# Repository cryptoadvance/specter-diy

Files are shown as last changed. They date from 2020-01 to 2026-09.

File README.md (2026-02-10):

# Specter-DIY

    "Cypherpunks write code. We know that someone has to write software to defend privacy, 
    and since we can't get privacy unless we all do, we're going to write it."
    A Cypherpunk's Manifesto - Eric Hughes - 9 March 1993

    ...and Cypherpunks do build their own Bitcoin Hardware Wallets.

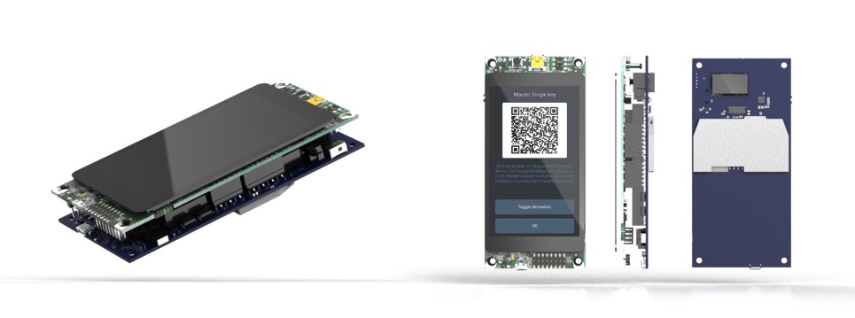
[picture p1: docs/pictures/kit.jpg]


The idea of the project is to build a hardware wallet from off-the-shelf components.
Even though we have [an extension board](./shield) that puts everything in a nice form-factor and helps you to avoid any soldering, we will continue supporting and maintaining compatibility with standard components.

We also want to keep the project flexible such that it can work on any other set of components with minimal changes. Maybe you want to make a hardware wallet on a different architecture (RISC-V?), with an audio modem as a communication channel - you should be able to do it. It should be easy to add or change functionality of Specter and we try to abstract logical modules as much as we can.

QR codes are a default way for Specter to communicate with the host. QR codes are pretty convenient and allow the user to be in control of the data transmission - every QR code has a very limited capacity and communication happens unidirectionally. And it's airgapped - you don't need to connect the wallet to the computer at any time.

For secret storage we support agnostic mode (wallet forgets all secrets when turned off), reckless mode (stores secrets in flash of the application microcontroller) and secure element integration is coming soon.

Our main focus is multisignature setup with other hardware wallets, but wallet can also work as a single signer. We try to make it compatible with Bitcoin Core where we can - PSBT for unsigned transactions, wallet descriptors for importing/exporting multisig wallets. To communicate with Bitcoin Core easier we are also working on [Specter Desktop app](https://github.com/cryptoadvance/specter-desktop) - a small python flask server talking to your Bitcoin Core node.

Most of the firmware is written in MicroPython which makes the code easy to audit and change. We use [secp256k1](https://github.com/bitcoin-core/secp256k1) library from Bitcoin Core for elliptic curve calculations and [LVGL](https://lvgl.io/) library for GUI.

## DISCLAIMER

The project has significantly matured, to the extent that the security level of Specter-DIY is now comparable to commercial hardware wallets on the market. We implemented a secure bootloader that verifies firmware upgrades, so you can be sure that only signed firmware can be uploaded to the device after initial setup. However, unlike with commercial signing devices the bootloader has to be installed manually by the user and is not set in the factory of the device vendor. Thus, pay extra attention during the initial firmware installation and make sure you verified PGP signatures and flash the firmware from a secure computer.

If something doesn't work open an issue here or ask a question in our [Telegram group](https://t.me/+VEinVSYkW5TUl5Ai).

## Documentation

All the docs are stored in the [`docs/`](./docs) folder:

- [`shopping.md`](./docs/shopping.md) explains what to buy
- [`assembly.md`](./docs/assembly.md) shows how to put everything together.
- [`quickstart.md`](./docs/quickstart.md) guides you through the initial steps how to get firmware on the board
- [`reproducible-build.md`](./docs/reproducible-build.md) describes how to build the initial firmware and upgrade files with the same hash as in the release using Docker
- [`build.md`](./docs/build.md) describes how to build the firmware and the simulator yourself
- [`security.md`](./docs/security.md) explains possible attack vectors and security model of the project
- [`development.md`](./docs/development.md) explains how to start developing on Specter
- [`simulator.md`](./docs/simulator.md) shows how to run a simulator on unix/macOS
- [`communication.md`](./docs/communication.md) defines communication protocol with the host over QR codes and USB
- [`roadmap.md`](./docs/roadmap.md) explains what we need to implement before we can consider the wallet be ready to use with real funds.

Specter-Shield documentation and all the files are available in the [`shield/`](./shield) folder:

- [What it looks like](./shield/README.md)
- [How to print a 3d case](./shield/3dprinting.md)

Specter Shield-Lite documentation is available in the [`shield-lite/`](./shield-lite) folder:

- [Specter Shield-Lite overview](./shield-lite/readme.md)

Supported networks: Mainnet, Testnet, Regtest, Signet.

## Running tests

The unit test suite runs on the Unix simulator build. Install the required
system packages and then run the `make` target:

```
sudo apt-get update
sudo apt-get install libsdl2-dev libffi-dev pkg-config libreadline-dev libgmp-dev build-essential python3
make test
```

The build system will fetch the necessary submodules and compile the simulator
before executing the tests.

## USB communication on Linux

You may need to set up udev rules and add yourself to `dialout` group. Read more in [`udev`](./udev/README.md) folder.

## Video and screenshots

Check out [this video](https://www.youtube.com/watch?v=1H7FqG_FmCw) to get an idea how to assemble it and how it works.

Here is a [Gallery](./docs/pictures/gallery/README.md) with devices assembled by the community.

A few pictures of the UI:

### Wallet screens

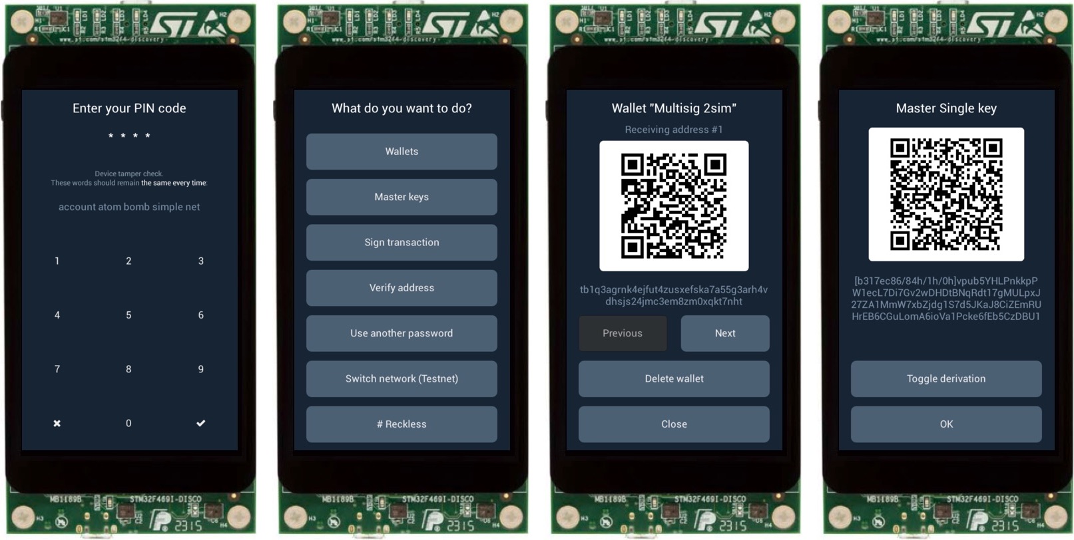
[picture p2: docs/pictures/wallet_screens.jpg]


### Key generation and recovery

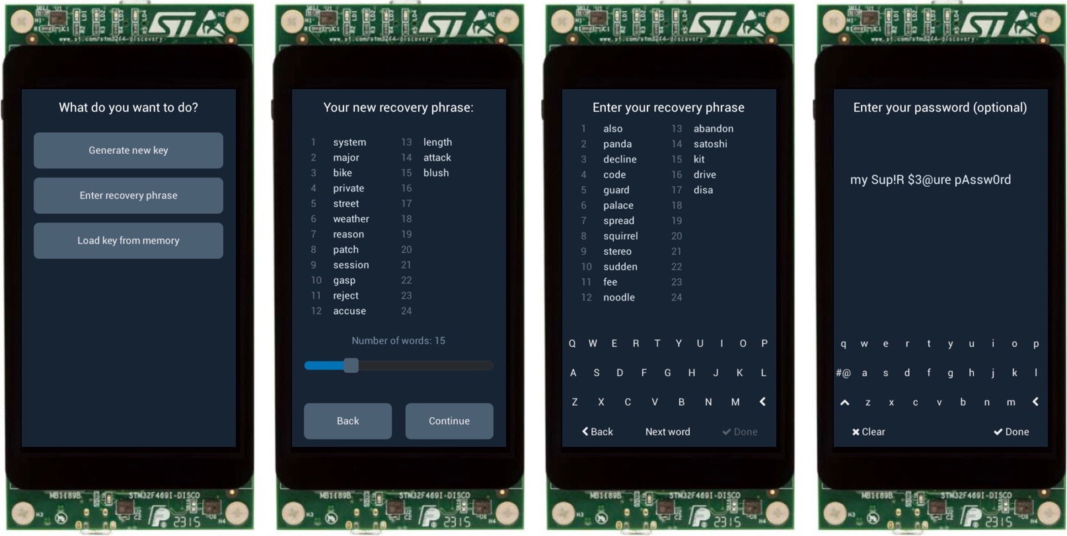
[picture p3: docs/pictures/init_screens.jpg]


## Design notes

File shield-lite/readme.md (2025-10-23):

# Specter Shield Lite (Work in Progress)

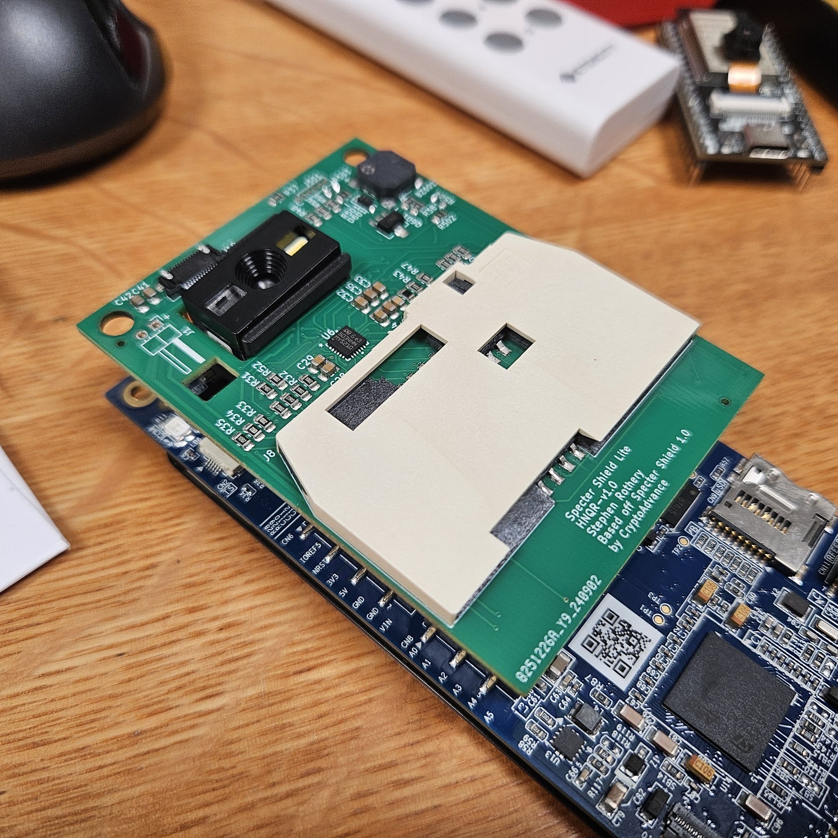
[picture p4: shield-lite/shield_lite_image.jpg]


## Background
Limited availability and high cost have limited the accesibility of the Smartcard based functionality in Specter.

## The Specter Shield-Lite aims to:
+ Implement the QR and Smartcard functionality of the Specter Shield, at a price that is comparable to using the Waveshare QR Scanner for Specter DIY.
+ Preserve the form factor of the Shield to allow re-use of existing cases.
+ Optimise the PCB design and component selection for low cost, short-run production where full hand-assembly is also practical with a standard soldering iron if desired. 
+ Not worry about an integrated battery, but expose the VIN pin so that the user can supply 6-9DC if they want, or just power over USB.
+ Use FOSS design tools (KiCad) to make it easier for others to contribute to the project

## Design Decisions to keep costs low
+ PCB Size - Exceeding 10cm in either dimension typically results in increased costs with most PCB production houses
+ 2 Layer PCB - Double sided PCBs are extremly cheap when compared to 4 layer boards. This is also a fairly simple board, so 2 layer is fine.
+ Keeping all drilled hole sizes above 0.3mm... The existing Shield has a handful (~6) of 0.2mm holes which dramatically increases the production cost.
+ Single Sided Components - Fab houses like JLCPCB have extremely cheap assembly services as long as all components are on a single side of the PCB. (The Pin-Headers are easy to hand solder on)
+ Sticking to common/cheap components where possible, as opposed to more exotic/complex parts. (Minimise 'Extended' parts from fabs like JLCPCB, prefer pin-count <= 16 for fabs like PCBWay)

## Future Work (Still in testing)
+ Swap SmartCard interface IC to something like ST8034ATDT to make it easier to assemble by hand, decreases component count and makes assembly cheaply by PCBWay. (Current QFP package makes assembly expensive with PCBWay, though still cheap with JLCPCB)
+ Look at alternative QR Scanners like the Grow GM805 which are cheaper, remove the need for fine pitch header soldering and also integrate the beeper, to futher drive costs down. (Currently has some compatability issues with binary SeedQR which need to be explored/fixed)

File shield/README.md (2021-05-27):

# Specter Shield

Specter shield is an extension board for F469-Discovery board by STMicroelectronics. It uses a standard Arduino headers so it might work with other boards with Arduino headers as well.

It includes a QR scanner, smartcard slot and a battery. All elements are not security-critical - QR scanner only captures images and sends scanned data to the main MCU over dead-simple serial interface, smartcard controller learns nothing about the data transmitted to the secure element as communication with it is encrypted.

Structure diagram, pinout and schematics are available in this folder and on [circuitmaker](https://circuitmaker.com/Projects/Details/MikhailTolkachev/specter-shield). To manufacture the kit yourself just send the content of the [`specter-shield`](./specter-shield/) folder to the PCB manufacturer.

For the QR scanner we use GROW GM65-S scanner.

Available in [our shop](https://specter.solutions/shop/specter-shield/). Assembled kit look like this:

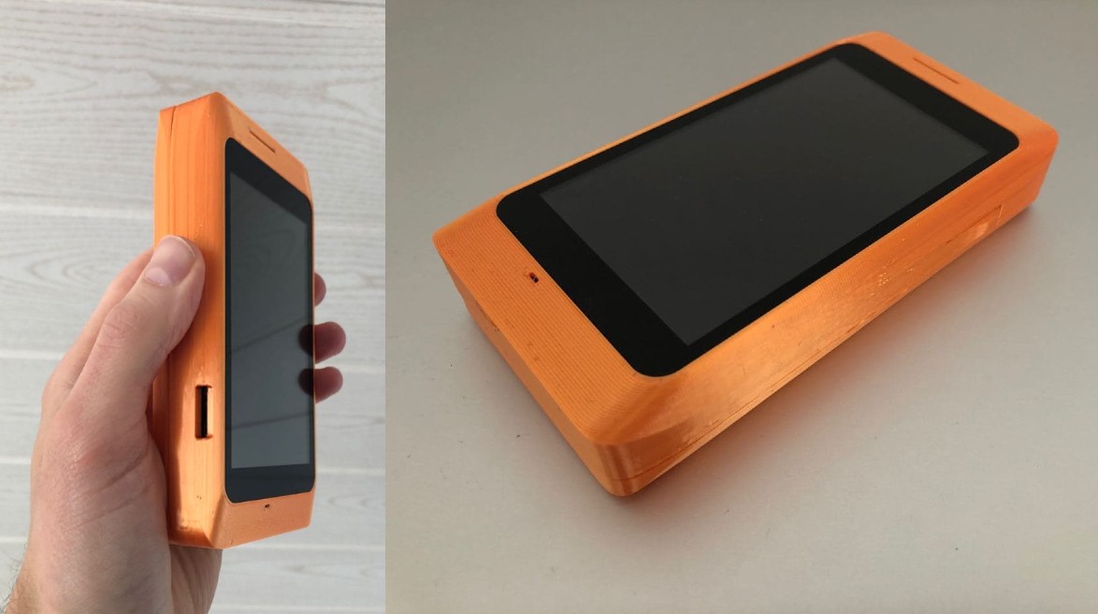
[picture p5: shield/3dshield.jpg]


## Print the case for Specter-DIY + Shield:

- Design by @geometrick-design: https://www.thingiverse.com/thing:4671552, [instructions](3dprinting.md)
- Design by @SeedSigner: https://www.thingiverse.com/thing:4733846, [files and instructions](./Alternative_3D_Printed_Case)

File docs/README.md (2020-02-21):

# Documentation

## Table of contents

- [`shopping.md`](./shopping.md) explains what to buy
- [`assembly.md`](./assembly.md) shows how to put everything together.
- [`quickstart.md`](./quickstart.md) guides you through the initial steps how to get firmware on the board
- [`security.md`](./security.md) explains possible attack vectors and security model of the project
- [`development.md`](./development.md) explains how to start developing on Specter
- [`simulator.md`](./simulator.md) shows how to run a simulator on unix/macOS
- [`communication.md`](./communication.md) defines communication protocol with the host over QR codes and USB
- [`roadmap.md`](./roadmap.md) explains what we need to implement before we can consider the wallet be ready to use with real funds.

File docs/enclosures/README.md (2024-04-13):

# Enclosures for Specter-DIY

There are a few case designs made by the community:

## Specter-DIY Snap Case

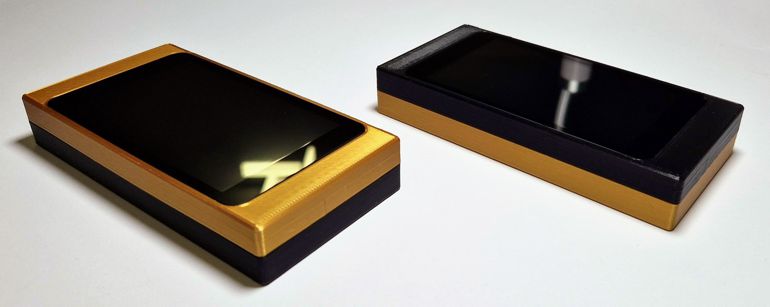
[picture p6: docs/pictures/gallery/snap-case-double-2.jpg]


Print it yourself enclosure with the waveshare scanner on the backside. 

The printable STL files are available for download in the [snapcase](./snapcase/) folder.

Please note that the prints are quite tight around the hardware components. They are well tested with a Prusa MK3s and Specter hardware components from late 2022. Other printers or newer or older hardware may produce results that do not fit. Please check carefully that the prints do not exert pressure on any hardware components and don't exert any pressure yourself. 

Contact me if you have any questions or suggestions. Success stories are also very welcome. :) You can reach me on [X (@kayth21)](https://x.com/kayth21) or on [Telegram (@kayth_21)](https://t.me/kayth_21).

You can also buy a Snap Case, or a fully assembled Specter-DIY, from [bitcoin-store.org](https://bitcoin-store.org).

## SeedSigner's "Barebones" enclosure, v2

Updated design from @SeedSigner (Twitter/Telegram) with a smaller form factor & MicroSD access.

The printable .STL files for v1 and v2 are available for download from the [docs/enclosures/seedsigner](./seedsigner/) folder.

You can also buy the v2, or a fully assembled Specter-DIY, from [his shop](https://btc-hardware-solutions.square.site/).

(E.U. residents can contact @surfacePlasmon (Twitter) or @daz21 (Telegram) to purchase an enclosure via mail or visit diynodes.com)

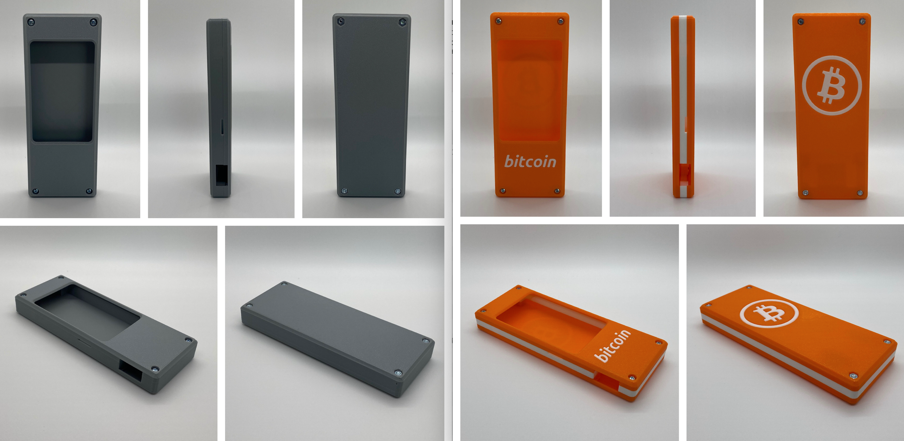
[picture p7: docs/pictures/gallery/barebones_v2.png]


## Full metal DIY

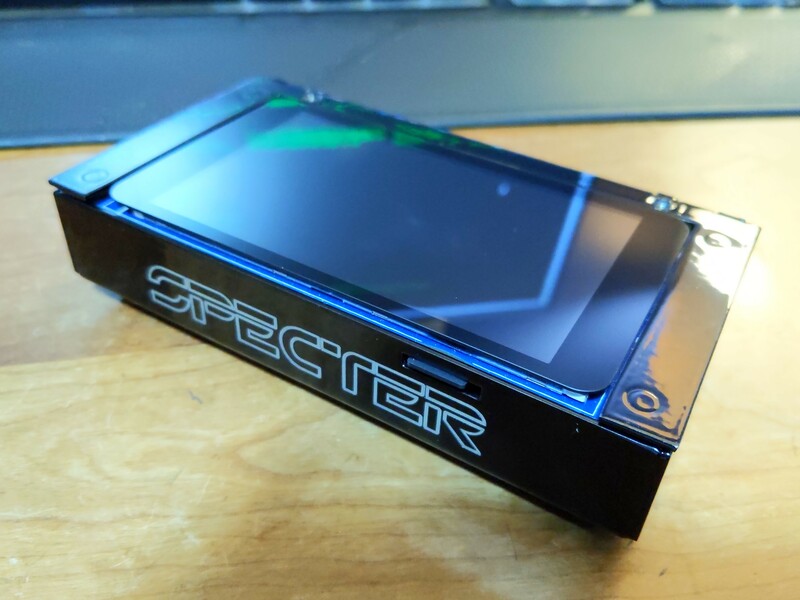
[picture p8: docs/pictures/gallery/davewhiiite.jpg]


https://github.com/davewhiiite/wraith

## Enclosure by Thomas

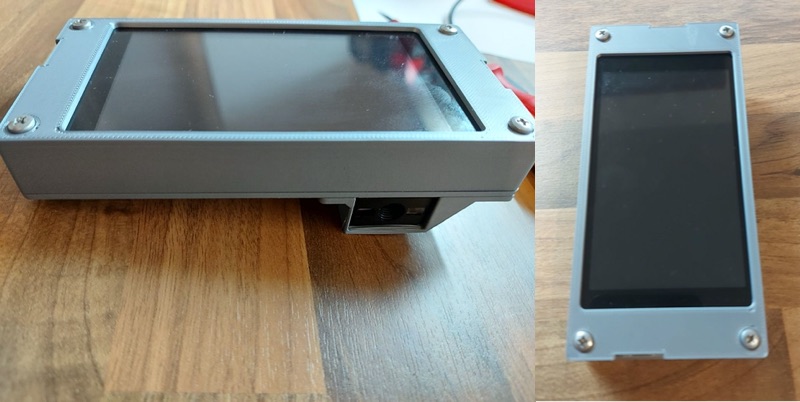
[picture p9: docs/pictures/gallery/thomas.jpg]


[3d files](./thomas)

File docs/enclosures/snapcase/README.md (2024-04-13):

# Specter-DIY Snap Case

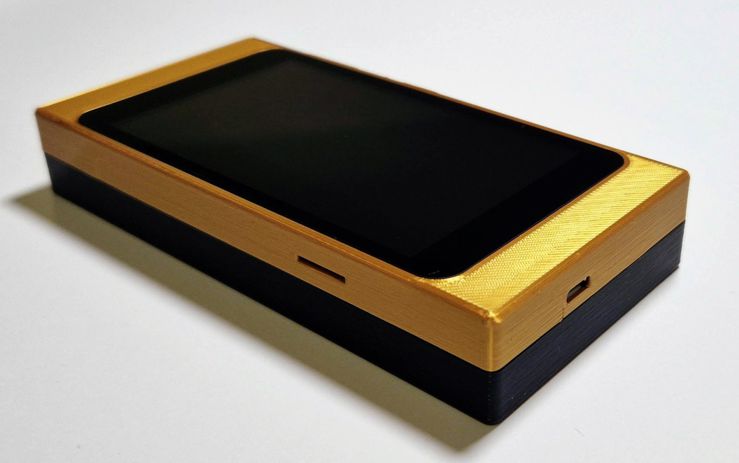
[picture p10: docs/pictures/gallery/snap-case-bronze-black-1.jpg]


Specter-DIY Snap Case is a print it yourself enclosure with the waveshare scanner on the backside. It consists of a scanner part, in which the scanner is held and the cables are fixed, and a frontside and a backside part, which can be plugged together. 

## Please note

The prints are quite tight around the hardware components. They are well tested with a Prusa MK3s and Specter hardware components from late 2022. Other printers or newer or older hardware may produce results that do not fit. Please check carefully that the prints do not exert pressure on any hardware components and don't exert any pressure yourself. 

## Assembly

Please note that this manual assumes that you are familiar with the basic assembly of a Specter-DIY and therefore only addresses the specialties associated with this case. If not, please head over to the [docs](../../).

### Print all the parts

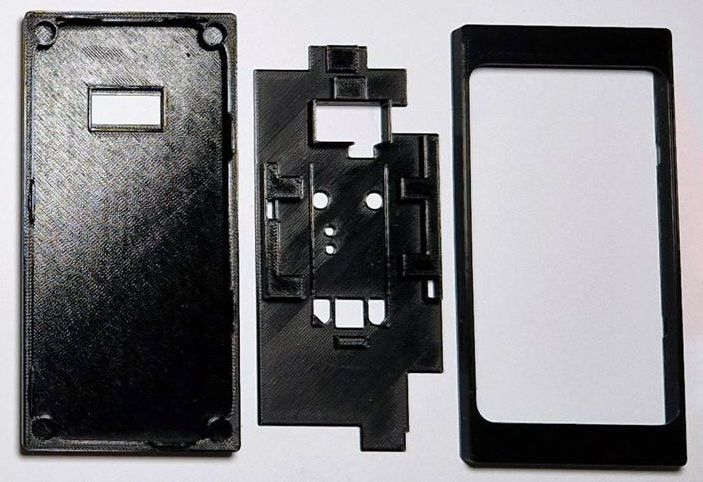
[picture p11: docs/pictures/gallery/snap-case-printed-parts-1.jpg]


- The SDL files are attached to this site. 

### Remove all screws from the scanner

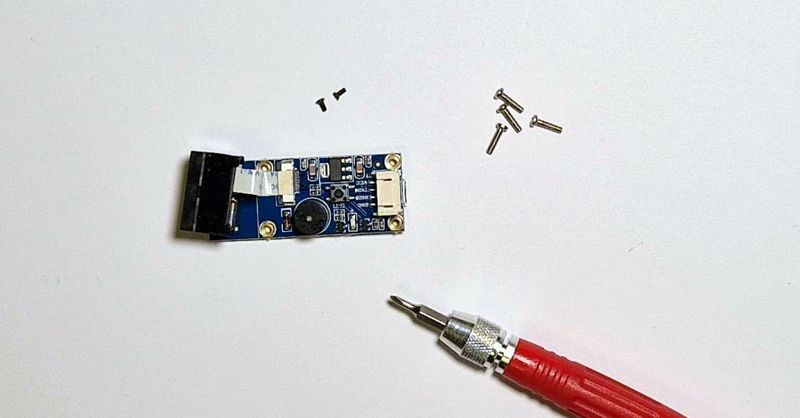
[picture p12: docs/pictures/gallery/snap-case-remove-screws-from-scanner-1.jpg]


### Mount the scanner module

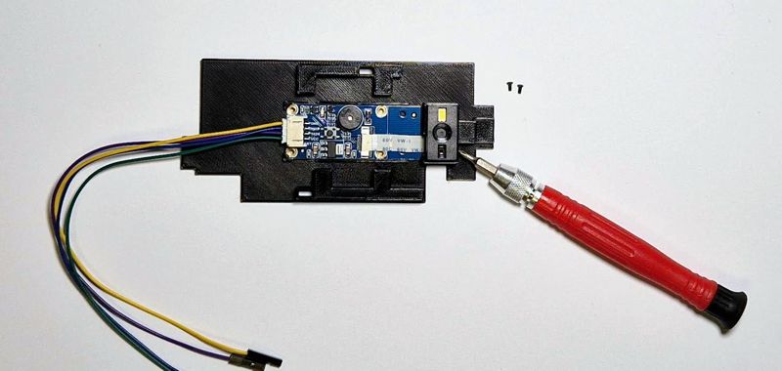
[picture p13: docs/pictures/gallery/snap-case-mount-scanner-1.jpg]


- Use the two small screws to lock the scanner in the designated position.

### Connect the scanner to the board

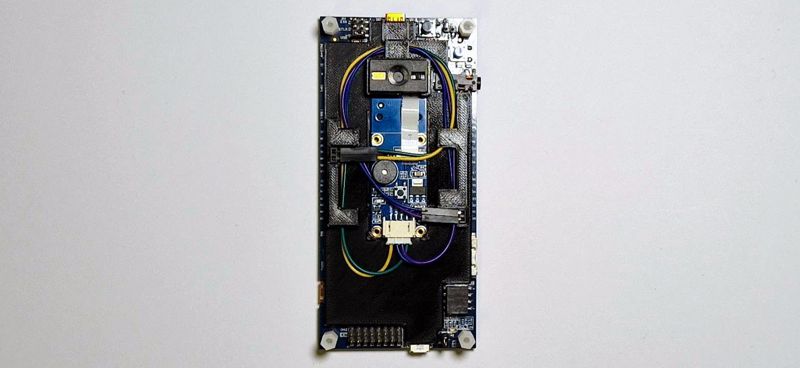
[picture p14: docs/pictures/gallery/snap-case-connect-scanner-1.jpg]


- Place the middle part on the board.
- Slide the cables through the channels.
- Connect the cables through the pins to the corresponding slots.

### Plug together the case

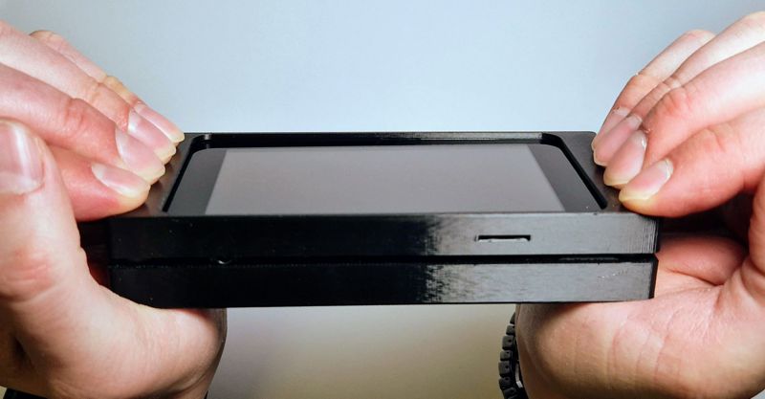
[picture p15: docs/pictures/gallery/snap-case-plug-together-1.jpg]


- Please double check that the parts are right side up.
- Because of the snaps, you need a little pressure to put them together. Before you put them together, please make sure that the top part fits well over the display.

## Contact

Contact me if you have any questions or suggestions. Success stories are also very welcome. :) You can reach me on [X (@kayth21)](https://x.com/kayth21) or on [Telegram (@kayth_21)](https://t.me/kayth_21).

## Shop

You can also buy a Snap Case, or a fully assembled Specter-DIY, from [bitcoin-store.org](https://bitcoin-store.org).

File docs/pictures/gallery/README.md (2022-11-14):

# Gallery

Here are a few pictures from people who assembled their own Specter.

If you did it as well we will be happy to put it here.

### @kayth21

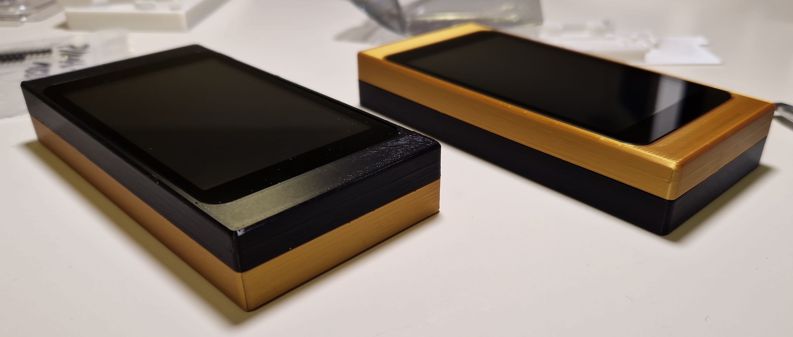
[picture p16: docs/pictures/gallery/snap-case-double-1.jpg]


Created with a Prusa MK3s using the template from [enclosures/snapcase](../../enclosures/snapcase).

### @davewhiiite

davewhiiite

### @seedsigner

seedsigner

### @lunaticoin

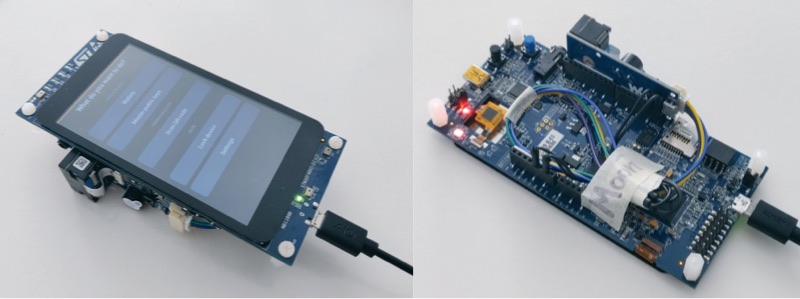
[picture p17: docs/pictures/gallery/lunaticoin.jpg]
lunaticoin


### @Thomas1378

thomas

### @bitcoinheiro

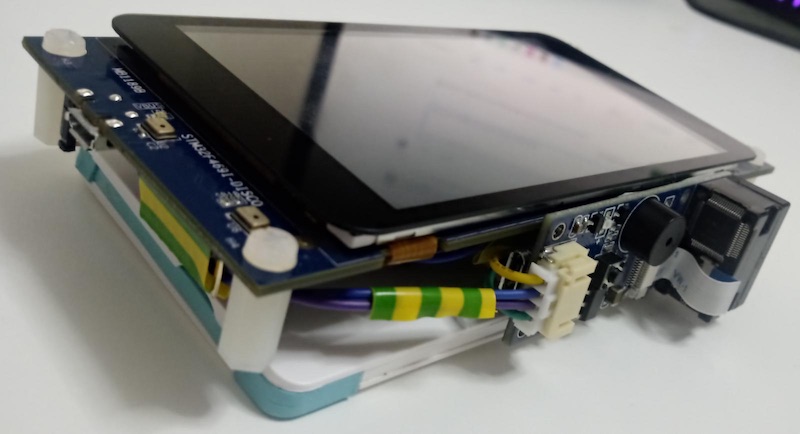
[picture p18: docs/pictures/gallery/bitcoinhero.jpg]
bitcoinhero


Created 3d printed storage box for this setup with small battery attached and waveshare scanner on the side. Available at https://www.tinkercad.com/things/46xyXAhv0Fy

### @kkdao

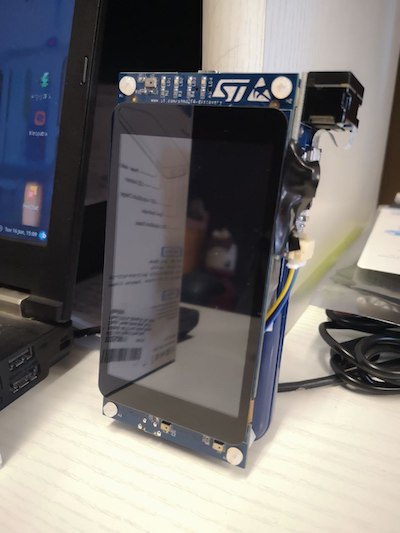
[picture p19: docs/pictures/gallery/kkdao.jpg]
kkdao


### @dimaatmelodromru

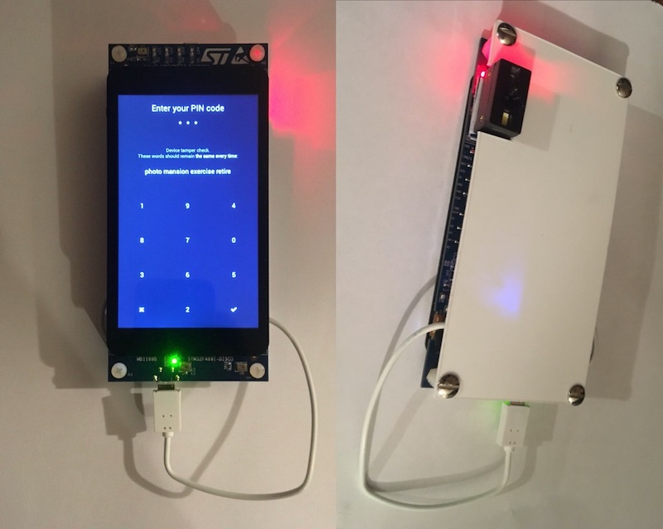
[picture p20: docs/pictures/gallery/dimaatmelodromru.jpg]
dimaatmelodromru


### @k9ert

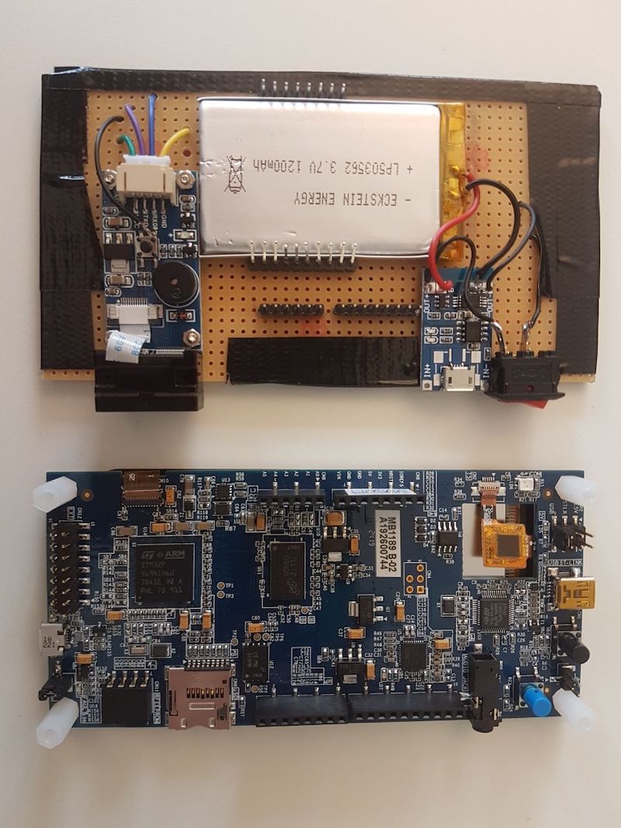
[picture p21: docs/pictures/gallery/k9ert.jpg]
k9ert


### @gorazdko

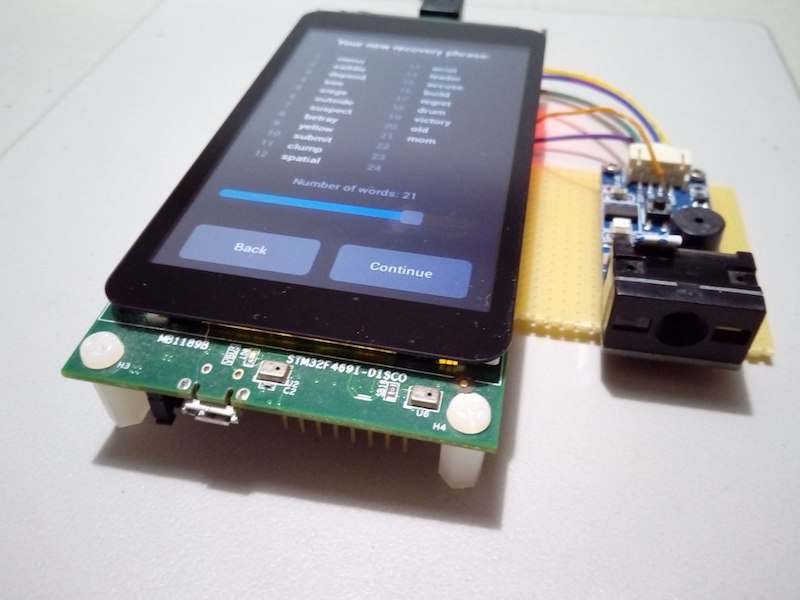
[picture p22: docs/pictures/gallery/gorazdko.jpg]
gorazdko


### @bavarianledger

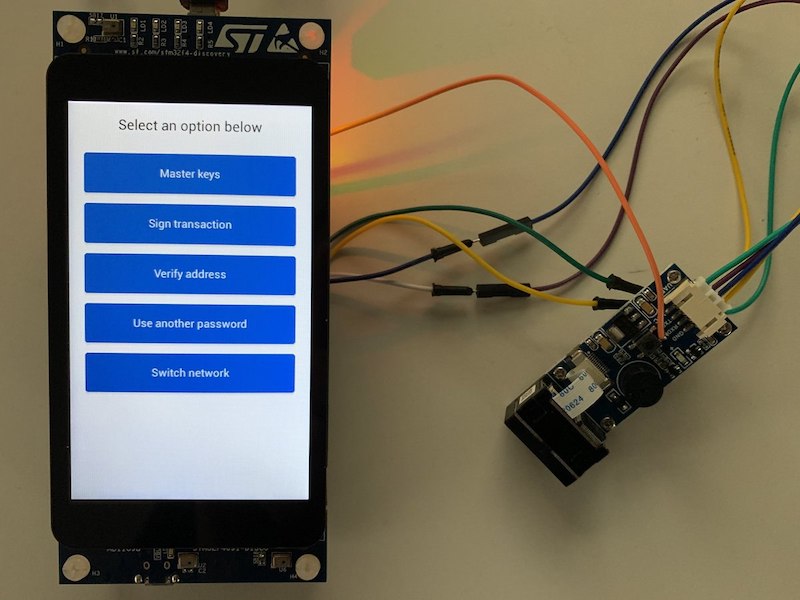
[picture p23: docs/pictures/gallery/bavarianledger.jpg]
bavarianledger


### @kdmukai

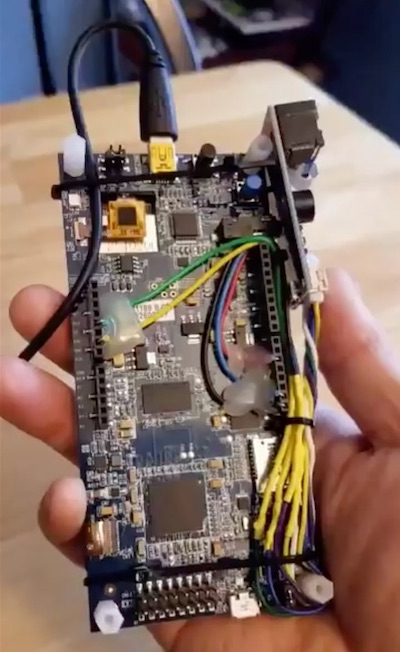
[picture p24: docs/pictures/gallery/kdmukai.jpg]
kdmukai


### @stepansnigirev

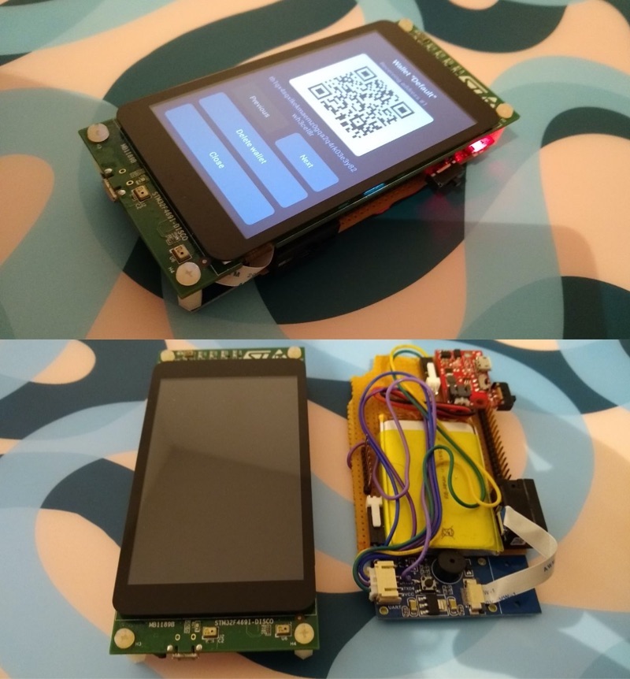
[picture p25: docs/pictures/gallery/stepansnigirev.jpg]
stepansnigirev


### @davewhiiite

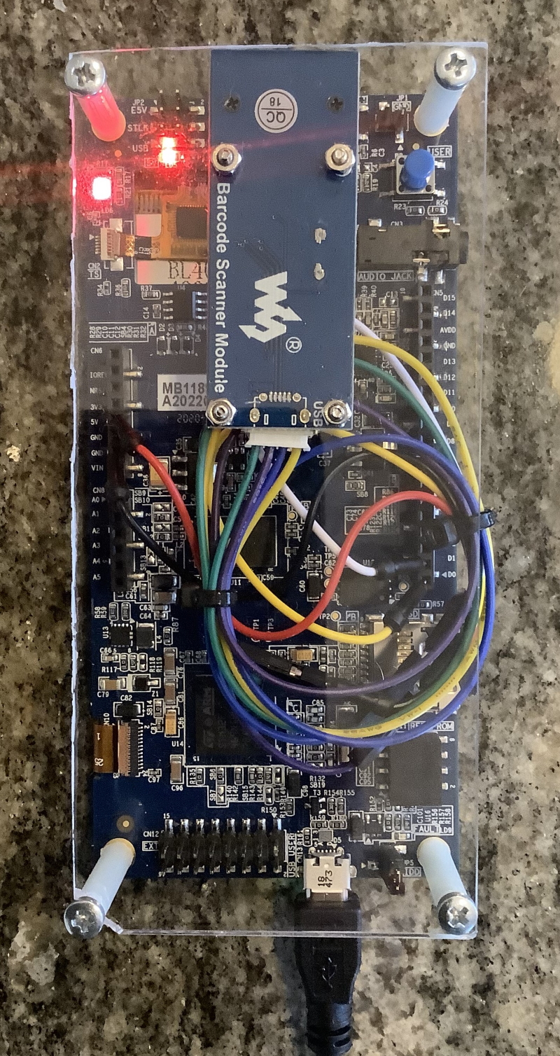
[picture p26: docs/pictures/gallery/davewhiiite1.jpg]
davewhiiite

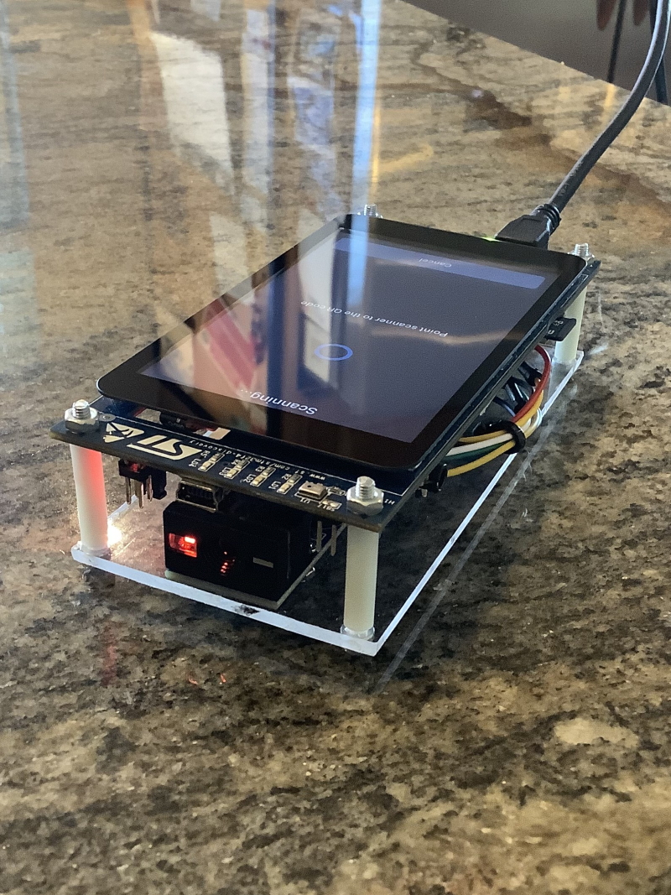
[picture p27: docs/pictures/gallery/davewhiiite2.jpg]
davewhiiite

davewhiiite

### Re-use the original packaging of the STM32F469I-DISCO @henrik
henrik
henrik
henrik

### @you?

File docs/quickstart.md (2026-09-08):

# Installing the compiled code

With the secure bootloader initial installation of the firmware is slightly different. Upgrades are easier and don't require to connect hardware wallet to the computer.

## Flashing initial firmware

**Note** If you don't want to use binaries from the releases check out the [bootloader documentation](https://github.com/cryptoadvance/specter-bootloader/blob/master/doc/selfsigned.md) that explains how to compile and configure it to use your public keys instead of ours.

- If you are upgrading from versions below `1.4.0` or uploading the firmware for the first time, use the `initial_firmware_<version>.bin` from the [releases](https://github.com/cryptoadvance/specter-diy/releases) page.
	- Verify the signature of the `sha256.signed.txt` file. The signing key varies by release, see the release notes; as of v1.10.5 it is signed by Mike Tolkachev (@miketlk), fingerprint `F2DB C4C6 14C1 13E2 B15F 879A DD5C 1264 EBD6 45BE`, key at [github.com/miketlk.gpg](https://github.com/miketlk.gpg) (see [SECURITY.md](https://github.com/cryptoadvance/specter-diy/blob/master/SECURITY.md)). v1.10.3–v1.10.4 used the **"Specter Signer 2026"** key, controlled by k9ert (fingerprint `9DC3 3CA8 3058 9DE3 B322 5C26 EEF5 756B 2EA4 2349`, [Ubuntu keyserver](http://keyserver.ubuntu.com/pks/lookup?op=get&search=0x9dc33ca830589de3b3225c26eef5756b2ea42349)). Older releases were signed with [Stepan's PGP key](https://stepansnigirev.com/ss-specter-release.asc)
	- Verify the hash of the `initial_firmware_<version>.bin` against the hash stored in the `sha256.signed.txt`
- If you are upgrading from an empty bootloader or you see the bootloader error message that firmware is not valid, check out the next section - [Flashing signed Specter firmware](#flashing-signed-specter-firmware).
- Make sure the [power jumper](./assembly.md) of your discovery board is at STLK position
- Connect the discovery board to your computer via the **miniUSB** cable on the top of the board.
    - The board should appear as a removable disk named `DIS_F469NI`.
- Copy the `initial_firmware_<version>.bin` file into the root of the `DIS_F469NI` filesystem.
- When the board is done flashing the firmware the board will reset itself and reboot to the bootloader. Bootloader will check the firmware and boot into the main firmware. If see an error message that no firmware is found - follow the update instructions and upload firmware via SD card.
- Now you can switch the power jumper where you like it and power the board from the powerbank or battery.

> Flashing initial firmware via copy-paste of the `.bin` file sometimes fails - often because of the cable, or if you connect the device through a USB hub. In this case you can try a few more times (normally works in 2-3 attempts).
> 
> If it fails all the time you can use [stlink](https://github.com/stlink-org/stlink/releases/latest) open-source tool. Install it and type in your terminal: `st-flash write <path/to/initial_firmare.bin> 0x8000000`. It usually works much more reliable.

## Upgrading firmware

- Download the `specter_upgrade_<version>.bin` from the [releases](https://github.com/cryptoadvance/specter-diy/releases).
- Copy this binary to the root of the SD card (FAT-formatted, 32 GB max)
	- Make sure only one `specter_upgrade***.bin` file is in the root directory
- Insert SD card to the SD slot of the discovery board and power on the board
- Bootloader will flash the firmware and will notify you when it's done.
- Reboot the board - you will see Specter-DIY interface now, it will suggest you to select your PIN code

Whenever a new release is out just download the `specter_upgrade_<version>.bin` from the releases, drop it to the SD card and upgrade the device just like in the previous step. Bootloader will make sure only signed firmware can be loaded to the board.

## How to find out firmware version

Go to the `Device settings` menu - it will show the version number under the title of the screen.

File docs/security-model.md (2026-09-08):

# Security of Specter-DIY

This document explains the security model of Specter-DIY: what the device
protects against, what it explicitly does NOT protect against, and which
mechanisms implement these guarantees.

## Threat model

Specter-DIY is designed to protect your keys against:

- **A compromised host computer.** The host only ever sees public data
  (xpubs, descriptors, unsigned PSBTs) and signatures. Private keys never
  leave the device. All critical information (receive addresses, amounts,
  change outputs) is shown on the device screen for user verification.
- **A thief with the locked device.** Stored secrets are encrypted with a
  key derived from your PIN and a unique internal device secret. The PIN
  is rate-limited (see below), so brute-forcing it on the device is
  impractical.
- **A device swap / evil maid after setup.** The anti-phishing words shown
  during PIN entry change if the internal secret is gone — i.e. if the
  device was replaced or its firmware was reflashed without the locked
  bootloader.
- **Malicious firmware upgrades.** After the initial installation the
  secure bootloader only accepts firmware signed by the release keys (or
  your own keys if you use a self-signed bootloader).

Explicitly **out of scope**:

- **Physical attacks with lab equipment** (chip decapsulation, power/EM
  side-channel analysis, glitching) against the main MCU. Without the
  smartcard, secrets live in the application MCU. If this threat matters
  to you, use the smartcard storage mode or don't store the key on the
  device at all (temporary seed mode).
- **Compromised hardware before first use** (supply chain). Buy components
  from reputable sources and inspect the device. The anti-phishing words
  only protect you *after* you have set up the device.
- **The QR scanner's own firmware.** The scanner module only forwards
  decoded data to the main MCU, which treats it as untrusted input, but a
  malicious scanner could feed you crafted QR codes. Physical inspection
  and buying from reputable sources apply here as well.

## Hardware

Display is controlled by the application MCU.

The device uses external flash (QSPI) to store wallet files (descriptors,
wallet metadata, settings). These files are encrypted and authenticated
(AES-CBC + HMAC-SHA256, encrypt-then-MAC) with a key derived from your
seed at `m/0x1D'` — so a flash dump alone reveals neither your xpubs nor
your wallet structure, and tampering with the files is detected when they
are loaded.

QR scanning functionality runs on a separate scanner module, so all image
processing happens outside of the security-critical MCU. USB and SD card
are managed by the main MCU — avoid them if you want to reduce the attack
surface (USB is off by default, see "Communication channels" below).

For a complete list of what data the device persists, where it is stored
and how it is protected, see [`data-storage.md`](./data-storage.md).

## Firmware verification

Specter-DIY uses a dedicated secure bootloader — the
[specter-bootloader](https://github.com/cryptoadvance/specter-bootloader)
project, included in this repo as the `bootloader/` submodule and
specified in
[`doc/bootloader-spec.md`](https://github.com/cryptoadvance/specter-bootloader/blob/master/doc/bootloader-spec.md).
After the initial installation, the device only accepts signed firmware:

- Upgrades arrive on an SD card as a single `specter_upgrade*.bin` file.
  The bootloader verifies ECDSA signatures (secp256k1, SHA-256,
  Bitcoin-message-style over a bech32-encoded payload hash) **after**
  copying the payload to internal flash — data is read back from flash,
  not from the removable SD card.
- **Multisignature with configurable thresholds** is supported. There is
  a key hierarchy: *vendor keys* can sign the bootloader and the main
  firmware, *maintainer keys* can sign the main firmware only. Keys are
  added and compromised keys are revoked by releasing a new bootloader.
- **Downgrades are prohibited** — a version check record stores the
  latest version ever programmed to the device, for both the bootloader
  and the main firmware.
- The bootloader itself consists of a tiny **non-upgradable start-up
  code** plus **two redundant bootloader copies**; on every boot the
  start-up code integrity-checks both copies and runs the newest intact
  one. On every normal boot the main firmware's integrity record is
  verified as well.

The **initial** installation is the trust-critical step, because the
bootloader is not installed at the factory — you flash it yourself:

1. Verify the PGP signature of `sha256.signed.txt`. The signing key varies
   by release — check the release notes for which one applies:
   - **v1.10.5**: Mike Tolkachev (@miketlk), fingerprint
     `F2DB C4C6 14C1 13E2 B15F 879A DD5C 1264 EBD6 45BE`, key at
     <https://github.com/miketlk.gpg> (also listed in
     [SECURITY.md](https://github.com/cryptoadvance/specter-diy/blob/master/SECURITY.md)).
   - **v1.10.3–v1.10.4**: the **"Specter Signer 2026"** key, controlled by
     k9ert (fingerprint `9DC3 3CA8 3058 9DE3 B322 5C26 EEF5 756B 2EA4 2349`,
     available from the
     [Ubuntu keyserver](http://keyserver.ubuntu.com/pks/lookup?op=get&search=0x9dc33ca830589de3b3225c26eef5756b2ea42349)).
   - **Older releases**: [Stepan's release
     key](https://stepansnigirev.com/ss-specter-release.asc).
2. Verify the hash of `initial_firmware_<version>.bin` against the signed
   hash file.
3. Flash from a computer you trust.

Note that v1.10.3 is also a real-world example of the key rotation
described above: it ships a bootloader with a new vendor key set, and
devices on v1.9.0 or earlier must install it before they can accept any
later upgrades.

See [`quickstart.md`](./quickstart.md) for the full procedure. The
firmware is [reproducible](./reproducible-build.md), so you can verify
that release binaries match the published source code. And if you don't
want to trust the release keys at all, you can build the bootloader with
**your own public keys** and sign upgrades yourself — the signing message
is a standard Bitcoin signed message, so most hardware wallets can do it
([`doc/selfsigned.md`](https://github.com/cryptoadvance/specter-bootloader/blob/master/doc/selfsigned.md)).

### Readout and write protection

The bootloader can be built with flash protection enabled
(`READ_PROTECTION=1 WRITE_PROTECTION=1`, see the bootloader
[README](https://github.com/cryptoadvance/specter-bootloader#readme)):

- **RDP Level 1** blocks external readout of the internal flash. An
  attacker can still erase the chip via JTAG/SWD — but that also erases
  the internal secret, so the manipulation is visible to you: the
  anti-phishing words shown at PIN entry will be different.
- **RDP Level 2** disables JTAG/SWD completely and is **irreversible** —
  the board can never be debugged or unbricked via SWD again. It is
  therefore blocked by default and requires a manual source code change
  to enable. Think twice.
- **Write protection** protects the flash sectors of the start-up code,
  the bootloader and the main firmware against modification.

Removing the protection afterwards (see
[`doc/remove_protection.md`](https://github.com/cryptoadvance/specter-bootloader/blob/master/doc/remove_protection.md))
always wipes the entire flash, including the internal secret.

## PIN protection (user authentication)

During the first boot a unique secret is generated on the main MCU. This
secret is stored unencrypted in the internal flash
(`/flash/keystore/secret`) — its confidentiality relies entirely on the
MCU's readout protection (see "Readout and write protection"). It allows
you to verify that the device was not replaced by a malicious one — when
you enter the PIN code you see a list of words that remains the same
while the secret is there.

Your PIN together with this unique secret is used to generate the
decryption key for your Bitcoin keys (if you store them). So even if an
attacker bypasses the PIN screen, decryption still fails.

The unencrypted secret is, however, the weak point to be aware of: if an
attacker manages to read the internal flash — which is exactly what the
readout protection is designed to prevent — they obtain the device
secret together with the PIN file. That enables two follow-up attacks:
brute-forcing your PIN **offline** at full speed (the 10-attempt limit
no longer applies), and **cloning the anti-phishing words** onto a
malicious device so it *looks* like your device. With RDP enabled this
scenario is blocked: the attacker can only erase the chip, which
destroys the secret and is visible to you. This is why we recommend
enabling readout protection (see "Readout and write protection").

Brute-force protection is enforced on the device:

- At most **10 PIN attempts** are allowed; afterwards the device wipes
  itself. Note: in the current implementation the attempt counter is
  decremented and persisted *before* the PIN is checked, so the 10th
  attempt already triggers the wipe without verifying the PIN first —
  effectively 9 verification attempts instead of the intended 10 (fail-safe
  direction; a correct PIN entered on the 10th attempt still wipes).
- The PIN check is an HMAC keyed with the internal secret, so the PIN
  cannot be brute-forced offline from flash contents alone.
- The PIN state file is authenticated; tampering with it triggers a wipe
  as well.
- The wipe erases the internal flash of the MCU — it does **not** erase
  the smartcard. The card relies on its own attempt counter and bricks
  itself when exhausted. Note that if the card holds the secret in
  encrypted form, wiping the device makes the card's data permanently
  inaccessible anyway, because the card-encryption key is derived from
  the device secret that was just destroyed.

Two more properties of the PIN check are worth knowing:

- **There is no key stretching.** Deriving keys from the PIN costs a
  single SHA-256. On the device this is fine — the attempt limit stops
  online guessing. But if an attacker reads out the internal flash (the
  exact thing readout protection is meant to prevent), the attempt limit
  no longer applies and PINs can be tried offline at full hardware speed:
  a 4-digit PIN falls in milliseconds, a 6-digit PIN in seconds.
- **There is no time-based delay** between attempts. The persistent,
  fail-closed attempt counter is the only rate limit — it cannot be reset
  by power-cycling the device.

**Choose a long PIN.** Because offline brute-force is the realistic worst
case (flash readout without RDP), do not rely on the 10-attempt limit
alone: use 8 or more digits. "1234"-style PINs are unacceptable, and even
6 digits offer little resistance against an offline attack.

## Secret storage modes

Specter-DIY supports three storage modes:

- **Temporary seed mode** — **recommended.** The device stores no
  private keys: your recovery phrase lives only in RAM and is gone at
  power-off, so there is no secret to extract from a stolen device.
  Note that non-secret data still persists: the device secret, PIN
  state, settings, and any wallet descriptors you imported — and those
  descriptors contain your xpubs. Wallet data is encrypted with a key
  derived from your seed (at `m/0x1D'`), so it stays unreadable until
  you re-enter the phrase, but its presence on the flash is visible.
- **Smartcard** (requires a Specter Shield / Shield-Lite with smartcard
  slot and a JavaCard) — **recommended.** The secret is stored on a
  PIN-protected smartcard and only moved to the MCU's RAM when unlocked.
  The seed never touches the MCU's internal flash, so even a complete
  readout of the MCU reveals nothing about your key; and the card, as a
  dedicated secure element, is built to resist exactly the physical
  attacks that are out of scope for the main MCU. Communication between
  the MCU and the card runs over an encrypted secure channel, the card
  itself enforces the PIN attempt limit in hardware and bricks when it
  is exhausted, and the anti-phishing words are derived from both the
  internal device secret and the card's public key — so you detect if
  either the device or the card was swapped. You can store the secret
  on the card either encrypted (bound to this device) or as plaintext
  (portable to any Specter-DIY after PIN entry).
- **Internal flash ("reckless" mode)** — **not recommended for real
  funds.** The mnemonic is stored encrypted and authenticated in the
  flash of the main MCU (AES-CBC + HMAC-SHA256, encrypt-then-MAC — the
  same construction as for wallet files), with a key derived from your
  PIN and the internal device secret, and it is protected by the PIN
  attempt limit described above.
  But this is fundamentally a software-only barrier: the main MCU is not
  a secure element, and a sufficiently equipped attacker with physical
  access should be considered able to extract the flash contents (see
  "Threat model" and "Known limitations") — at that point the security
  of your funds reduces to the entropy of your PIN. Use this mode only
  for testing or small amounts.

Whatever mode you use: your recovery phrase backup is the ultimate
fallback. The device can always be wiped, lost or destroyed — make sure
your mnemonic is backed up safely and independently of the device.

## BIP-39 passphrases

Specter-DIY supports an optional BIP-39 passphrase (sometimes called the
"25th word") that is combined with your recovery phrase to derive the
wallet keys. Properties worth understanding before you use one:

- The passphrase is **never stored** on the device or the smartcard —
  only the mnemonic is saved. You enter the passphrase whenever the key
  is loaded.
- A passphrase-protected wallet is a completely different wallet: a
  different fingerprint, different xpubs, different addresses. There is
  no way to prove that a passphrase wallet does or does not exist, which
  gives you plausible deniability and protects you if someone finds your
  mnemonic backup.
- The flip side: if you forget the passphrase, the funds are
  irrecoverable — your mnemonic backup alone is not enough. And because
  you type it on the touchscreen, it can be observed (shoulder-surfing,
  smudges), so treat it like a password.

## Generation of the recovery phrase

This is one of the most important parts of the wallet — generating the key
securely. We use multiple sources of entropy:

- **TRNG of the microcontroller.** Proprietary, certified and probably
  good, but we don't trust it alone.
- **Touchscreen.** Every touch contributes the position and the moment of
  the touch (in microcontroller ticks at 180 MHz).

All entropy is hashed together (SHA-512 based entropy pool) and converted
to your recovery phrase. The resulting entropy is always at least as good
as the best individual source. Note: the two microphones on the board are
currently NOT used as an entropy source.

## High level logic - wallets

Specter operates as a key storage. It holds HD private keys that can be
involved in wallets. Wallets are defined by their
[descriptors](./descriptors.md). We support miniscript as well.

Every wallet belongs to a particular network. A wallet imported on
`testnet` is not available on `mainnet` or `regtest` — you need to switch
to that network and import the wallet separately. Supported networks are
Mainnet, Testnet, Regtest and Signet. Liquid support exists in the
codebase but is not actively maintained.

## Transaction verification

The following rules apply to transactions that the wallet will sign:

- Before signing, the device lists every input together with the name of
  the wallet it belongs to and its amount, so you can see exactly which
  of your wallets is spending. Inputs that belong to a wallet the device
  does **not** know are shown as "Unknown wallet" and trigger an explicit
  warning, because the device cannot verify change for them. If a
  transaction spends inputs from more than one wallet group, the device
  shows an explicit mixed-inputs warning at the top of the transaction
  confirmation, so it is visible without scrolling.
  This also applies when known-wallet and unknown-wallet inputs are mixed:
  the unknown-wallet warning is shown and the mixed-inputs warning is
  included in the transaction confirmation. The warning is particularly
  intended to mitigate the class of multisig/mixed-input change-address
  [attack](https://blog.trezor.io/details-of-the-multisig-change-address-issue-and-its-mitigation-6370ad73ed2a).
- Change outputs show the name of the wallet they are sent to.
- To use a multisig or miniscript wallet you first need to import the
  wallet by adding the wallet descriptor (over QR, USB or SD card). The
  device only signs for wallets it knows.

Change is verified for you automatically only when there is one unambiguous
spending wallet, its descriptor has exactly two branches, the output
derivation resolves to branch-list position 1, and the device re-derives the
exact output script from that branch and index. Every other output remains
visible, including receive-branch self-payments and outputs from unusual
descriptors. The branch position is not the raw child-number value in the
descriptor.

The Bitcoin transaction does not contain an `is_change` flag. A PSBT may carry
host-supplied BIP32 or Taproot derivation metadata, but that metadata is
untrusted and is checked against the locally stored descriptor and the actual
output script. If a branch-1 wallet claim does not match, the output remains
visible and the device displays: `Invalid change metadata! Host claimed this
output as wallet change, but it does not match your wallet. Verify the
destination.` This reports inconsistent host metadata; it does not claim that
Bitcoin marked the output as change.

What the device cannot check is the *recipient* of an unverified output — so
always verify the receive address and the transaction details (amounts, fees)
on the device screen. The screen is the trusted output channel, the host
computer is not.

## Communication channels

- **QR codes** are the default and recommended channel: airgapped,
  unidirectional per frame and limited in capacity, so you stay in control
  of the data flow.
- **USB** is **off by default**. It can be enabled in the device settings
  and provides the host protocol described in
  [`communication.md`](./communication.md). Enable it only when you need
  it.
- **SD card** is used for firmware upgrades and optionally for PSBTs,
  descriptors and key backups. Treat every file on it as untrusted input
  — and the card itself as sensitive: mnemonic backups written by the
  device (`specterdiy<hex-id>.<name>`) are encrypted and only readable by
  this device, but anything you explicitly export — plain mnemonic
  `.txt` files, BIP-85-derived keys, xpub files — is written
  **unencrypted** (and only when you choose that export).

Regardless of the channel, the host software (Specter Desktop, Bitcoin
Core, etc.) is considered untrusted: it can withhold transactions or show
you wrong information on its own screen, but it cannot make the device
sign something you didn't confirm on the device screen.

## Known limitations and open work

- The firmware has **not undergone an external security audit**. It is
  written in MicroPython to stay auditable, and community review is
  welcome.
- Secure poweroff that actively erases secrets from RAM is on the
  [roadmap](./roadmap.md) — currently RAM is not explicitly scrubbed on
  shutdown.
- Fuzzing and extended testing of parsers (PSBT, descriptors, QR data) is
  ongoing work, see the [roadmap](./roadmap.md).
- Without the smartcard, a sufficiently equipped attacker with prolonged
  physical access to the device should be considered able to extract
  secrets from the main MCU (see "Threat model").
- Transaction warnings are currently implemented in several different
  places rather than in one central pipeline: the device warns about
  unknown wallets in the inputs, about mixed-wallet inputs, about sighash
  flags other than SIGHASH_ALL (offering to sign SIGHASH_ALL inputs only),
  about transactions that were already signed, and about address indexes
  beyond the wallet's gap limit. Brainstorming / open work: consolidate
  these checks into a single warning pipeline and maintain a complete list
  of everything the device verifies before signing.

## Reporting vulnerabilities

Please see [`SECURITY.md`](../SECURITY.md) in the repository root for
how to report a vulnerability (contact e-mail, GPG keys for encrypted
reports, scope and disclosure process).

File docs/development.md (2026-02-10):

# Developer notes for Specter-DIY

## Compiling the code yourself

See the [build documentation](build.md) for instructions on how to compile the code.

## Enabling developer mode

By default USB communication is off. This means that when you connect the board to the computer it will NOT mount the `PYBFLASH` anymore and there will be no way to connect to debug shell.

In order to connect to the board, modify those lines in [boot.py](https://github.com/cryptoadvance/specter-diy/blob/2f51e152bcdb184cf719792e6c5f972214e3dd36/boot/main/boot.py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) like this:
```python
# configure usb from start if you want, 
# otherwise will be configured after PIN
pyb.usb_mode("VCP+MSC") # debug mode with USB and mounted storages from start
#pyb.usb_mode("VCP") # debug mode with USB from start
# disable at start
# pyb.usb_mode(None)
# os.dupterm(None,0)
# os.dupterm(None,1)
```

and after flashing, restart the device, go to Device settings > Communication > USB communication, turn it on and Confirm. Then you can connect using the micro-USB port and with something like:
```
# Linux
screen /dev/ttyACM0 115200 # or maybe ttyACM1 or ttyACM2
# Mac
screen /dev/tty.usbmodem14403 115200
```

All `print()` statements will appear in the terminal output. You can keep both the mini-USB and micro-USB connected at the same time, with the power jumper in either position. This makes it easier to flash the firmware and then connect to the device.

## Writing a simple app

Specter can be extended with custom apps. Most of the functionality is already split into apps, like `WalletManager` to manage your wallets, `MessageApp` to sign bitcoin messages, `XpubApp` to show master public keys etc.

Check out the [apps](../src/apps) folder to understand how they work.

TODO: More detailed description

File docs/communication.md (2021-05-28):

# Communcation with the host

## QR codes

### Address verification

To verify receiving address hardware wallet expects the following string:

```
bitcoin:<address>?index=<index>
```

Prefix `bitcoin:` is optional. Index should be the last index of the derivation path for one of existing wallet descriptors. 

Specter tries to derive an address for descriptors of all existing wallets and displays the address on the screen if one of derived addresses matches.

For example, if Specter has two wallets:

- Simple with descriptor `wpkh([b317ec86/84h/1h/0h]vpub5YHLPnkkpPW1ecL7Di7Gv2wDHDtBNqRdt17gMULpxJ27ZA1MmW7xbZjdg1S7d5JKaJ8CiZEmRUHrEB6CGuLomA6ioVa1Pcke6fEb5CzDBU1)`
- Multisig with descriptor `wsh(sortedmulti(2,[b317ec86/48h/1h/0h/2h]tpubDEToKMGFhyuP6kfwvjtYaf56khzS1cUcwc47C6aMH6bQ8sNVLMcCK6jr21YDCkU2QhTK5CAnddhfgZ8dD4EL1wGCaAKZaGFeVVdXHaJMTMn,[f04828fe/48h/1h/0h/2h]tpubDFekS5zvPSdW6WWjH2p7vPRkxmeeNGnirmj36AUyoAYbJvfKBj6UARWR5gQ6FRrr98dzT1XFTi6rfGo9AAAeutY1S6SoWijQ8BKxDhYQzDR,[d3c05b2e/48h/1h/0h/2h]tpubDFnAczXQTHxuBh7FxrpLDHBidkC1Di54pTPSPMu4AQjKziFQQTTEFXEVugqm8ucKQhJfLGesBjRZWtLpqAkAmecoXtvaPwCzf4teqrY7Uu5))`

and it scanned QR code with data `bitcoin:bcrt1qd3mtrhysk3k4w6fmu7ayjvwk6q98c2dpf0p4x87zauu8rcgq5dzq73tyrx?index=2`

it will try to derive receiving addresses for both wallets appending `/0/2` to every descriptor key. In this case for Multisig wallet the address will match, therefore it will display to the user this address with a title `Address #2 from wallet "Multisig"`.

*Note that wallets are defined for particular network, so if you have a multisig wallet on regtest doesn't mean that it exists on testnet as well, and Specter only checks wallets in currently selected network.*

### Adding wallet to Specter

In order to sign transaction or verify an address Specter needs to know about corresponding wallet. By default only `wpkh` wallet is created for each network, so all multisig wallets need to be imported.

To import the wallet using QR codes user needs to get to the **Wallets** menu and click on **Add wallet**. Scanned QR code should be of the following form:

```
addwallet <wallet_name>&<wallet_descriptor>
```

Descriptors used in Specter are almost the same as in [Bitcoin Core](https://github.com/bitcoin/bitcoin/blob/master/doc/descriptors.md) with a few differences - they support miniscript, multiple branches definitions and use default derivations `/{0,1}/*`. Check out [descriptors.md](./descriptors.md) for details.

Example of the multisig wallet import code:

```
addwallet My multisig&wsh(sortedmulti(2,[b317ec86/48h/1h/0h/2h]tpubDEToKMGFhyuP6kfwvjtYaf56khzS1cUcwc47C6aMH6bQ8sNVLMcCK6jr21YDCkU2QhTK5CAnddhfgZ8dD4EL1wGCaAKZaGFeVVdXHaJMTMn,[f04828fe/48h/1h/0h/2h]tpubDFekS5zvPSdW6WWjH2p7vPRkxmeeNGnirmj36AUyoAYbJvfKBj6UARWR5gQ6FRrr98dzT1XFTi6rfGo9AAAeutY1S6SoWijQ8BKxDhYQzDR,[d3c05b2e/48h/1h/0h/2h]tpubDFnAczXQTHxuBh7FxrpLDHBidkC1Di54pTPSPMu4AQjKziFQQTTEFXEVugqm8ucKQhJfLGesBjRZWtLpqAkAmecoXtvaPwCzf4teqrY7Uu5))
```

It will promt the user and then create a wallet called "My multisig" with 2 of 3 multisig policy with sorted public keys.

### Signing transaction

Just display a base64-encoded PSBT transaction as a QR code.

We also added one special case for bip32 derivations - if fingerprint in derivation is set to `00000000` it is replaced by the fingerprint of the device. We treat this fingerprint as a mark from software wallet that it doesn't know the fingerprint of the device.

In this case PSBT transaction can be constructed with a correct derivation path even if fingerprint is not known to the software wallet, but the derivation path is known - for example when `zpub` or `ypub` is imported software wallet knows the depth of the derivation (normally `3`), purpose (`84` for `zpub` and `49` for `ypub`), coin type (`0` - Mainnet for `zpub` and `ypub`, `1` - Testnet for `upub` or `vpub`) and master key child number. So `zpub` and `ypub` normally contain full derivation path of the key without master fingerprint.

Signed transaction is also displayed as a base64-encoded PSBT transaction with all unnecessary fields removed - only global transaction and partial signatures for all inputs remain there. All other fields are removed to save space in the QR code. This means that software wallet needs to keep original PSBT and combine them when signed PSBT is scanned.

## USB communication

We use human-readable plain text messages, because we can and they are way easier to debug even though they are not optimal in sense of space. Each command should end with `\r` or `\r\n`.

The following commands are supported:

- `fingerprint` - returns hex fingerprint of the root key.
- `xpub <derivation>` - returns xpub with derivation. For hardened derivation both `h` and `'` can be used. For example `xpub m/84h/1h/0h`.
- `sign <psbt>` - asks user to confirm transaction signing.
- `showaddr <type> <derivation> [witness_script_hex]` - show address of `type` with `derivation`. `type` can be `wpkh`, `sh-wpkh`, `pkh`, `sh`, `sh-wsh` or `wsh`. Witness script is required for non-pkh wallets.
- `importwallet <wallet_name>&<descriptor>` - asks user to confirm adding new `wallet` with `descriptor`.

## SD card

`.psbt` and `.txt` files are supported. The content of the file is processed like a USB or QR code, so it can be a transaction, wallet import command or address verification command.

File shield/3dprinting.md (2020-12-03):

# Specter DIY Case 3D Printing

## 3D Printing

STL and Prusa Gcode files can be downloaded at the following links:

- Grabcad: https://grabcad.com/library/specter-diy-hardware-wallet-case-1
- Thingiverse: https://www.thingiverse.com/thing:4671552

The Prusa Gcode files include a high temperature and low temperature version, we have had good results in PLA with the low temperature setting.

Print 1

Print 2

Print 3

Print 4

Print 5

## Post 3D Printing

1. Remove all support material including the ribs on the back case. 
Careful on the inside where the QR code scanner mount is, this is relatively fragile.

Post 1

Post 2

Post 3

2. For smooth button operation remove the thin layer of support material underneath the button. This can be tested without components inside to ensure there is no friction when pressing.

Post 4

Post 5

3. M3 nuts of 2mm thickness are used to fix components in the back case, these snap into the case but are best glued in.

Post 6

## Specter DIY Assembly

Assembly of Specter DIY components and Specter DIY 3D printed case

Required:

- Specter DIY Case
- Specter Shield
- STM Discovery Board STM32F469I-DISCO
- 6x M3x5mm screws low profile head
- 2x M3 nuts 3mm thick
- 2x 9mm male/female Spacers (6mm thread)
- 2x 12mm female/female Spacers
- 2x M1.4x3mm screws for QR Scanner

Assembly 1

1. Attach the female/female spacers to lower holes in the Specter Shield PCB with two M3 screws.

Assembly 2

2. Place Specter Shield in the back case. Fix in position with the two male/female spacers using the two M3 nuts to increase offset.

Assembly 3

3. Attach STM discovery board and fix in place with 4 M3 screws.

Assembly 4

4. Attach front case beginning on the left (side with the SD card slot).

Assembly 5

5. Then push right side down, carefully moving the button past the display edge. To snap housing closed takes a bit of pressure.

6. When fully closed the display should be flush with the front of the case. Check that all USB ports are correctly aligned and the Smartcard fits.

Assembly 6

## Opening the case

To open the case it is best to start above the button on the right side. With finger nail lever front case up. Then repeat on the lower right side.

Open 1

Lift the front case away from the display, carefully moving the button past the display edge.

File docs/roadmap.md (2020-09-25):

# Roadmap for Specter-DIY development

Security critical features:

- optional secure bootloader checking signatures on the firmware
- secure poweroff that erases all the secrets from RAM
- moving device secret to the very beginning of the flash or even to the bootloader
- add tests, fuzzing etc
- optimize the code

Documentation:

- firmware protection instructions with tools from STM

Would be nice to add:

- Devkit (WIP)
- SD card support

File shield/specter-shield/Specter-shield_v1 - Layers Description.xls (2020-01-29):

PCB Name |  | specter-shield_v1
Number of Layers |  | 4
Material |  | FR4
Board thickness |  | 1,5 mm
Copper thickness |  | 0,018mm
Mask color |  | Blue
Covering |  | ENIG
Archive Name |  | specter-shield_v1.zip
PCB size |  | 60 x 127 mm
Min Trace-to-trace spacing |  | 0,200 mm
 | Gerber data files | Mm
1 | specter-shield_v1.GBP | Paste mask for Top side
2 | specter-shield_v1.GTO | Silkscreen for Top side
3 | specter-shield_v1.GTS | Soldering mask for Top side
4 | specter-shield_v1.GTL | Top side
5 | specter-shield_v1.GP1 | Internal Layer 1 (Negative)
6 | specter-shield_v1.GP2 | Internal Layer 2 (Negative)
7 | specter-shield_v1.GBL | Bottom side
8 | specter-shield_v1.GBS | Soldering mask for Bottom side
9 | specter-shield_v1.GBO | Silkscreen for Bottom side
10 | specter-shield_v1.GTP | Paste mask for Bottom side
11 | specter-shield_v1.Outline | Border
 | Excellon Drill data
 | specter-shield_v1-RoundHoles.TXT | Drill data for round holes (through-hole drill, metric)
 | specter-shield_v1-SlotHoles.TXT | Drill data for slot holes (through-hole drill, metric)
 | Pick & Place Data
 | Pick Place for specter-shield_v1.txt | Pick & Place Coordinates for all components (metric)

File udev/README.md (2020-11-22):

# udev rules

This directory contains udev rules for micropython & Specter DIY.
These are necessary for the devices to be reachable on linux environments.

 - `49-micropython.rules` (Specter-DIY): http://wiki.micropython.org/Installation#USB-Permissioning-on-Linux

Specter is connected as a virtual serial port, so you need to add yourself to `dialout` group.

# Usage

Apply these rules by copying them to `/etc/udev/rules.d/` and notifying `udevadm`.
Your user will need to be added to the `plugdev` group, which needs to be created if it does not already exist.

```
$ sudo cp 49-micropython.rules /etc/udev/rules.d/
$ sudo udevadm trigger
$ sudo udevadm control --reload-rules
$ sudo groupadd plugdev
$ sudo usermod -aG plugdev `whoami`
$ sudo usermod -aG dialout `whoami`
```

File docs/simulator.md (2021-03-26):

# Simulator

Simulator requires `SDL` library to be installed (`sudo apt install libsdl2-dev` on Linux and `brew install sdl2` on Mac).

Run `make unix` to get it. If everything goes well a `micropython_unix` binary will appear in the `bin` folder.

Start simulator using `make simulate`.

You should see the screen with the wallet interface. As in unixport we don't have QR code scanner or USB connector, so instead it simulates serial communication and USB on TCP ports: `5941` for QR scanner and `8789` for USB connection.

You can connect to these ports using `telnet` and type whatever you expect to be scanned / sent from the host.

The simulator is also printing content of the QR codes displayed on the screen to the console.

The simulator create folders in `./fs`:

- `fs/flash` - files that would be stored in the internal flash of the MCU
- `fs/qspi` - files in external QSPI chip (untrusted, everything is stored encrypted and authenticated)
- `fs/ramdisk` - files in external SPIRAM memory (work as temporary storage for host communication, untrusted)
- `fs/sd` - SD card

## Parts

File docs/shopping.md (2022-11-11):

# Shopping list for Specter-DIY

Here we describe what to buy, and in [assembly.md](./assembly.md) we explain how to put it together and a few notes about the board - power jumpers, USB ports etc.

## Discovery board

Main part of the device is the developer board:

- STM32F469I-DISCO developer board (i.e. from [Mouser](https://eu.mouser.com/ProductDetail/STMicroelectronics/STM32F469I-DISCO?qs=kWQV1gtkNndotCjy2DKZ4w==) or [Digikey](https://www.digikey.com/product-detail/en/stmicroelectronics/STM32F469I-DISCO/497-15990-ND/5428811))
- **Mini**USB cable
- Standard MicroUSB cable to communicate over USB

Optional but recommended:
- [Waveshare QR code scanner](https://www.waveshare.com/barcode-scanner-module.htm) with long pin headers like [these](https://eu.mouser.com/ProductDetail/Samtec/DW-02-10-T-S-571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) or [these](https://www.amazon.com/gp/product/B015KA0RRU/) to connect the scanner to the board (4 pin headers needed).

Check out the assembly video [on youtube](https://youtu.be/1H7FqG_FmCw)

We are currently working on [an extension board](../shield) that includes a smartcard slot, QR code scanner, battery and a 3d printed case, but it doesn't include the main part — discovery board that you need to order separately. This way supply chain attack is still not an issue as the security-critical components are bought from random electronic store.

You can start using Specter even without any extra components, but you will be able to communicate with it over USB or the built-in SD card slot. Using Specter over USB means it is not airgapped so you lose an important security property.

## QR scanner

For QR code scanner you have several options.

**Option 1. Recommended.** Resonably good scanner from Waveshare (40$)

[Waveshare scanner](https://www.waveshare.com/barcode-scanner-module.htm) - you will need to find a way how to mount it nicely, maybe use some kind of Arduino Prototype shield and some ducktape. For wiring see [assembly.md](./assembly.md).

No soldering required, but if you have soldering skills you can make the wallet way nicer ;)

**Option 2.** Very nice scanner from Mikroe but pretty expensive (150$):

[Barcode Click](https://www.mikroe.com/barcode-click) + [Adapter](https://www.mikroe.com/arduino-uno-click-shield)

**Option 3.** Any other QR scanner

You can find some cheap scanners in China. Their quality is often not that great, but you can take a chance. Maybe even ESPcamera would do the job. You only need to connect power, UART (pins D0 and D1), and trigger to D5.

**Option 4.** No scanner. 

Then you can only use Specter with USB / SD Card.

Unless you build your own communication module that uses something else instead of QR codes - audiomodem, bluetooth or whatever else. As soon as it can be triggered and send the data over serial you can do whatever you want.

## Optional components

If you add a tiny powerbank or a battery & power charger/booster, your wallet becomes completely self-contained ;)

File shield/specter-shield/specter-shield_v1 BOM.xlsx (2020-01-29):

Project name: Specter DevKit v1.0.0 |  |  | Revision: 1
PCB name: specter-shield_v1 |  |  | Set: 1 | Date: 11 december 2019
Item # | Designator | Quantity | Manufacturer Part No. | Description | Manufacturer | Value | Footprint
1 | C1, C2, C13, C16, C17, C39 | 6 | GCM155R71H102KA37D | CAP CER 1000PF 50V 10% X7R | Murata | 1n | 0402
2 | C3, C4, C6, C9, C10, C11, C12, C14, C15, C25, C27, C28, C29, C30, C31, C32, C33, C34, C38, C45, C48 | 21 | GCM155R71C104KA55D | CAP CER 0.1UF 16V 10% X7R | Murata | u1 | 0402
3 | C5, C7, C18, C37, C41 | 5 | GCM188R71E105KA64D | 1uF 10% 25 V dc X7R Ceramic Multilayer Capacitor | Murata | 1u | 0603
4 | C8, C19, C20, C21, C22, C23, C24, C35, C36, C40, C42 | 11 | GRM21BR61E226ME44L | CAP, MLCC, X5R, 22UF, 25V | Murata | 22u | 0805
5 | C26 | 1 | GJM1555C1H100JB01D | CAP CER 10PF 50V 5% NP0 | Murata | 10p | 0402
6 | C43, C44, C46, C47 | 4 | TPSC107K010R0150 | Cap Tant Solid 100uF 10V 10% 0.15 Ohm 125A°C | AVX | 100uF 10V | C
7 | D1 | 1 | CDSOD323-T05S | ESD Suppressor TVS ±30KV | Bourns |  | SOD-323
8 | D2 | 1 | LTST-S270KRKT | LED; SMD; 0604; red; 18-54mcd; 1.6x1.15x0.6mm; 130°; 2.4V; 20mA | Lite-On |  | 0604
9 | D3, D4, D5, D6, D7 | 5 | RB520S30T1G | Schottky Barrier Diode | ON Semiconductor |  | SOD-523
10 | FB1, FB2 | 2 | MPZ1608S102ATA00 | Ind Chip Bead Multi-Layer 1KOhm 25% 100MHz Ferrite 800mA | TDK |  | 0603
11 | J1 | 1 | 10118193-0001LF | Conn Micro USB Type B RCP 5 POS 0.65mm Solder RA SMD 5 Terminal 1 Port | FCI |  | SMD
12 | J2 | 1 | S2B-PH-SM4-TB(LF)(SN) | 2 Positions Header, Shrouded Connector 0.079" (2.00mm) Surface Mount, Right Angle Tin | JST |  | SMD
13 | J6 | 1 | S3B-PH-SM4-TB(LF)(SN) | PH Series 3 Position 2.0 mm SMT Side Entry Shrouded Header | JST |  | SMD
14 | J8 | 1 | 7312P0225A13LF | Smart Card, Input Output Connectors, IC Chip Card Connector, 8 contacts, Surface Mount | FCI |  | SMD
15 | J9, J12 | 2 | M20-8770842 | 2.54mm (0.1") Pitch SIL SMT Pin Header, selective gold + tin, 8 contacts | Harwin |  | SMD
16 | J10 | 1 | SFV12R-2STE1HLF | Conn; Rect; FPC/FFC; 12 Pos; SMT; 0.5mm; Top Side Entry Cnt; SFV-R Ser; ZIF; HF; LF | Amphenol |  | SMD
17 | J11 | 1 | M20-8771042 | 2.54mm (0.1") Pitch SIL SMT Pin Header, selective gold + tin, 10 contacts | Harwin |  | SMD
18 | J13 | 1 | M20-8770642 | 2.54mm (0.1") Pitch SIL SMT Pin Header, selective gold + tin, 6 contacts | Harwin |  | SMD
19 | L1 | 1 | ACP3225-102-2P-T000 | ACP Series 1210 1000 Ohm 1.2 A 0.10 Ohm DCR 50 V SMT Common Mode Filter | TDK |  | SMD
20 | L2 | 1 | VLS5045EX-1R5N | Inductor Power Shielded Wirewound 1.5uH 30% 100KHz Ferrite 5A 17mOhm DCR | TDK |  | 2020
21 | LS1 | 1 | SMT-1127-S-R | Audio Indicators and Alerts Transducer | PUI Audio |  | SMD
22 | Q1, Q4 | 2 | NTR4101PT1G | Trench Power MOSFET, -20 V, Single P-Channel | ON Semiconductor |  | SOT-23
23 | Q2, Q3, Q5, Q6 | 4 | DMG1012T-7 | MOSFET N-CH 20V 630MA | Diodes Inc. |  | SOT-523
24 | R1, R14, R37, R38 | 4 | RC0402FR-071KL | RESISTOR, RC32H 1K | YAGEO | 1k | 0402
25 | R2, R7, R12, R31 | 4 | RC0402FR-0724KL | RESISTOR, 0.063W 1% 24K | YAGEO | 24k | 0402
26 | R3, R19, R36, R40, R41, R42, R51 | 7 | RC0402FR-07200RL | RES SMD 200 OHM 1% 1/16W | YAGEO | 200R | 0402
27 | R4, R6, R11, R17, R24, R25, R27, R29 | 8 | RC0402FR-07120KL | RES SMD 120K OHM 1% 1/16W | YAGEO | 120k | 0402
28 | R21, R23, R28, R44 | 4 | RC0402FR-0722RL | RESISTOR, RC32H 22R | YAGEO | 22R | 0402
29 | R8, R20 | 2 | RC0402FR-072KL | Surface Mount Thick Film Resistor, 2 kohm, 63 mW, - 1%, 50 V | YAGEO | 2k 1% | 0402
30 | R9, R45 | 2 | RC0402FR-0711K3L | RES SMD 11.3K OHM 1% 1/16W | YAGEO | 11.3k 1% | 0402
31 | R10 | 1 | NCP15XH103F03RC | Thermistor NTC 10K Ohm 1% 2-Pin 3434K T/R | Murata | 10k | 0603
32 | R15, R16, R18, R30, R32, R33, R34, R35, R39, R43, R46, R47, R48, R49, R50, R52 | 16 | RC0402FR-0710KL | Res Thick Film 10K Ohm 1% 0.063W 100ppm Molded SMD | YAGEO | 10k | 0402
33 | R22 | 1 | ERJ-3BWFR030V | Res Thick Film 0603 0.03 Ohm 1% 0.25W ±250ppm/°C | Panasonic El. Comp. | 30m | 0603
34 | R26 | 1 | RT0402BRD07200KL | Res Thin Film 0402 200K Ohm 0.1% 1/16W ±25ppm/°C | YAGEO | 200k 0.1% | 0402
35 | SW1 | 1 | 1825968-2 | Switch Tactile N.O. SPST Square Button PC Pins 0.05A 24VDC 500000Cycles 1.6N | TE |  | Thru-hole
37 | U1 | 1 | BQ25060DQCR | 1 A, Single-Input, Single Cell Li-Ion Battery Charger with 50 mA LDO | Texas Instruments |  | WSON-10
38 | U2 | 1 | TPS3422EGDRYR | Single Channel Push Button Controller with Configurable Delay and Reset Pulse | Texas Instruments |  | SON-6
39 | U3 | 1 | STC3100IST | Battery Monitoring Li-Ion | STMicroelectronics |  | MSOP-8
40 | U4 | 1 | TPS63060DSCR | Conv DC-DC 2.5V to 12V Step Down/Step Up Single-Out 2.5V to 8V 1A | Texas Instruments |  | WSON-10
41 | U5 | 1 | MAX803SQ293D2T1G | 3-Pin Microprocessor, Reset Monitor 2.93 V, 20 ms minimum delay | Maxim Integrated |  | SC-70
42 | U6 | 1 | ST8034HNQR | ST8034HN Series 5 V Surface Mount Smartcard Interface | STMicroelectronics |  | QFN-24
 | NU - NOT USED
43 | J3 | 1 |  | cms pad for wire soldering |  | BAT_P
44 | J4 | 1 |  | cms pad for wire soldering |  | BAT_TS
45 | J5 | 1 |  | cms pad for wire soldering |  | BAT_M
46 | J7 | 1 |  | SMD Test Point |  | PWRGOOD
28 | R5 | 1 | RC0402FR-0722RL | RESISTOR, RC32H 22R | YAGEO | 22R | 0402
27 | R13 | 1 | RC0402FR-07120KL | RES SMD 120K OHM 1% 1/16W | YAGEO | 120k | 0402
36 | SW2 | 1 | OS102011MA1QN1 | Switch; Slide; Mini; SPDT; ON-ON; Non-Shorting(BBM); 100mA; 12VDC | C&K Components |  | Thru-hole

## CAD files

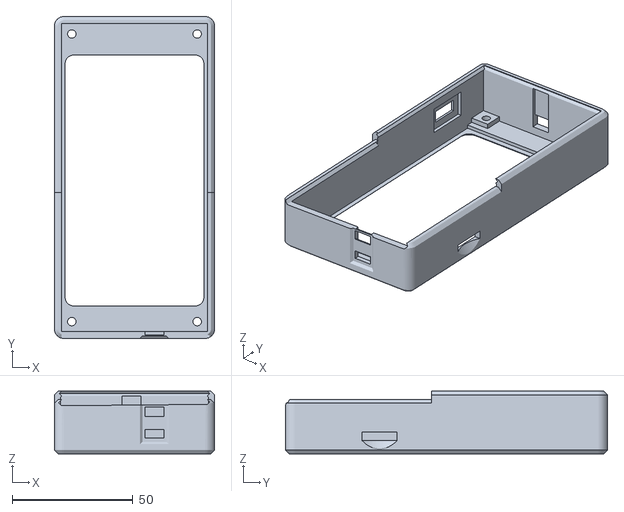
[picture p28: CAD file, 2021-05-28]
shield/Alternative_3D_Printed_Case/01_Main_Body.stl
66.5 x 133.5 x 26.0

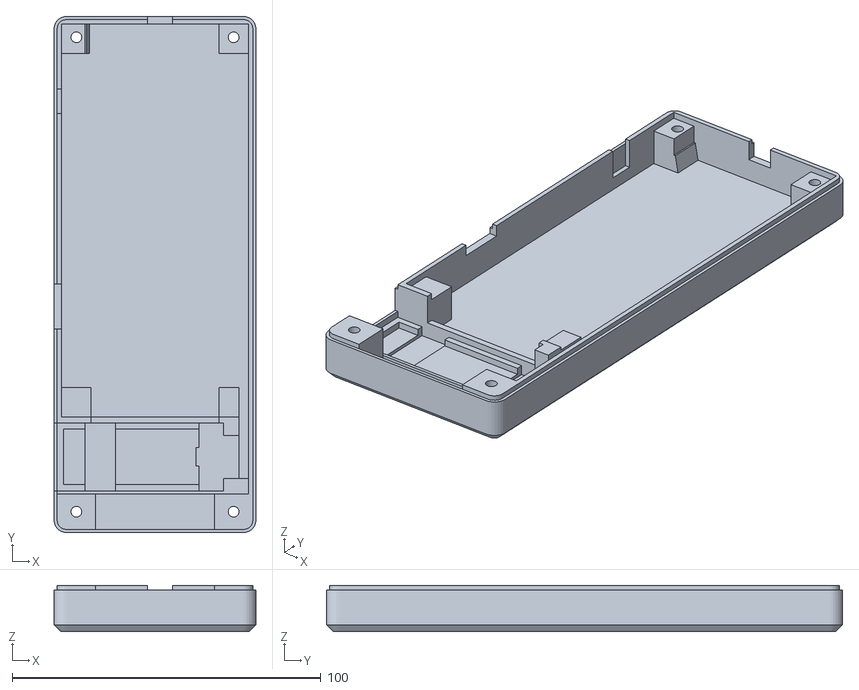
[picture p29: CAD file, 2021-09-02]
docs/enclosures/seedsigner/BBv2_Lower.stl
65.4 x 167.2 x 15.0

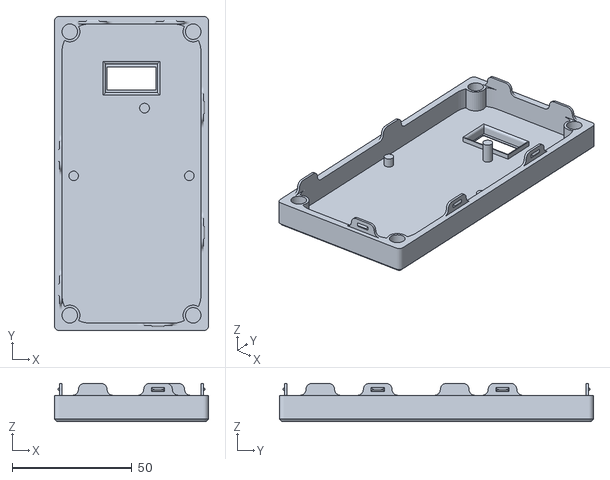
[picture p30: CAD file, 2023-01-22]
docs/enclosures/snapcase/Specter-DIY Snap Case - Backside.stl
64.4 x 131.4 x 16.0

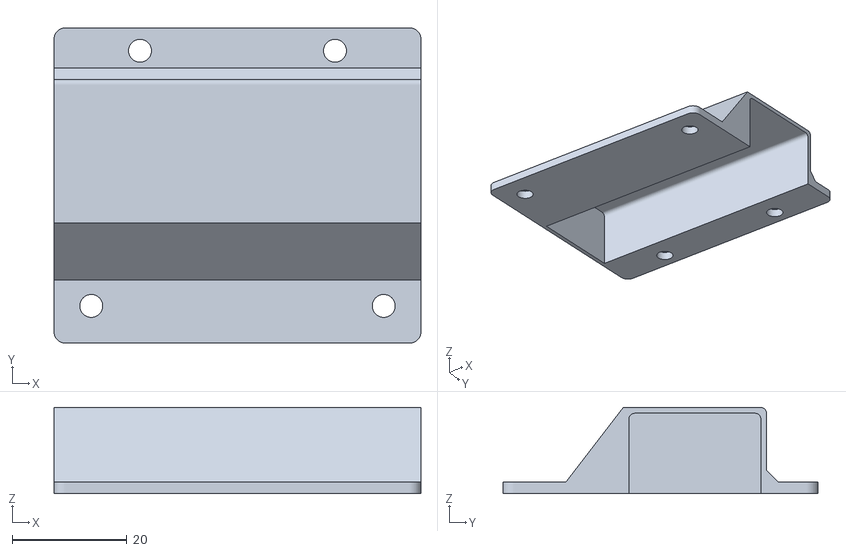
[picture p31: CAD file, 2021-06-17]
docs/enclosures/thomas/Scan_case-v0.2.stl
64.0 x 55.0 x 15.0

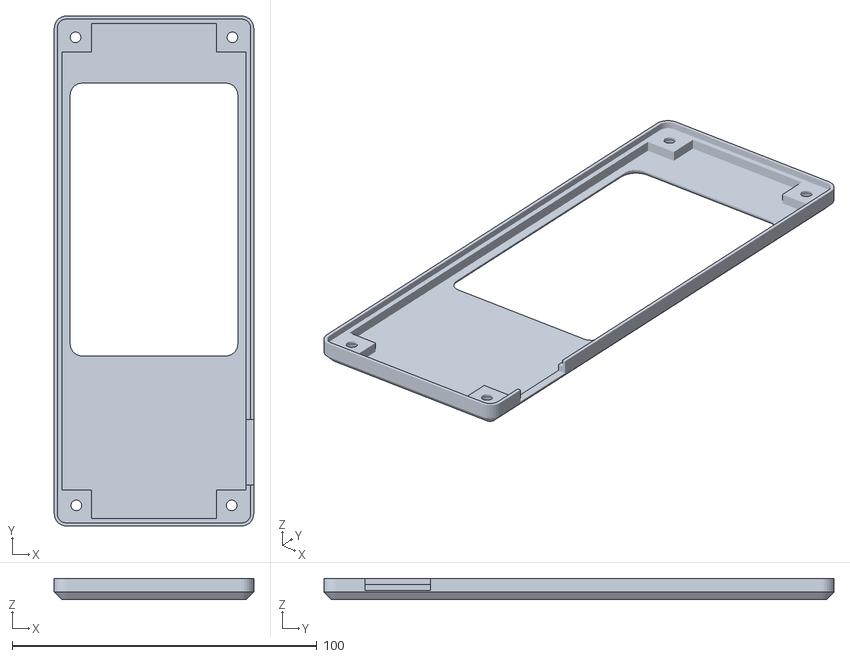
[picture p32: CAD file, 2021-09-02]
docs/enclosures/seedsigner/BBv2_Upper.stl
65.4 x 167.2 x 7.00

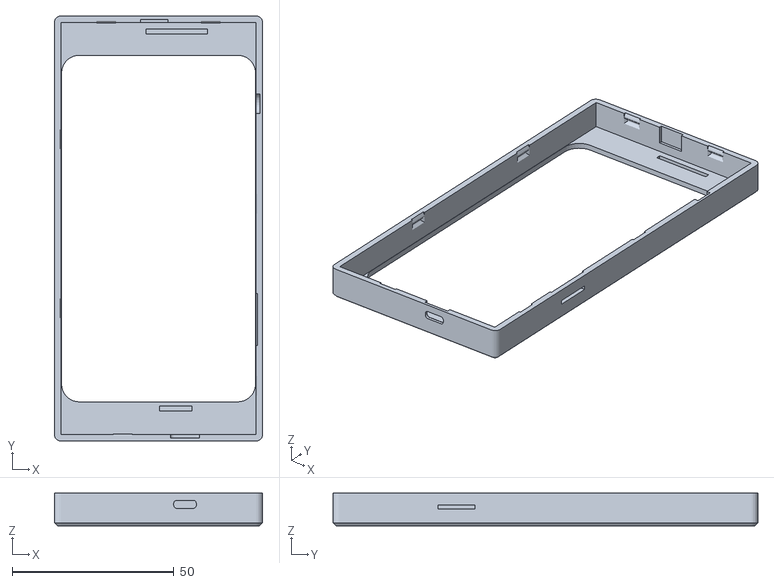
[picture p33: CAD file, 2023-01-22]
docs/enclosures/snapcase/Specter-DIY Snap Case - Frontside.stl
64.4 x 131.4 x 10.2

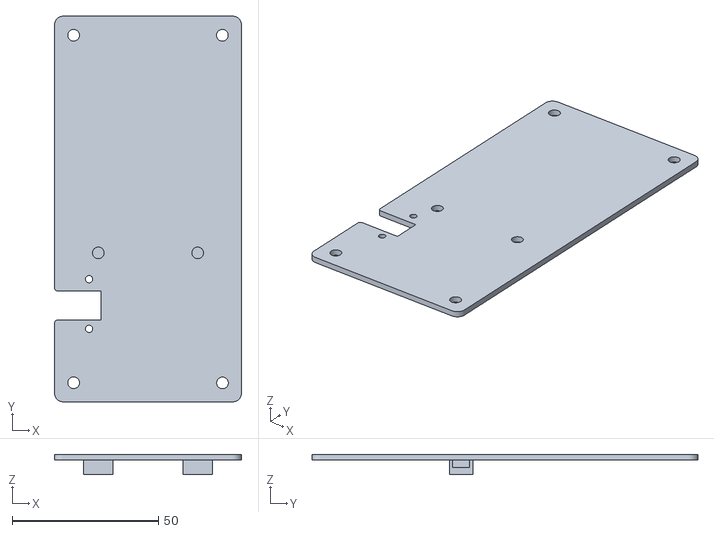
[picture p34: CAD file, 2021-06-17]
docs/enclosures/thomas/DIY-Platte-v0.21.stl
64.0 x 132.0 x 7.02

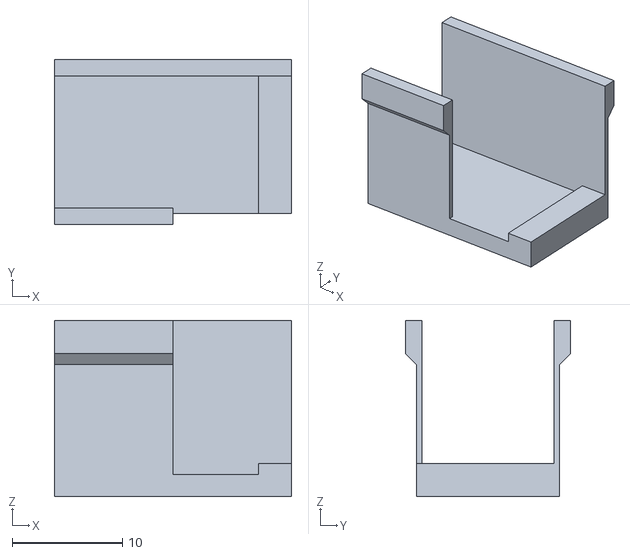
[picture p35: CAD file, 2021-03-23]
shield/Alternative_3D_Printed_Case/04_Camera_Holder.stl
21.5 x 15.0 x 16.0

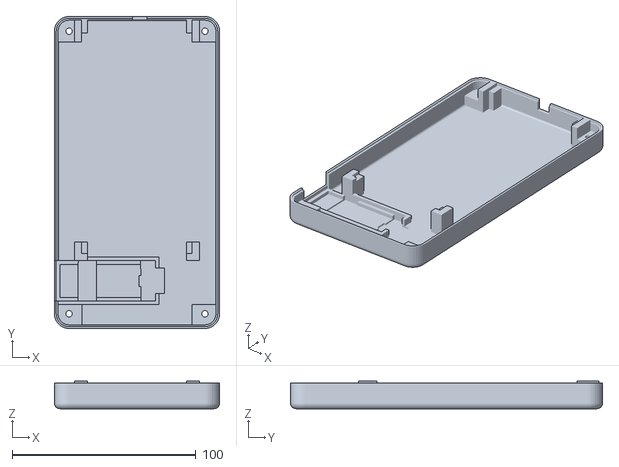
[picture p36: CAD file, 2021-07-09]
docs/enclosures/seedsigner/BBv1_Lower.stl
90.0 x 170.0 x 15.0

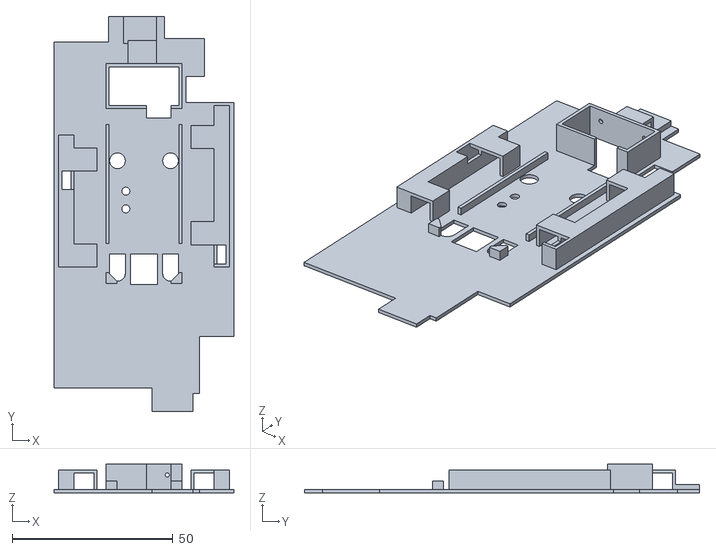
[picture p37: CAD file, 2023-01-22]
docs/enclosures/snapcase/Specter-DIY Snap Case - Scanner.stl
56.0 x 123.0 x 9.00

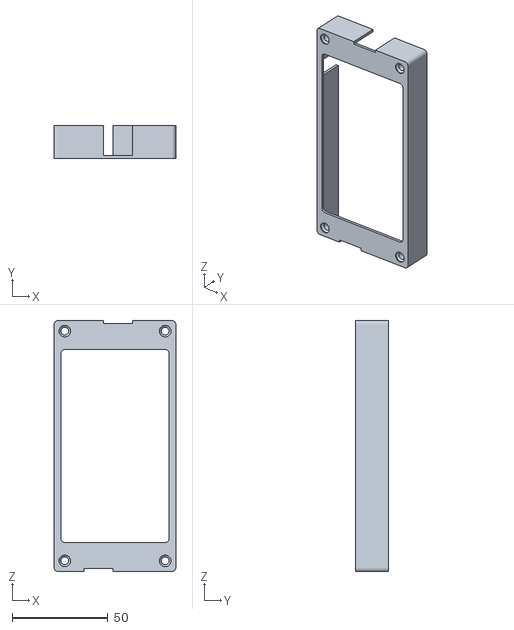
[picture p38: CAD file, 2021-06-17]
docs/enclosures/thomas/DIY-Front-Display-v0.12.stl
63.5 x 17.1 x 131.0

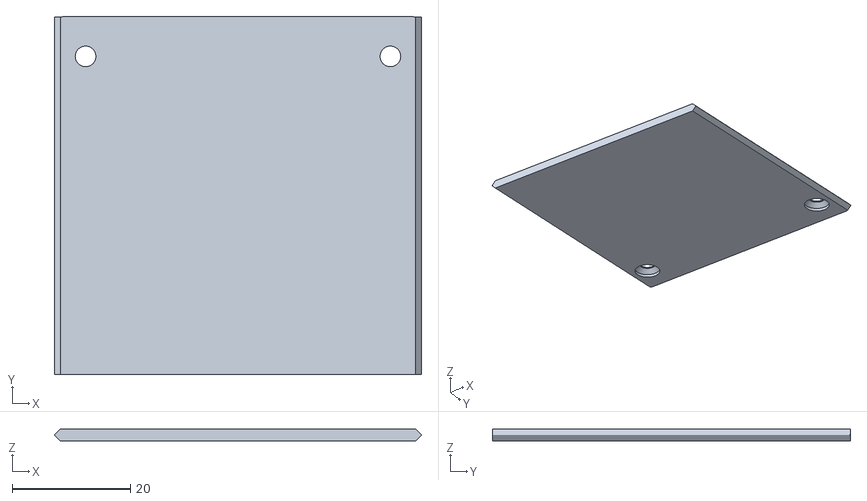
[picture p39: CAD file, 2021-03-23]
shield/Alternative_3D_Printed_Case/03_Bottom_Panel.stl
62.0 x 60.5 x 2.00

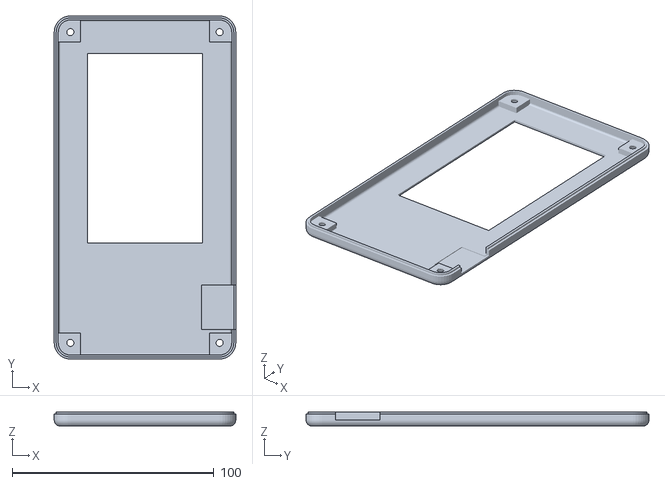
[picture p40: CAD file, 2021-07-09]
docs/enclosures/seedsigner/BBv1_Upper.stl
90.0 x 170.0 x 7.00

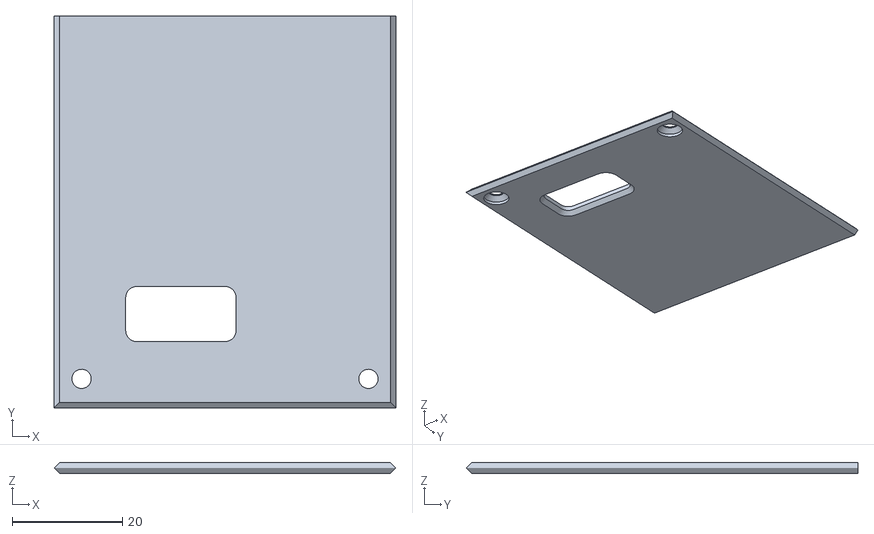
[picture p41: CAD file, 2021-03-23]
shield/Alternative_3D_Printed_Case/02_Top_Panel.stl
62.0 x 71.0 x 2.00

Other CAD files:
shield/Alternative_3D_Printed_Case/06_Spacer.stl
shield/Alternative_3D_Printed_Case/05_Button.stl

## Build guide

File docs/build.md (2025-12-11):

# Build

Clone the repository recursively `git clone https://github.com/cryptoadvance/specter-diy.git --recursive`

`bootloader` folder contains a [secure bootloader](https://github.com/cryptoadvance/specter-bootloader) that you can customize with your own firmware signing keys.

Check [reproducible-build](./reproducible-build.md) if you want to use Docker.

## Prerequisites for the Nix build

There are multiple ways to get all necessary tools. The recommended way is to use the Nix flake with direnv.
If that's too complicated for you, you can use the traditional `nix-shell` or install the tools manually (which mighty be tricky to get the dependencies right).

### Install Nix on Ubuntu 24.04

```sh
sudo apt update
sudo apt install nix
```

Enable the required experimental features for flakes and the new CLI:

```sh
sudo mkdir -p /etc/nix
echo "experimental-features = nix-command flakes" | sudo tee -a /etc/nix/nix.conf
```

Add your user to the `nix-users` group so you can access the Nix store:

```sh
sudo usermod -aG nix-users "$USER"
newgrp nix-users
```

### Nix flake (Recommended)

The easiest way to get all necessary tools is to use the Nix flake from the root of the repository. You need to have [Nix](https://nixos.org/) (on Mac use [determinate](https://github.com/DeterminateSystems/nix-installer)) with flakes enabled. This only works with Nix >2.7 (check with `nix --version`).
Install direnv with `brew install direnv` (on Mac) or `sudo apt install direnv` (on Linux). direnv automatically loads and unloads the environment described in `.envrc` when you enter or leave the repository, so the development tooling is ready without extra commands.

Make sure that [flakes are enabled](https://nixos.wiki/wiki/Flakes) in your Nix config. On Linux systems, your user might need to be added to the nix-users group.

```sh
# Enter development shell
nix develop

# Or use with direnv for automatic activation
direnv allow
```

### Nix shell

Alternatively, you can use the traditional `shell.nix`:

```sh
nix-shell
```
You'll need to have [Nix](https://nixos.org/) installed as well.

### Prerequisities (Manually): Board

To compile the firmware for the board you will need `arm-none-eabi-gcc` compiler.

**Debian/Ubuntu**:
```sh
sudo apt-get install build-essential gcc-arm-none-eabi binutils-arm-none-eabi gdb-multiarch openocd
```

**Archlinux**:
```sh
sudo pacman -S arm-none-eabi-gcc arm-none-eabi-binutils openocd base-devel python-case
```
You might need change default gcc flag settings with `CFLAGS_EXTRA="-w"`. Export it or set the variable before of `make`
to avoid warnings being raised as errors.

**MacOS**:
```sh
brew tap ArmMbed/homebrew-formulae
brew install arm-none-eabi-gcc
```

On **Windows**: Install linux subsystem and follow Linux instructions.

### Prerequisities (Manually): Simulator

You may need to install SDL2 library to simulate the screen of the device.

**Linux**:
```sh
sudo apt install libsdl2-dev
```

**MacOS**:
```sh
brew install sdl2
```

**Windows**:
- `sudo apt install libsdl2-dev` on Linux side.
- install and launch [Xming](https://sourceforge.net/projects/xming/) on Windows side
- set `export DISPLAY=:0` on linux part

## Build

All build commands might need a prefix like `nix develop -c` or need to be run from `nix develop` shell. If you use direnv, you don't need to do anything, apart from an initial `direnv allow`.

### Starting the build

After entering the development shell (either with `nix develop` or via direnv), start the default firmware build with:

```sh
make disco
```

This produces `bin/specter-diy.bin`, which can be flashed by dragging the file onto the board's virtual mass-storage drive or by
using programming tools such as STM32CubeProgrammer.

To build custom bootloader and firmware that you will be able to sign check out the bootloader doc on [self-signed firmware](https://github.com/cryptoadvance/specter-bootloader/blob/master/doc/selfsigned.md). To wipe flash and remove protections on the device with the secure bootloader check out [this doc](https://github.com/cryptoadvance/specter-bootloader/blob/master/doc/remove_protection.md).

To build an open firmware (no bootloader and signature verifications) run `make disco`. It also produces the `bin/specter-diy.bin` image ready for flashing via the board's virtual drive or external programming tools.

To build a simulator run `make unix` - it will compile a micropython simulator for mac/unix and store it under `bin/micropython_unix`.

To launch a simulator either run `bin/micropython_unix simulate.py` or simly run `make simulate`.

If something is not working you can clean up with `make clean`

### Automated build script

The top-level `build_firmware.sh` helper runs the full secure build, including the bootloader and signed upgrade package. It
also creates `release/disco-nobootloader.{bin,hex}`, which contain the plain firmware without the secure bootloader. The
`disco-nobootloader.bin` image is identical to the `nix build` output and can be flashed directly to a development board when
you need a faster iteration loop.

## Run Unittests

Currently unittests work only on linuxport, and there are... not many... Contributions are very welcome!

```
make test
```

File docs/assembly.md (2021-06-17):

# Assembly of Specter-DIY

## Connecting Waveshare Barcode scanner

The wallet firmware will configure the scanner for you on the first run, so no manual preconfiguration is required.

Here is how you connect the scanner to the board:

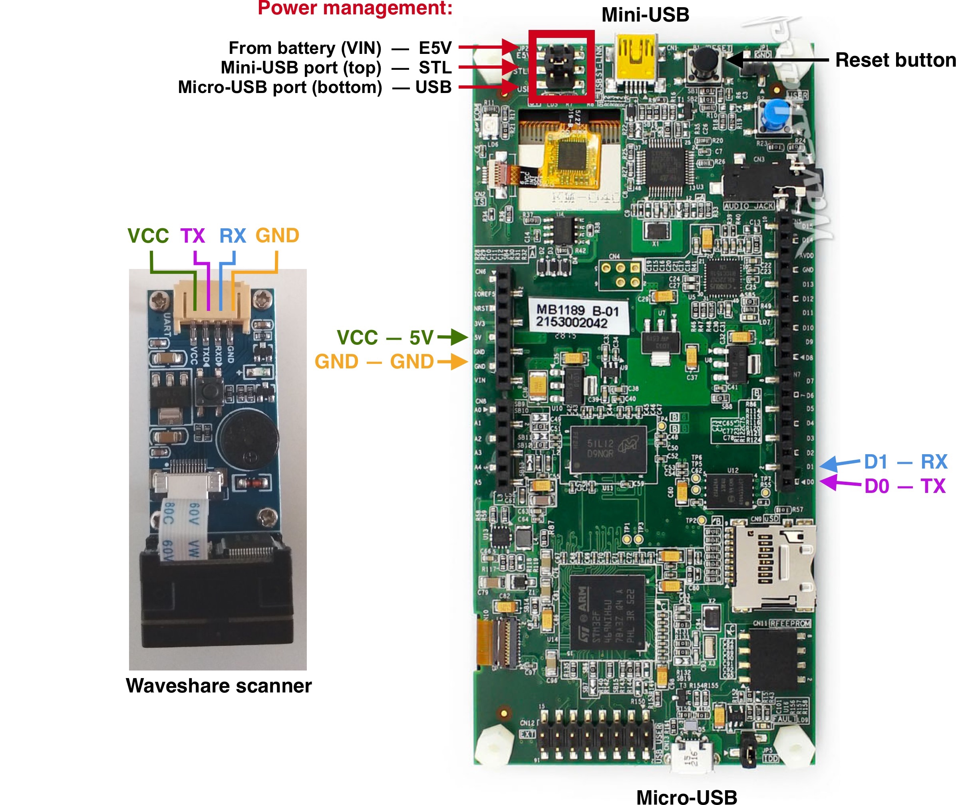
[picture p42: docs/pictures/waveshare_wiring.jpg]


For convenience you can buy an Arduino Protype shield and solder & mount everything on it (i.e. [this one](https://www.digikey.com/catalog/en/partgroup/proto-shield-rev3-uno-size/79347))

## Power management

On the top side of the board there is a jumper that defines where it will take power. You can change position of the jumper and select power source to be one of the USB ports or VIN pin and connect external battery there (should be 5V).

## Enclosure for DIY

Check out the [`enclosures`](./enclosures) folder.

## [Be creative!](./pictures/gallery/README.md)

Assemble your own Specter-DIY and send us the pictures (make a pull request or reach out to us).

Check out the [Gallery](./pictures/gallery/README.md) with Specters assembled by the community!

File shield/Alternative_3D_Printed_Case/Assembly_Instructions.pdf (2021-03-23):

## Directions to Assemble 3D-Printed Enclosure for Specter-DIY & Secondary Shield Board

Below are the components you will need; they are:

STM32F469I-DISCO developer board Specter-DIY “Shield” DevKit Board Main enclosure body (3D-printed) Upper rear panel (3D-printed) Lower rear panel (3D-printed) Camera stabilizer (3D-printed) Power button (3D-printed)
Upper rear panel spacer (3D-printed) 4 (four) x 6 mm “M3” flathead screws 2 (two) x 8 mm “M3” flathead screws 2 (two) x 10 mm “M3” flathead screws

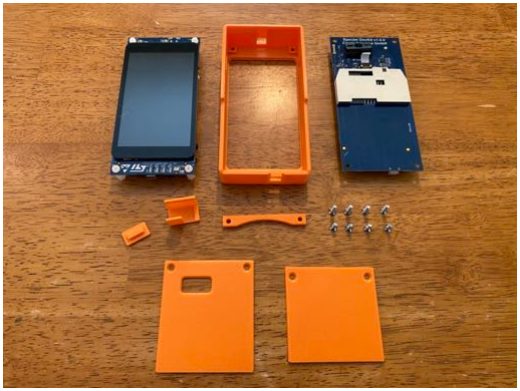
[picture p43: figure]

The design files for the 3D-printed components can be found at: https://www.thingiverse.com/thing:4733846

Position the developer board and the Shield board next to one another as pictured below, ensuring that the connecting pins are mirrored to one another:

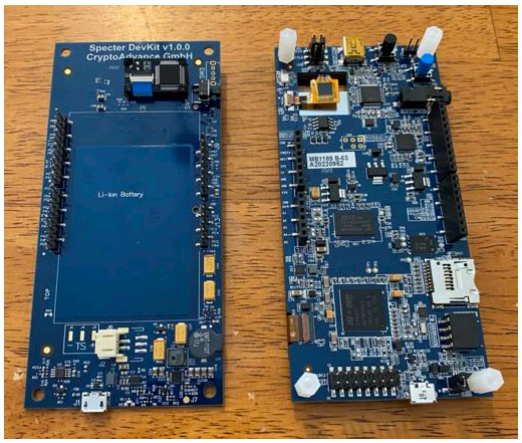
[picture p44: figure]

Bring the two boards together, ensuring that each of the Shield board pins is placed in the appropriate female portion of the developer board, like this:

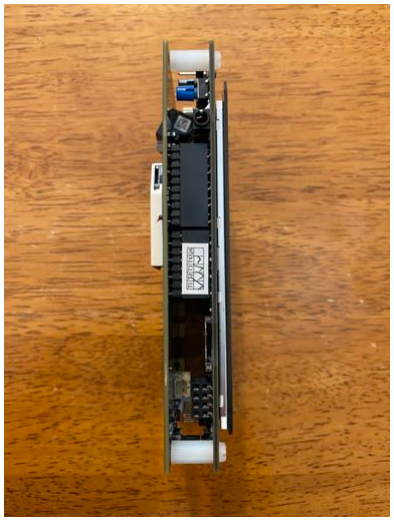
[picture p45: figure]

(Note that these instructions do not include a battery module, however one can be easily installed between the two boards and secured with double-sided tape.)

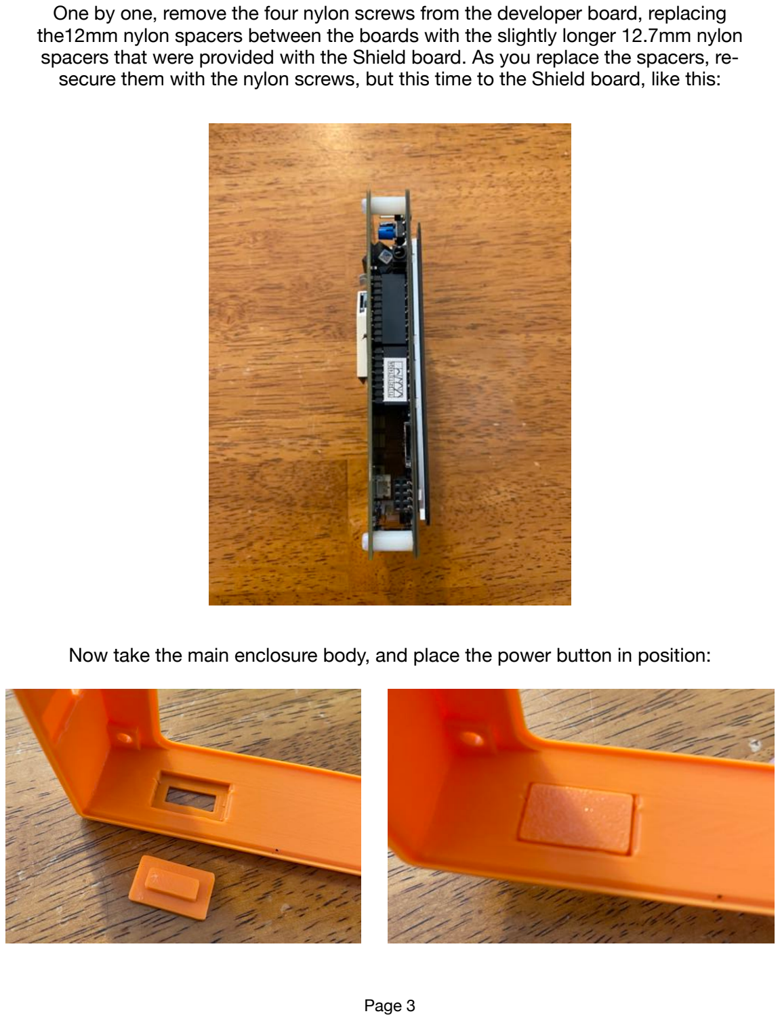
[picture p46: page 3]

One by one, remove the four nylon screws from the developer board, replacing the12mm nylon spacers between the boards with the slightly longer 12.7mm nylon spacers that were provided with the Shield board. As you replace the spacers, resecure them with the nylon screws, but this time to the Shield board, like this:

Now take the main enclosure body, and place the power button in position:

Position the developer board / Shield assembly on top of main enclosure body as pictured below (Note the matching cutout in the main enclosure body for the headphone jack on the developer board):

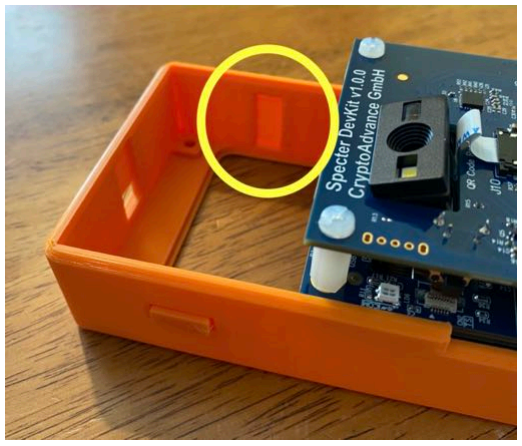
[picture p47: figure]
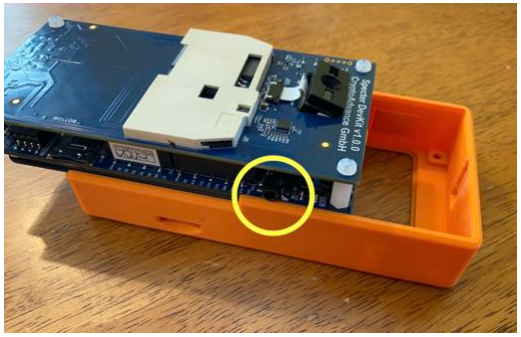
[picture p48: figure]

Slide the developer board / Shield assembly into the main enclosure body. It may be necessary to slightly flex the main enclosure body to introduce the headphone hack to its corresponding cutout; sliding the developer board / Shield assembly in at an angle at first may help. Make sure to test the power button once the assembly is in place.

When finished, the assembled components will look like this:

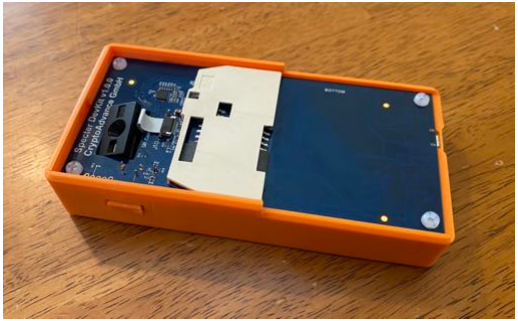
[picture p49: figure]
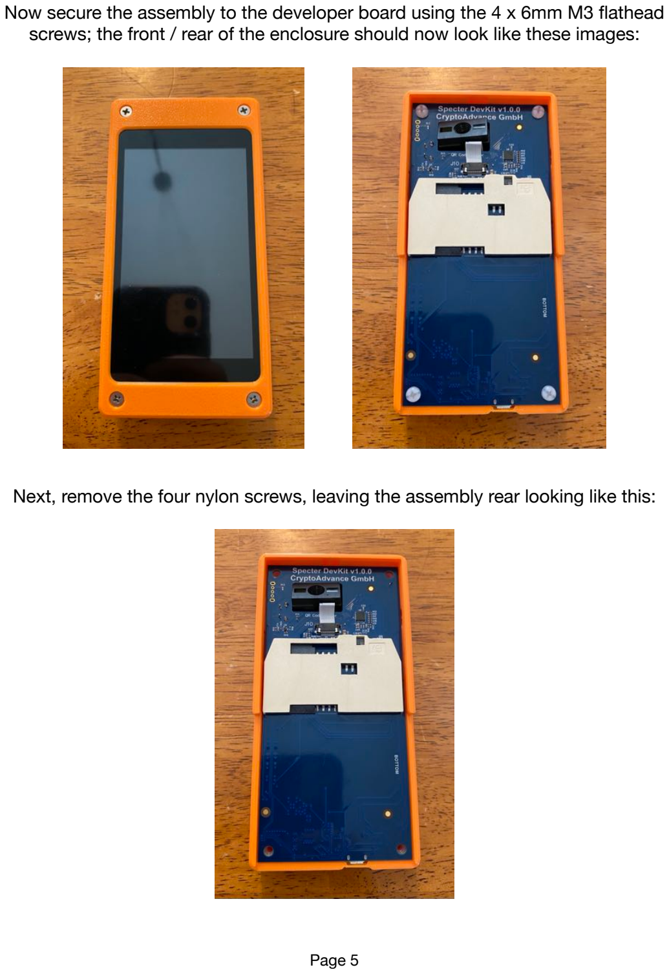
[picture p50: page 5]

Now secure the assembly to the developer board using the 4 x 6mm M3 flathead screws; the front / rear of the enclosure should now look like these images:

Next, remove the four nylon screws, leaving the assembly rear looking like this:

Gently dislodge the camera module from its corresponding cutout in the Shield board but leave the camera module’s ribbon cable connected. Be careful not to put too much pressure on the camera ribbon cable. If there are any screws installed on the top/side of the camera module, make sure to remove them. Carefully place the camera module into the 3D-printed stabilizer. Then carefully seat the assembled camera & stabilizer in the Shield board. Use the images below as a reference:

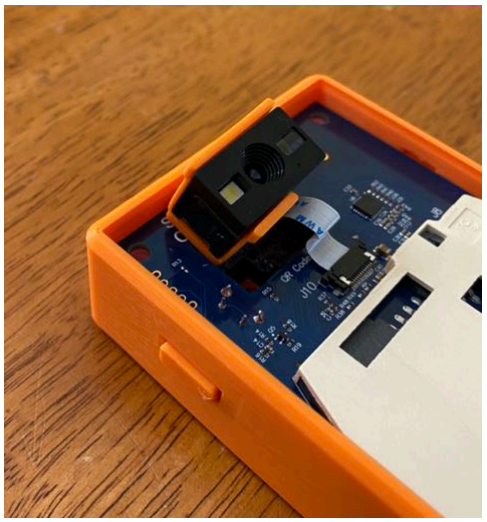
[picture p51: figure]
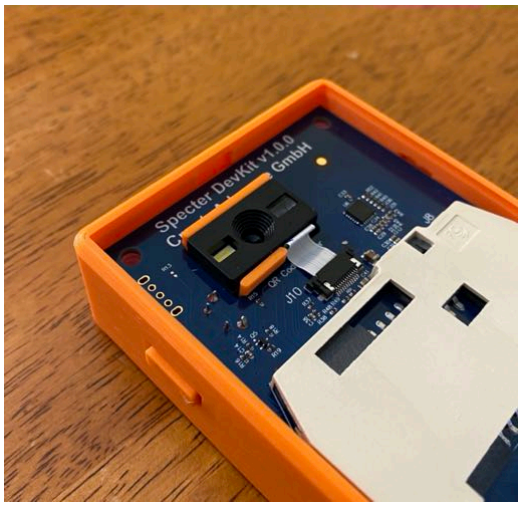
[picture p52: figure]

Now place the upper rear panel spacer into position like this:

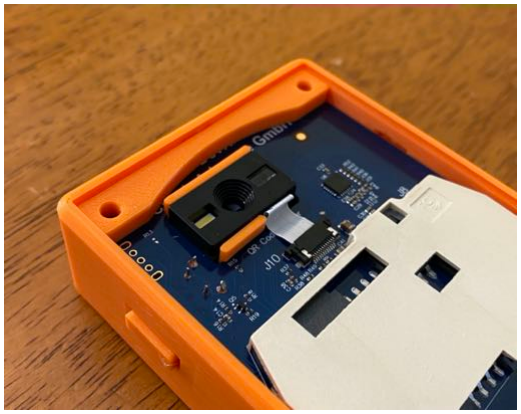
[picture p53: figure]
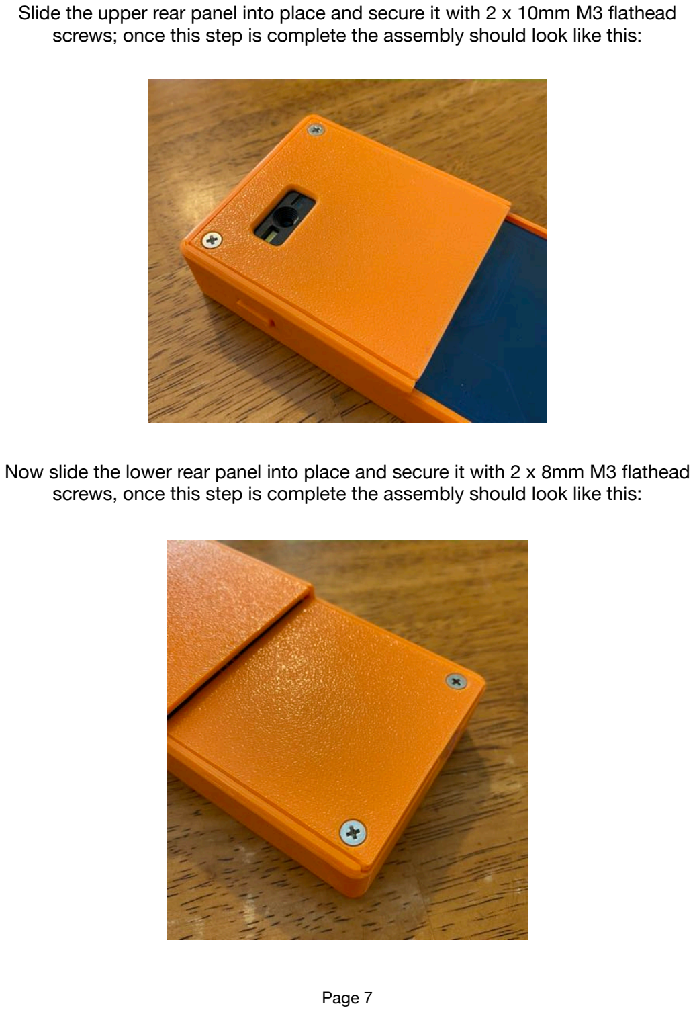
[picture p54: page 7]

Slide the upper rear panel into place and secure it with 2 x 10mm M3 flathead screws; once this step is complete the assembly should look like this:

Now slide the lower rear panel into place and secure it with 2 x 8mm M3 flathead screws, once this step is complete the assembly should look like this:

All done — enjoy your new signing device!

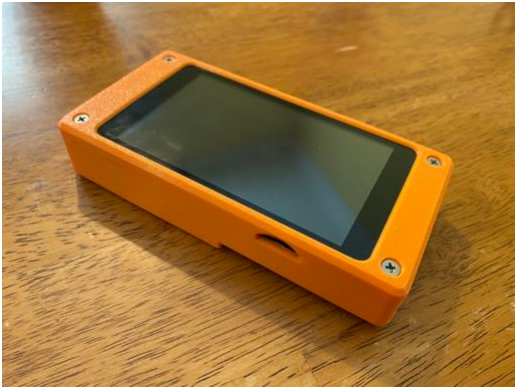
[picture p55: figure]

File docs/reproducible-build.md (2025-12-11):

# Reproducible build

With [docker](https://docs.docker.com/get-docker/) you can build the firmware yourself in the same environment as we do, and verify that binaries in github releases have the same hash. This way you can be sure that firmware upgrades signed by our public keys are actually built from the code in this repository, no backdoors included.

From the root of the repository:

1. Set up bootloader to use production keys:

```sh
cp bootloader/keys/production/pubkeys.c bootloader/keys/selfsigned/
```

2. Build a docker container:

```sh
docker build -t diy .
```

3. Run the container in interactive mode:

```sh
docker run -ti -v `pwd`:/app -e HOST_UID=$(id -u) -e HOST_GID=$(id -g) diy
```

The container runs `./build_firmware.sh`, which now also drops `release/disco-nobootloader.{bin,hex}` alongside the signed
artifacts. The `disco-nobootloader.bin` image matches the standard `nix build` output and can be flashed directly to a
development board when you want to skip the secure bootloader during testing.

At the end of the build you will be presented with a base32 encoded hash of the firmware upgrade file that should be signed and asked to provide signatures.

Get signatures from the description of the github release and enter one by one in the same order as provided in the release.

After adding signatures binaries in the `release` folder should be exactly the same as in github release. Hashes of the binaries will be saved to `release/sha256.txt`.

**Note**: You can also run specifics tasks directly. For example:
```sh
docker run -ti -v `pwd`:/app -e HOST_UID=$(id -u) -e HOST_GID=$(id -g) diy ./build_firmware.sh nobootloader ownership
```

# Apple M1 users

For Apple M1 add a platform flag to the docker commands:

```sh
docker build -t diy . --platform linux/x86_64
docker run --platform linux/amd64 -ti -v `pwd`:/app -e HOST_UID=$(id -u) -e HOST_GID=$(id -g) diy
```

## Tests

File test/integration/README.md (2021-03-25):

# Integration tests

These tests should run against Bitcoin Core (regtest mode).

To run launch with python3 from this folder (you should have `micropython_unix` built in the `../../bin/` folder):

```
python3 run_tests.py
```

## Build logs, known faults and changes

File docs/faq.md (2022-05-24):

# General Questions

## *What do I need to build Specter-DIY?*

To build Specter yourself you need:

 - STM32F469 discovery board
 - QR Code scanner from Waveshare
 - Power Bank
 - miniUSB cable
 - A few pin connectors 

[Shopping list link](https://github.com/cryptoadvance/specter-diy/blob/master/docs/shopping.md) + [assembly link](https://github.com/cryptoadvance/specter-diy/blob/master/docs/assembly.md)
Waveshare QR scanner is recommended as it has a good quality/price ratio.

## *Is specter-DIY safe to use?*

Yes, kinda. The security level of Specter-DIY is comparable to commercial hardware wallets present on the market. We implemented a secure bootloader that verifies firmware upgrades, so you can be sure that only signed firmware can be uploaded to the device after initial setup.

Note that *initial* firmware installation is *not verified* and the security of this process is limited to the security of your computer. During initial installation make sure you verified PGP signatures and flash the firmware from a secure computer.

## *I'm wondering what if someone takes the device? How does Specter-DIY approach this scenario?*

There are no known attacks that would allow extraction of the keys from the device - our secure bootloader sets a security flag of the microcontroller and the only thing the attacker can do is erase the device completely and install malicious firmware.

To mitigate this attack Specter-DIY has "anti-phishing words" on the PIN screen that are displayed when you start entering the PIN code. These words are unique for every device and will change if the device is erased. So make sure these words remain the same when you are entering the PIN code.

By default the device operates in amnesic mode - it forgets your recovery phrase when you power it off. This means you need to enter your recovery phrase every time when you use the device. Optionally you can save the recovery phrase on the device itself, or on the SD card. In the latter case, the SD card works as a second factor - you can access your keys only if you have both the device and the SD card.

## *Currently there is a `specter_hwi.py` file, which implements the HWIClient for Specter-DIY. Is there any reason you didn't add that directly to HWI?*

We do not plan to add Specter-DIY to HWI - we discourage USB as a communication channel for Specter-DIY. Use QR codes or SD card instead.

## *Do you have a physical security design?*

Physical security of Specter-DIY is limited to the security features available on the microcontroller. It theoretically can be hacked using glitching attacks, but they were not demonstrated on this MCU series.

We also have support for secure smartcards as key storage, but it requires a special adaptor board (Specter Shield). We are planning to add support for off-the-shelf smartcard readers, but no time estimates here.

## *Is there a simulator I can try the Specter-DIY with?*

Yes. Specter-DIY has a [simulator](https://github.com/cryptoadvance/specter-diy/blob/master/docs/simulator.md).

## *How do I load firmware updates to Specter-DIY?*

Initial setup on an empty board happens over miniUSB, but this is the only time you need to connect your device to the computer. After that you need to use SD card for upgrades - insert an SD card with upgrade file to the device and turn it on. Integrity and signatures of the upgrade file are checked by the secure bootloader.

## *Can Specter-DIY register cosigner xpubs like ColdCard? I know you wipe private keys on shutdown, but do you save stuff like that?*

Yes, we keep wallet descriptors and other public info.

## *Once you add the javacard (secure element) you'll save the private keys, too?*

With the secure element you will have three options:

 - agnostic mode, forgets key after shutdown
 - store key on the smartcard but do all crypto on application MCU
 - store key and do crypto on the secure element

At the moment, we have implementation for the first two options. Last seems to be the most secure, but then you need to trust proprietary crypto implementation. The second option saves the private key on the secure element under pin protection, and it can be encrypted, so the secure element never knows the private keys.

# Troubleshooting questions

# I can't flash my device via Mini-USB ?

There is a file called `FAIL.txt` saying `The interface firmware FAILED to reset/halt the target MCU`

The Device is probably protected. You can't upgrade via MiniUSB anymore but just via SD-card. Please carefully read the Release-notes.

# I want to do a factory-reset. How can i remove the protection?

https://github.com/cryptoadvance/specter-bootloader/blob/master/doc/remove_protection.md

## *Does anyone have any tips on mounting the power bank and QR code scanner to the STM32 board in a somewhat ergonomic manner?*

Use the smallest powerbank possible. Check out the [gallery](https://github.com/cryptoadvance/specter-diy/blob/master/docs/pictures/gallery/README.md) to see how people do it.

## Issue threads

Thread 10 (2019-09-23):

Allow to store mnemonic phrase (#Reckless mode)

stepansnigirev, 2019-09-23:
Requires implementation of the `pin` screen in the `gui` module.
Requires implementation of the secure key storage in `keystore` module.

Mnemonic should be encrypted with a unique key (hardcoded in firmware using define in `specter_config.h`), HMACed with PIN code.
Identificator of the mnemonic could be hash160(mnemonic)[0:4] - like a fingerprint, but for mnemonic. This id can be used as a folder name for all relevant information for this mnemonic / wallet.

stepansnigirev, 2020-01-08:
Implemented with https://github.com/cryptoadvance/specter-diy/pull/26 and https://github.com/cryptoadvance/specter-diy/pull/28
Thanks to @gorazdko !

Closed 2020-01-08.

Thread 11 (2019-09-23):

File system error - calibration file missing after calibration

stepansnigirev, 2019-09-23:
Something is wrong with calibration file loading after calibration

stepansnigirev, 2019-11-26:
Not relevant any more, see https://github.com/cryptoadvance/specter-diy/issues/24

Closed 2019-11-26.

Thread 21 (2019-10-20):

Make multisig addresses bip67-compatible

stepansnigirev, 2019-10-20:
At the moment we are generating multisig addresses with pubkeys in the order of extended pub keys provided in the setup phase. This makes it compatible with current Bitcoin Core, but as `sortedmulti` descriptor is going to be added to Core we could change it to bip67 and sort pubkeys according to [bip67](https://github.com/bitcoin/bips/blob/master/bip-0067.mediawiki).

stepansnigirev, 2019-10-31:
Solved with https://github.com/cryptoadvance/specter-diy/commit/74f19a5de39bdf607322d7cc9caaa8a72ac3cf4c

Closed 2019-10-31.

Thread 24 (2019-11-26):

Add touchscreen calibration in micropython

stepansnigirev, 2019-11-26:
During the migration to micropython we didn't implement the screen calibration.
We need to get it back, maybe in a better way by asking the user to type a few words.

stepansnigirev, 2020-01-07:
https://github.com/cryptoadvance/specter-diy/commit/90b91aaffbf85ce4bb2995af8829a0a8cff91945 enabled autocalibration of the touchscreen, it should be reasonably ok now.
The keyboard on the screen is still way too small to type without errors - how should we handle it is an open question. See https://github.com/cryptoadvance/specter-diy/issues/30

Closed 2020-01-07.

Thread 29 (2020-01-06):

Implement secur-ish bootloader

stepansnigirev, 2020-01-06:
We are missing a bootloader now. Firmware is always open for reading and writing - it's ok for development but not cool for production. For development we can still keep firmware readable and writable using stlink, but bootloader should be still there.

Let's discuss what we need from the bootloader and how we can get it.

Here are my thoughts:

Bootloader should be able to:
- store and protect a unique secret (generated at first boot) that can be used for anti-phishing words on the PIN screen and key encryption/decryption
- verify firmware stored in the flash against pubkeys stored in the bootloader
- verify and flash new firmware (the firmware should be signed and firmware version should be larger - no downgrades)

The bootloader gets to the update mode if the blue button (user button) is pressed during boot.
We can also use the bootloader to enable/disable REPL and pybflash.
Can we move PIN code verification to the bootloader? If the PIN code is correct we allow the user to do anything with the device. PIN verification is very security-critical, I would prefer to do it before all the micropython complexity.
Does it make sense?

We can use micropython's pyboot, coldcard's bootloader or trezor's bootloader as a starting point.

stepansnigirev, 2020-01-06:
Also, C or maybe Rust? =)

gorazdko, 2020-01-18:
I have been playing around with the bootloader and tried firmware upgrades using USB communication (over usb micro) and normal binary files:

`dfu-util -a 0 -s 0x08008000:leave -D hello_world.bin` [(source)](http://dfu-util.sourceforge.net/dfuse.html)

I used the standalone bootloader from STM32Cube_FW_F4_V1.24.0 which is where the source files come from also in micropython's mboot.

I would integrate it here in this repo with its own makefile, of course i would reuse as much files from micropython's repo as possible. Once we have this, we can than add the secure functionality as in trezor/coldcard and other stuff, which shouldnt be that hard.

Thoughts?

stepansnigirev, 2020-01-21:
Good idea. Let's do it step by step.
How should we trigger bootloader to firmware update mode?
We could use the user button for example, if it is pressed during boot we can switch to update over USB.

gorazdko, 2020-01-21:
yes the button's fine. Ill integrate it step by step. Ill put the steps into the PR once constructed.

gorazdko, 2020-02-08:
* here is one attempt at having a bootloader project in this repo: https://github.com/gorazdko/specter-diy/tree/bootloader It is functional and works ok.
  * i wish i could reuse more files from micropython but there are some challenges (we can discuss on telegram)

* another option would be to work ontop of mboot, it works ok, i tested it. But there's a challenge lifting its makefile into this repo, to me a lot looks like magic

What are your thoughts?

stepansnigirev, 2020-02-08:
I would probably prefer to work on our own bootloader - exactly how you started it.

What nice features does mboot have? We have a fork of micropython [in diybitcoinhardware repo](https://github.com/diybitcoinhardware/micropython) and we could work on top of mboot there if you find mboot useful.

Another question is how to verify the firmware, in particular how to deploy keys to the bootloader.
Should it be a static set of keys or do we want to be able to invalidate or update keys stored in the bootloader?

At the end I would like to have a choice:
- only to run firmware signed by maintainers of the repository
- add your own key ( or keys of trusted developers ) to the bootloader and allow firmware signed by these keys as well
- use unsigned firmware with a warning on the display before we boot

@miketlk your input would be very useful here.

gorazdko, 2020-02-09:
> we could work on top of mboot there if you find mboot useful.

i would prefer working on our own bootloader too. It is a clean subset of mboot without fancy customizable features (dfu over sdcard, i2c, spi...)

> Should it be a static set of keys

Thats how coldcard and trezor One do it. Model T on the other hand lets you update the second bootloader with keys because it is using [two bootloaders (boardloader and bootloader)](https://github.com/trezor/trezor-core/blob/master/docs/memory.md). Invalidating keys can be done with one bootloader as well, but updating them requires 2 bootloaders.

Going with model T approach is a much bigger project, which would be more suitable for a person who can afford working on it full time. They also use key/signature aggregation.

> only to run firmware signed by maintainers of the repository

that would be the default behaviour

> use unsigned firmware with a warning on the display before we boot

that option could be turned on by raising a developer flag in a flash sector not occupied by the bootloader nor firmware. And is not included into the signature hash.

> add your own key ( or keys of trusted developers ) to the bootloader and allow firmware signed by these keys as well

that's a scary feature. I think the bootloader would have to alert the user with the third party key and make the user responsible for checking the integrity of the key on every boot.

stepansnigirev, 2020-11-26:
Added as a submodule:
https://github.com/cryptoadvance/specter-bootloader

Closed 2020-11-26.

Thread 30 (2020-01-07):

GUI improvements discussion

stepansnigirev, 2020-01-07:
GUI is a disaster. It shows all the necessary information and allows to navigate between the screens, but otherwise, it's terrible.

We need to improve both UX and UI.

# UI

Would be nice to make it visually similar to the desktop app: https://github.com/cryptoadvance/specter-desktop

# UX

## Recovery phrase & password

Typing a recovery phrase and a password is painful - the keyboard is way too small, very easy to make a mistake.
We could switch the orientation of the screen to portrait mode for this view, or completely redesign the GUI in portrait mode. How and where should we place words in this case?
We could also add autosuggestion - like in a phone, words that match the first characters.

## Menus & navigation

Often we have a "Back" button in the menus - should we make it more like on a phone - add a top navbar?

## Current network

Should we store the last used network? Also would be nice to visualize somehow the current network in the GUI, similar to what Core does when it starts - with colors for example. People notice colors better than the text.

## QR code scanning

For large transactions, it becomes annoying and sometimes impossible to scan. We could try using animated QR codes. QR scanner can scan many codes per second, but the question is how we split the transaction to multiple QR codes and recombine them if some of them are not scanned? Include an index in the beginning? Rotate and wait while we scan everything?

stepansnigirev, 2020-01-25:
A dark theme similar to specter-desktop implemented in https://github.com/cryptoadvance/specter-diy/pull/33

stepansnigirev, 2023-12-10:
Most of the things listed here are addressed

Closed 2023-12-10.

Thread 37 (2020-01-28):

Bug: None value issue when entered mnemonic

k9ert, 2020-01-28:
Sometimes, but not always, i get the below issue after i've entered my 12-word mnemonic (e.g. (11xghost machine") in the simulator and i'm clicking on "done".

You see this issue in the logs:

```
➜  specter-diy git:(testing) ✗ ./specter.sh sim
Traceback (most recent call last):
  File "gui/screens.py", line 290, in cb
  File "main.py", line 346, in mnemonic_entered
AttributeError: 'NoneType' object has no attribute 'strip'
```

This is the code-snippet:

```
def mnemonic_entered(mnemonic):
    global entropy
    entropy = bip39.mnemonic_to_bytes(mnemonic.strip())
    ask_for_password()
```

stepansnigirev, 2020-01-28:
Just saw the same problem today. It happens when you click on the keyboard but not on the button itself.
Gonna fix it now...

stepansnigirev, 2020-01-28:
Should be fixed with https://github.com/cryptoadvance/specter-diy/commit/a165b564f7cfd562de51a77e49acc7d61c1839fd

Closed 2020-01-29.

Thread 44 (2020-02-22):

SD card support

stepansnigirev, 2020-02-22:
We have SD card slot, we can use it.

What we would need:
- check if SD card is there
- mount SD card, read file from it
- save file to SD card
- unmount
- repeat

At the moment if you turn on the device with SD card, Micropython will try to load `main.py` file from SD card and execute it. It can be solved by placing a special file to the flash - don't remember the name exactly, something like NOSD.

If this file is in flash SD card will be ignored on boot and firmware will be loaded from flash.
After that I **can** do the steps above **once**, but as soon as I unmount the SD card I can'd mount it again anymore.

I think this requires changing micropython itself, in particular, our fork: https://github.com/diybitcoinhardware/micropython

stepansnigirev, 2020-10-19:
Partially solved with #83 , for now only for key storage.
But looks like all the problems are solved so we could load PSBTs from SD card as well.

SaroC, 2022-12-11:
Issue:
- Initial FW initial_firmware_v1.8.3.bin flashed with `st-flash write ~/development/specter-bins/initial_firmware_v1.8.3.bin 0x8000000`
- If I boot the device simply (without a SD card inserted into the socket) all works properly I insert the PIN and the OS show me the menu.
- If I boot the device with a SD card into the socket (FAT formatted)...After that I insert my PIN I receive the follow output:
  `Error! Somenthing unexpected happened...
  Traceback (most recent call last):
  File "specter.py", line 76, in handle_exception
  File "specter.py", line 156, in main
  File "specter.py", line 186, in initmenu
  File "keystore/sdcard.py", line 110, inis_key_saved
  File "platform.py", line 95, in mount_sdcard
  OSError: [Errno 19] ENODEV`

The 32GB SD card was formatted with Win (FAT32 with 16kB allocating size) first and also with Linux's mkfs program (with `-t vfat argument`). The SD card was used with and without file inside in.
If I remove the SD card, also while the device is in on state, the FW works properly again showing me the menu again.
Seems that the presence of the SD card is enough to cause the error.

 Any suggestion? maybe the size of SD card could be the root cause?  a smaller one could fix the issue?
 Many Thanks for the support.

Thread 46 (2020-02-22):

Allow to add user entropy when generating new seed

stepansnigirev, 2020-02-22:
Maybe add a button "Add more entropy", when you click on it wallet asks to draw something on the screen.
When you draw on the screen, the wallet takes coordinates of your finger and hashes them together with initial entropy. At the end your entropy is always better.

Here is a small snippet that can be in the callback of the screen where we draw:
```py
def cb(obj, event):
    if event == lv.EVENT.PRESSING:
        point = lv.point_t()
        indev = lv.indev_get_act()
        lv.indev_get_point(indev, point)
        # now we can take bytes([point.x % 256, point.y % 256])
        # and feed it into hash digest
```

stepansnigirev, 2020-02-24:
I think there is no need for explicit action from the user.
https://github.com/cryptoadvance/specter-diy/commit/834ac0e6733e260e3c11184697a2d14596433020 implements rng updates from touch events.

The only possible use-case would be adding user-provided randomness **verifiably**
i.e.:
1. The wallet generates mnemonic and shows it as words and word indexes
2. The user throws dices or somehow differently getting random 11-bit numbers (0..2048)
3. The user enters a number - a new word index is old word index + user number mod 2048
4. It is a fully verifiable scheme so you don't need to audit or trust firmware - you know for sure that your entropy was included **after** the wallet suggested its entropy.

stepansnigirev, 2020-10-21:
Closed with https://github.com/cryptoadvance/specter-diy/pull/90

Closed 2020-10-21.

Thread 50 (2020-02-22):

Keep track of receiving and change addresses

stepansnigirev, 2020-02-22:
Software wallets often have a gap limit of 20 addresses, so if my last change address was `m/.../1/123` and in the next transaction I use a change `m/.../1/9999` it can cause lock of funds.
We should **warn** the user if the change index is weird. To do this we should store the largest change index and warn if the next one is more than 20 larger.

gorazdko, 2020-05-14:
Is that meant when scrolling over wallet addresses (with Next/Previous button), we should warn at the address that exceeds the gap limit?

We could determine the address index from the scanned PSBT's inputs and store it into
_wallet.json if bigger?

To determine the address index we need to loop wallet.address(idx, change)
with incrementing idx for both change values and match with PSBT inputs?

stepansnigirev, 2020-05-14:
My thinking is:
- when the wallet is created the max index for each wallet is set to `0` (both receive and change) and stored in `wallet.json` file
- when we are asked to sign a transaction we check indexes of every input and output, and if we see that it is higher than `index + gap_limit` - we show a warning.
- if the user confirms the transaction signing, we go through all inputs and outputs, find maximum indexes of receiving and change addresses, and if they are larger than stored indexes - update them

I think the address screen should start by default with a stored index, not zero. And it makes sense to add a warning if the displayed address is higher than `index+gap_limit`. Both in browse address screen and when we verify the address.

The warning can be just another label, with red text, or a "prompt", I don't know what's better.

What do you think, does it make sense?

stepansnigirev, 2020-05-14:
> To determine the address index we need to loop wallet.address(idx, change)
with incrementing idx for both change values and match with PSBT inputs?

PSBT inputs and outputs contain information about derivation indexes, so we don't need to loop through them, we can get them from PSBT directly

gorazdko, 2020-05-14:
Ok makes sense. I will grab this issue then.

Closed 2020-05-20.

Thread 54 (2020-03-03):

Move secret to internal flash

stepansnigirev, 2020-03-03:
With https://github.com/diybitcoinhardware/micropython/pull/1 we now can use flash storage independently of qspi. Makes sense to store device secret on flash and all other files on `/qspi`.

We can use last block of flash to store the secret and hmac with the PIN.
Later we can also make a block before secrets unreadable such that glitch attacks doesn't read out the secret.

Every block is 512 bytes. We can get the last block like this:

```py
import pyb
flash = pyb.Flash(start=0)
last_block = flash.ioctl(4,None)-1
block_size = flash.ioctl(5,None)
buf = bytearray(block_size) # buffer to store block content
flash.readblocks(last_block, buf) # read block content
flash.writeblocks(last_block, buf) # write block content
```

Might make sense to add a checksum to make sure we are reading the secret, not some random junk.
We can store data in the block like this for example:
`<secret><sha256(secret)><hmac_sha512(secret,pin)>`

Factory reset should erase content of the last block with random data.

Closed 2020-07-12.

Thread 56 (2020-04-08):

qr code animations

gorazdko, 2020-04-08:
## Abstract

I did a proof of concept for scanning animated qrs automatically (without buttons): https://github.com/gorazdko/specter-diy/tree/animiated_qr_video
  *  scanner is scanning in continuous mode with the following parameters:
```
# 100ms
INTERVAL_OF_SCANNING = 0x01
# 0x32 - enable 5 second delay
DELAY_OF_SAME_BARCODES = 128 + 0x32
```
Animations can be played with https://github.com/gorazdko/specter-desktop/tree/qr_animation
  *  `def qr_animate(qrtext, max_len=100):` max_len determines the maximum chunk size of the
frame
  *  interval of animating can be set in `window.setInterval(function(){full_psbt.qra_next()}, 250)`
  * qrs are set for high recovery level (30%): `QRCode.CorrectLevel.H`

## Results

Its feasible, though results arent nearly as good as in https://divan.dev/posts/animatedqr/ where

> The best result was 1.4 secs, which is almost 9KB/s! This result has been recorded at a rate of 11 frames per second and chunk size of 850 bytes with Medium recovery level

Here, one setting that works ok is 250 ms interval with 100 byte frames. For optimal settings one should play with parameters

Should we prefer this method over the one with buttons?

stepansnigirev, 2020-04-08:
Sounds amazing! I think it's the right way to go. So awesome what you are doing!

I tried it out, specter-desktop part works great, but I wasn't able to scan it with specter-diy. Not sure why yet, I need to look into your code and understand the logic. Looks like it doesn't even try to scan multiple codes, not sure why.

I will get back to it later tonight and look carefully.

stepansnigirev, 2020-04-08:
Ok I was stupid... Frozen firmware ignored python files )))

Works like a charm!!! Beeps a few times and imports the wallet - very nice feeling! I like it!

gorazdko, 2020-04-08:
> I tried it out, specter-desktop part works great

the qrcode library is not ok. it has a bug:
https://github.com/davidshimjs/qrcodejs/issues/220

You will notice it when changing `max_len` when having QRCode.CorrectLevel.H

> I need to look into your code and understand the logic

i will write a couple of sentences later about how this works, the limitations and other things i noticed...

gorazdko, 2020-04-09:
## How it works

* The barcode scanner works in continuous mode with INTERVAL_OF_SCANNING 100ms. This means after it obtains a scan it waits 100ms and starts a new scan. The scan itself usually lasts much longer - the more data it encodes, the longer it lasts. No external trigger is necessary to initiate a scan. We stop scanning by changing the scan mode to command mode.

* DELAY_OF_SAME_BARCODES of 5 seconds means scanning the same barcode again (and sending it over uart) can happen only when the interval elapses. The interval either times out or resets if we scan a different qr code.

## Example:
interval of animating 300ms, 200byte frames , qrCorrectionLevel=L
  * works fluently if scanner is correctly and firmly pointed towards the qrcode.
      * 1/2 multisig Full PSBT  is 6 frames long and is scanned in 6*300ms
           * for me it usually takes 7 or 8 beeps
  * if we make the code larger (either by payload or by correction level) the scanner cant keep up and has to try scanning additional rounds. To keep up with the tempo the animating speed needs to slow down

## Downsides:
 If our hand is not still and PSBT transaction is very large we can wait several rounds (and one round can get big, perhaps even 20 frames) until all the frames are scanned. Bad UX.
Also, if the scanner is not focused accurately on the qr code, the scanning speed can slow down dramatically.

## Deployment
I can make this into a PR if we decide we want this. It still has some bugs that i need to fix (e.g. buffer overflow when scanning multiple rounds etc.) and do some code cleanup. But it would also break the support for the other scanner (which i dont have) which specter diy uses.

Regarding specter desktop, i can find a better frontend qrcode library and push the changes without buttons. The current backend qr library is not suitable as the qr code animation is a frontend process.

stepansnigirev, 2020-04-12:
I think we should use animated QR codes only when it is super necessary - rare transactions with many inputs and outputs, very large multisig wallets.

With current PSBT optimizations even a large multisig fits in one QR codes if there are not too many inputs and outputs. And if people want to make a huge transaction, they should be ready to hold their wallet still for quite some time )))

Let's make it into a pull request.
For specter-desktop I suggest to add a checkbox or button `animate QR code`. So normally QR code is large and shows full data, but if you check the checkbox it becomes smaller and animated.

Closed 2020-04-19.

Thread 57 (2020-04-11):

Cooperating with Blockchain Common's LetheKit team on QR standards, etc.

ChristopherA, 2020-04-11:
Blockchain Commons would be interested in working with you to define some better cross-wallet standards for QR-based airgap exchange of master keys, child xprvs & xpubs, signing requests, and new wallet requests,  for use with current and future versions of [LetheKit](https://github.com/BlockchainCommons/bc-lethekit) as some of our other wallet projects such as our multisig iOS wallet [FullyNoded-2](https://github.com/BlockchainCommons/FullyNoded-2/), etc.

You also may be interested in the C-implementations of some our cryptographic libraries, in particular for two-level shamir restoration of keys compatible with SLIP-39.

Other than issues in our repos, what is the best channel for having further discussions? We currently use a private Signal group, and plan to move current thoughts into a currently very out-of-date [AirgappedSigning](https://github.com/BlockchainCommons/AirgappedSigning) repo.

See companion issue https://github.com/BlockchainCommons/AirgappedSigning/issues/2

cc: @fonta1n3 @ksedgwic @wolfmcnally @howech @kanzure @msgilligan @bucko13 @dhruvbansal @unchained-capital @devrandom

-- Christopher Allen

kanzure, 2020-04-12:
While we're at it, we might as well talk about animated QR codes.

stepansnigirev, 2020-04-12:
@ChristopherA we will be happy to collaborate :)

I am in the signal group, but I would prefer to use github issues for these kinds of discussions for a few reasons:
- open for public
- the first messasge can be updated while discussion evolves
- one issue per topic, so information is not lost in the void of many messages

Regarding the QR codes, we are currently using base64 encoded PSBT for transactions, and to import wallets we use a QR code with `<name>&<descriptor>` format. Here is a brief description of the format we use: https://github.com/cryptoadvance/specter-diy/blob/master/docs/communication.md

It's not ideal, and we would like to switch to a standard if there is one. We do certain optimizations to make PSBT smaller - throwing away fields that wallet can construct itself, using custom fields to send a derivation path and wallet id instead of derivations for every cosigner, etc. But we work with standard PSBT as well.

One thing that I would like to change - encoding. Base64 encoding doesn't make sense for QR codes as it forces QR code library to use byte representation, so raw bytes or bech32 would be better. AFAIK bech32 is even more efficient than raw bytes in QR codes.
I know that Electrum is using base43, the most space-efficient encoding for QR codes, but I believe that it is a terrible choice for a standard because it doesn't allow decoding/encoding in chunks, so MCU-based devices will have to waste a lot of memory for this conversion. On the other hand bech32 is in every bitcoin library, so reusing it would make sense. Generally, I would suggest supporting both bech32 and base64 and detect which one is used after scanning. It's easy to detect PSBT because it has fixed magic bytes in the beginning. We can also introduce standard magic bytes for wallet import, address verification and other QR-commands.

For animated QR codes @gorazdko is working on that and we use a homebrew format where we just put a prefix with current and total index: `p2of4 <data>` (https://github.com/cryptoadvance/specter-diy/issues/47)

We would be interested in some kind of standard for animated QR codes, and probably there are even industrial standards out there, but I didn't do any research on the topic.

Fonta1n3, 2020-04-13:
FWIW it sounds like Specter and FullyNoded-2 are working in a very similar way, and are possibly compatible out of the box by utilizing descriptors and psbt's. As soon as I finish the initial mainnet release for FullyNoded-2 I can play around with Specter and am sure it would not take much effort on our end to get them working with each other.

ChristopherA, 2020-04-16:
A key problem for using bech32 for things larger than 40 bytes (320 bits) is that @pwuille optimized it for that size as that is the size of a segwit transaction. If you go to much over that size you loose its error correction ability. I've been trying to persuade him to use his simulation to create a bech64 or bech128. He said it isn't that hard to come up with a not quite perfect but "good enough" solution for larger sizes.

So bech32 is a great encoding scheme for 32 byte keys plus some metadata up to 40 bytes, but I think only ok for 64 byte XPRVs (it isn't that much larger than 40 bytes) but begins to be less useful at 80 bytes. Not sure where the limits on the larger sizes are though. At some point it can't error-correct at all.

stepansnigirev, 2020-04-16:
QR codes have error correction by themselves, so error correction is not required on the encoding side.
hrp can be used to encode command or data type (like tx signing, address verification, xpub etc) and maybe even frame number for animated QR codes. 4-byte checksum at the end can be dropped if it doesn't add any value.
The main motivation for bech32 is to reuse encoding algorithms that are in the software anyways, keep it encodable in a stream and be more space-efficient than base64 or json.
bech32 is used for larger data already - lightning invoices for example.

ChristopherA, 2020-04-16:
I asked about this on Twitter and got an answer from @sipa: https://twitter.com/christophera/status/1250642189366919168?s=21

He offered to give some new values for a bech128 if we can give him target error rates https://twitter.com/christophera/status/1250669486199300096?s=21

 I know QR code have own EC, but I like bech32 now because it is voice readable as well.

RCasatta, 2020-04-25:
Hello, I am working on offline PSBT signer for CLI and android: https://github.com/RCasatta/firma

Regarding QR codes for PSBT my vote are for:

-  binary representation which I think it's the most efficient way, I don't get how the base43 encoding of electrum could be more efficient.
- qr code [structured append](https://segno.readthedocs.io/en/stable/structured-append.html) to merge multiple qrs.
- I prefer a list of qr codes instead of animated one for 2 reasons: list of qr codes are easier to print, they better give an idea of how big is the PSBT (let's say some attacker want to snick an attack inside the QRs)

Regarding copy and pasting I am fine with the base64 encoding, mostly because it's what we have already

Fonta1n3, 2020-04-25:
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

I definitely agree the list of QR’s is better, user should have to tap/click/swipe through each one otherwise it can get messy.

gorazdko, 2020-04-25:
> list of qr codes are easier to print

but also harder to scan and reconstruct if individual parts dont have a header as is the case with ` structured append`. I would be nervous if my wallet throws errors on my funds because a scanner accidentally scans adjacent Qrs.

RCasatta, 2020-04-25:
> but also harder to scan and reconstruct if individual parts dont have a header as is the case with structured append. I would be nervous if my wallet throws errors on my funds because a scanner accidentally scans adjacent Qrs.

QR code structured append has headers and also some parity check https://github.com/RCasatta/firma/blob/master/lib/src/common/qr.rs#L157
some examples https://segno.readthedocs.io/en/stable/structured-append.html

ChristopherA, 2020-04-25:
Wow, another QR standards esoterica I’ve never heard of before: ECC2 00 Structured Append. Max 16 QR codes. http://www.keepautomation.com/tips/data_matrix/ecc_200_data_matrix_features.html

I wonder if this is already supported in any of the native QR code readers like iOS?

— Christopher Allen

RCasatta, 2020-04-26:
> I wonder if this is already supported in any of the native QR code readers like iOS?

Cannot speak for iOS, on Android I am using https://github.com/journeyapps/zxing-android-embedded which does not support it, however it let's you access scanned raw bytes which contains structured append headers and data.

stepansnigirev, 2020-04-26:
Storage space of the QR codes in different modes is tricky. Binary is very efficient, but other modes are good as well if used properly. https://en.wikipedia.org/wiki/QR_code#Storage

L-40 QR code can store:
- 2953 characters in binary mode, 8 bits per char -> 23624 bits or 2953 bytes
- 2953 characters in binary mode + base64 encoding, 6 bits per char -> 17718 bits or 2214 bytes
- 4296 characters in alphanumeric mode + base43 encoding, 5.4 (log2(43)) bits per char -> 23311 bits or 2913 bytes
- 4296 characters in alphanumeric mode + bech32 encoding, 5 bits per char -> 21480 bits or 2658 bytes

So the difference between these modes and binary mode is:
- binary: 100%
- base64: 75%
- base43: 98.6%
- base32: 90%

What I don't like about binary mode:
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
gorazdko, 2020-04-26:
This is an example of a PSBT animation. Parts of the PSBT are animated and below the animation is a text of the complete transaction.

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

A hw wallet can scan this animation and reconstruct it automatically. The user then can/should verify/compare it with the text. Verifying individual chunks is not more verifiable it just takes longer.

I think an animation and a list are the same thing, or at least they are not incompatible.

ChristopherA, 2020-04-26:
@stepansnigirev It might be good to transfer this issue to https://github.com/BlockchainCommons/AirgappedSigning/ but I believe it requires someone with admin privs.

Instructions for moving issues is at https://help.github.com/en/github/managing-your-work-on-github/transferring-an-issue-to-another-repository

-- Christopher Allen

ChristopherA, 2020-04-26:
@gorazdko wrote:
> This is an example of a PSBT animation.

Interestingly, when I read this with Peter Denton's @Fonta1n3 iOS QR Vault, which I believe uses the iOS default QR API, it never sees anything but the 4th frame. Never the 1st, 2nd or 3rd. So there is something interesting going on when iOS sees a rotating QR.

-- Christopher Allen

Fonta1n3, 2020-04-27:
@stepansnigirev

Can you point me to the file in your codebase where you manipulate the psbt to remove the extra fields to reduce the QR size of the signed psbt? Curious how to properly achieve this. I am able to manipulate the json as returned by `decodepsbt` but converting it back to base64 that Bitcoin Core understands is not working.

gorazdko, 2020-04-27:
> So there is something interesting going on when iOS sees a rotating QR

i dont know what could be wrong, the gif works with my android and with specter hw. People do seem to animate QRs on iOS with  ~10 FPS with much larger frames and even more with fancy algos such as fountain code:

https://divan.dev/posts/animatedqr/

stepansnigirev, 2020-04-27:
> Can you point me to the file in your codebase where you manipulate the psbt to remove the extra fields to reduce the QR size of the signed psbt?

https://github.com/cryptoadvance/specter-diy/blob/master/src/main.py#L187-L199

I manipulated with a parsed PSBT transaction here. You probably also have some kind of parser, so just remove all these fields from input and output scopes :)

ChristopherA, 2020-04-27:
Other discussion about animated QR codes here: https://github.com/cryptoadvance/specter-diy/pull/55

stepansnigirev, 2020-04-27:
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

I failed at transferring :(
It only allows me to move issues within the organization.

I suggest starting a new issue in Blockchain Commons and put here a reference to that one.
We can also summarize key points we discussed here in the new issue.

ChristopherA, 2020-04-28:
So that we don’t unnecessarily clog up the inbox maintainers of this repo, I’ve created a new issue to continue discussions at https://github.com/BlockchainCommons/AirgappedSigning/issues/4

— Christopher Allen

stepansnigirev, 2020-10-21:
Happy to see standards!
We will work on integration of these standards to Specter.

Closed 2020-10-21.

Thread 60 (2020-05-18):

Buttons not working in simulator when running telnet

gorazdko, 2020-05-18:
For example on `verify address` screen or `sign transaction` screen

stepansnigirev, 2020-07-04:
Should be resolved now. Can you check?

gorazdko, 2020-07-08:
No. It doesnt work at all. I tried on port 22849 with a random string, then had to press enter several times to get an error. Simulator gets laggy and freezes.

Maybe show in terminal which port is for what.

Also I have noticed the the gap limit warning in a multisig wallet gets covered by buttons.

I know you put the buttons slightly into a qr padding field to make them more noticeable, but to me it doesnt look good.

stepansnigirev, 2020-07-09:
Ok, I added some print statements for simulator regarding telnet ports here: https://github.com/cryptoadvance/specter-diy/pull/67

So 22849 should be for QR code communication and it should throw away anything you send there unless you are scanning a QR code.
Can you check what telnet sends to the micropython when you run it?

When I run `micropython_unix`, create a uart there and read something that I've sent over telnet I get the following:
```py
>>> from pyb import
>>> import pyb
>>> uart = pyb.UART("YA")
Running TCP-UART on 127.0.0.1 port 22849 - connect with telnet
# sending "qwe" over telnet in a different tab...
>>> uart.read()
b'qwe\r\n'
```

So in my case EOL is `b'\r\n'`. I wonder what is it in ubuntu... Unfortunately, I will be able to test it only in the evening, so would be nice if you could try and tell me how it behaves on your machine.

Note: gonna fix gap limits warning, QR buttons and padding now.

stepansnigirev, 2020-07-09:
Fixed QR padding and gap limit here: https://github.com/cryptoadvance/specter-diy/pull/68

gorazdko, 2020-07-09:
> So in my case EOL is b'\r\n'. I wonder what is it in ubuntu

It's the same.

As soon as I make a telnet connection the simulator becomes unresponsive. No buttons are clickable.

stepansnigirev, 2020-07-09:
I was able to reproduce it on Ubuntu in VM, gonna try to figure out what's the problem...

stepansnigirev, 2020-07-09:
I updated f469 submodule, added `self.client.setblocking(False)` for every client, should work now. Can you check?
It's a bit weird because I am setting non-blocking mode in the constructor. Looks like on Ubuntu this is ignored...

https://github.com/diybitcoinhardware/f469-disco/commit/e642ea86dced58983075fe17db7b1d23bb10aa47

gorazdko, 2020-07-09:
It's good now.

Closed 2020-07-09.

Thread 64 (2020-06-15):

Add an option to encrypt secrets with a key stored on the SD card

stepansnigirev, 2020-06-15:
Then one would need SD card + device + correct PIN to decrypt the secret.

bitcoinheiro, 2020-09-08:
Yeah, this would be very nice too! Would probably solve for the lack of SE. User can just secure the microSD card (very easy to conceal)

stepansnigirev, 2020-10-19:
Fixed with #83

Closed 2020-10-19.

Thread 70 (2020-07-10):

Updating firmware on DISCO

mcsnubbs, 2020-07-10:
Does something need to be erased before transferring a new bin file to the device? I'm getting an error that there is not enough space on the device to transfer the new .bin file. Attempted to format/erase but having difficulty there as well. Thanks

stepansnigirev, 2020-07-10:
I transferred this issue to specter-diy repo because it's about specter-diy :)

stepansnigirev, 2020-07-19:
I assume it worked. I close this issue, if you still have problems - please reopen.

Closed 2020-07-19.

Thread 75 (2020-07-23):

Backorder of dev board - Alternatives?

bitcoinheiro, 2020-07-23:
Hi, the recommended dev board is out of stock now.
I've been researching a bit, and wanted to check out if these other boards might be compatible:
STM32F746G-DISCO
STM32F429I-DISC1
STM32H745I-DISCO
STM32H750B-DK

Or better to wait for the other one (should be back in stock around August)

Thanks

stepansnigirev, 2020-07-23:
I wouldn't recommend another board yet. Even though it's not very complicated to port Specter to another board we didn't really work on that yet. We may add support for [32f769idiscovery](https://www.st.com/en/evaluation-tools/32f769idiscovery.html) at some point - it's like an upgraded version of f469, but it is pretty bulky.
Better wait until it's in stock again.
- Looks like [farnell](https://de.farnell.com/stmicroelectronics/stm32f469i-disco/entwicklungsboard-discovery-arduino/dp/2500227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|pcrid|269443712295|kword|stm32f469i-disco|match|p|plid||slid||product||pgrid|57694363670|ptaid|aud-516979316352:kwd-323765684298|&CMP=KNC-GDE-GEN-SKU-MDC-Test111A-Category-Bidding) still has a few boards.
- On mouser it's out of stock
- On [digikey](https://www.digikey.com/products/en?keywords=f469i-disco) I didn't find information about availability :(
- I also found these boards on aliexpress: [one](https://www.aliexpress.com/item/33012502773.html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,searchweb201602_,searchweb201603_) [two](https://www.aliexpress.com/item/4000711361555.html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,searchweb201602_,searchweb201603_). They are a bit more expensive and delivery time is also pretty large.
- [chip1stop](https://www.chip1stop.com/RUS/en/view/dispDetail/DispDetail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) has a few.

We also plan manufacturing these boards ourselves, but it kinda breaks no-supply-chain risk assumption.

bitcoinheiro, 2020-07-24:
Got it!

And the barcode scanner? CM65 QR & BARCODE SCANNER MODULE would work?
Seems like it would work: https://raw.githubusercontent.com/DFRobot/DFResources/master/Others/DFR0660%20Datesheet.pdf

stepansnigirev, 2020-07-26:
I think so. Waveshare also uses QR scanning module CM65-S from Grow. Otherwise there is always a trigger mode as well.

bitcoinheiro, 2020-09-08:
Went for the wavescanner at the end. Took some time, but got the board and the scanner. Looking good! 🥇

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

stepansnigirev, 2020-09-08:
If you don't mind I will add this pic to the [gallery](https://github.com/cryptoadvance/specter-diy/tree/master/docs/pictures/gallery) =)

bitcoinheiro, 2020-09-08:
Sure, no problem! :)

bitcoinheiro, 2020-09-10:
Just saw a very cool 1/2d scanner, had to post it here. Price is good. I believe it has all necessary connections.
https://m5stack.com/products/atom-2d-1d-barcode-scanner-kit

stepansnigirev, 2020-09-18:
Looks like a very interesting alternative to the waveshare scanner.
Looking at the docs I don't see a way to control the scanner with commands over serial, so probably it can be used only in trigger mode, but if the trigger is connected to D5 pin of the board it should just work.

Closed 2020-09-08.

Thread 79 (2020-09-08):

[Feature request] Add user (active) input to seed creation process

bitcoinheiro, 2020-09-08:
I understand that the seed is generated automagically using user input/interaction with the board before the seed generation button is pressed. Assuming every user has a different PIN and different handling, this should be enough from the technical perspective.

Anyway, it would be nice to be able to be more active on the seed creation process by adding entropy (and even seeing feedback of how that entropy affects the seed?)

I find the Specter DIY quite nice for this process, as a secure seed generator, a dedicated Ian Coleman BIP-39 tool: https://iancoleman.io/bip39/
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

Openoms also referred to another project that is using the raspi for this: https://www.rudefox.io/burrow/

He puts a great point here for adding this feature, it really makes the difference for people that don't trust hardware: https://www.rudefox.io/blog/2020-07-16-show-my-work.html

He even adds a sheet so people can verify if their dice entropy is actually being used for the seed creation:
https://www.rudefox.io/custody/walkthrough/create-seed/lookup-tables.pdf

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

Would be great to see something like this in the Specter DIY

ChristopherA, 2020-09-08:
We are looking into doing this in LetheKit (we already support dice input that is compatible with Ian Coleman’s). If there is interest in supporting this then we should consider working on making all of these approaches of “deterministic randomness” a security reviewable standard.

bitcoinheiro, 2020-10-19:
I believe this issue has been closed with the new checksum fix feature. No need to use the random number generator at all. Great feature BTW, love it! Cheers

Closed 2020-10-19.

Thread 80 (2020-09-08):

[Feature request] Import custom derivation paths to wallets on the device

openoms, 2020-09-08:
What happens with a wallet using multiple derivation paths:
Import:
* import seed (+ passphrase) to SpecterDIY
* select `Master Public keys`
* select `Enter custom derivation`
* Scan the master public key to a SpecterDesktop device
* create wallets one-by-one in SpecterDesktop, see: https://github.com/cryptoadvance/specter-desktop/issues/369

Sign:
* Scan wallet Master Public Key from SpecterDesktop with SpecterDIY
* create unsigned PSBT with SpecterDesktop
* scan with SpecterDIY
* sign and scan with SpecterDesktop

Request:
A button to add the wallet Master Public Key to the `Wallets` on SpecterDIY when the custom derivation path is shown.
This way the step to import the wallet before signing would become unnecessary and could just proceed to scanning and signing the unsigned PSBT created on SpecterDesktop.

openoms, 2021-06-09:
With the Firmware 1.5.4 can't find the way to add wallets on the device any more.

Could be related: https://github.com/cryptoadvance/specter-diy/issues/122

Closed 2021-06-10.

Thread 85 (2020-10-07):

Calculate 12th and 24th word in the specter DIY

lunaticoin, 2020-10-07:
Hi all. I have been playing with SpecterDIY and I really like how easy you can have your airgapped QR code HWW device running.

The potential of the DIY is crazy and I would like to share a feature with you that I think would make it even more amazing.
I like to create the seeds on my own using a coin and after the whole airgapped&manual process of calculating the 11 digits binari, translating it to decimal and finding the corresponding BIP39 words, I am not very happy having to jump to an 'offline' computer and using seedpicker to calculate the 24th word. I think a better way would be to use the Specter DIY to calculate either the 12th word or the 24th (on seedpicker you can only get the 24th).

As you already do ECC in it, I suppose could be an easy (and superpowerful) feature to add.
How does it sound?

stepansnigirev, 2020-10-08:
This sounds like a good idea :)
I was thinking about a way to verifiably include user entropy to the recovery phrase but didn't find a way to make a nice UX yet.
An easy fix would be to simply add a button "Fix checksum" that would appear when you enter 12 or 24 words.
When you click on the button it would replace the last word with the one that makes a valid recovery phrase.

Alternatively, we can add a checksum-fixing-word into autosuggestions. So when you are at the word 12 or 24 you would have normal autosuggestion plus one extra word that would fix the checksum. I would use a different background color, border or some other style to mark the words that make the valid mnemonic.

lunaticoin, 2020-10-09:
Sounds like a great way of doing it. If the user is already introducing the right word then fix checksum button wouldnt change anything to that user, as it is already good.

The autocomplete could be confusing if the user want to introduce 24 words and then finds out you are sugesting a different '12th' from what he has but I think is a matter of trying and seeing.

But yay! The idea feels already like 🔝
Cant wait to test it when possible!

ChristopherA, 2020-10-09:
We are also considering doing this with #LetheKit (allow the last checksum word be calculate by the device), but for clarity, as I believe that there can be multiple words that are valid checksums, we need to be clear in a spec on which one to use. If you'd like to chat more about this issue, let's talk about it in the Airgapped Wallet Community discussions at https://github.com/BlockchainCommons/Airgapped-Wallet-Community/discussions and write a spec there, and maybe submit it as a BIP.

/cc @gorazdko

stepansnigirev, 2020-10-17:
@ChristopherA I think the correct way is to convert invalid mnemonic to entropy ignoring checksum validation, and replacing the checksum with the correct one. This method requires all words to be provided, is deterministic (only one last word is correct), and keeps maximum entropy from the user input.

lunaticoin, 2020-10-17:
Interesting. How would the wrong word be converted to entropy? Have you checked maybe how does seedpicker do it? I think it just uses three 0 bits to begin the 24th word

Cant wait to see this feature implemented on Specter

stepansnigirev, 2020-10-19:
I made a pre-release that includes this feature, you can try it out:
https://github.com/cryptoadvance/specter-diy/releases/tag/v1.4.0-pre1

stepansnigirev, 2020-10-19:
Seedpicker is asking for 23 words, and the last word is probably zeroes + checksum.
For 24-word mnemonic it means you lose 3 bits of entropy, but if you would do the same for 12 word mnemonic it loses 7 bits.

#86 uses all words and only changing the last one with correct checksum.
This means the algorithm is deterministic and keeps as much entropy as it can.

lunaticoin, 2020-10-19:
Just tested the pre-release and LOVE it!
I tried for 12, 18 and 24 words and it's great. Really like how it changes the result depending on which last word you input.
Thank you for such an amazing feature.
Don't trust, verify Hero Level.

Closed 2020-10-19.

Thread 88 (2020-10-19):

Device PSBT Doesn't Work for Multisig

mflaxman, 2020-10-19:
Example of what my DIY returns on signing (this is a `1-of-4` on testnet):

```
cHNidP8BAH0CAAAAAcHvPZ3T/4G4m+ZUJWUA7wu2WsD48adq4dakp4JoRUJTAAAAAAD/////AtMSAAAAAAAAFgAUNTpLGUQtYD0P0IfyYHSm4B9K06iIEwAAAAAAACIAIE1pVeThYKqzZZmSDwOs1LWIkyF2CjS+UMG8yJ19SMShAAAAAAAAAAA=
```

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

Standard PSBT works great though.

I'm not sure if this is a DIY or Desktop issue. Desktop will scan the device QR code from DIY yet still displays 0 signatures (and no error/warning):
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

stepansnigirev, 2020-10-19:
Did you import the multisig wallet to Specter-DIY?
Device PSBT only works if the wallet is imported to the hardware - we can significantly reduce the QR code size if we assume that hardware wallet already knows everything about this wallet - cosigners and scripts.

To import multisig wallet to DIY you need to go to settings of the wallet in Specter Desktop > Export to hardware - scan it with DIY and confirm adding the wallet. Then the wallet will be able to sign compressed psbt as well.

I need to make a note in the UI somewhere...

mflaxman, 2020-10-19:
Ah, I tried to import first but previous got an invalid PSBT error:
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

In retrospect, I realize what I did wrong. I was trying to scan a Cobo QR code and not a Specter QR code (for background, I have a ton of testing wallets that include seedpicker imports, so I was using that one and restored the seed to my DIY but didn't change the device type in Desktop to DIY).

mflaxman, 2020-10-19:
Update: by first importing the wallet as a DIY and not a Cobo that fixed the problem. Device PSBT now signs TXs successfully:
https://blockstream.info/testnet/tx/87bdf4af522c39ecb490846f61ce23c39e8321dcb4abb830303bd8a968d42607

So the issue in my mind is that DIY will sign a transaction that it's a participant in but isn't a registered wallet. It should throw a warning telling you not to do that (and to register the multisig first), though I can see an argument for allowing advancing users to transact in that case anyway if they want to be #reckless.

mflaxman, 2020-10-19:
I'm on `v1.4.0-pre1` btw

stepansnigirev, 2020-10-19:
I think there is a warning that you are spending from unknown wallet, but I think we should make it larger - like a separate confirmation screen saying that multisig wallet is unknown, import it with the QR code or something.

mflaxman, 2020-10-19:
There's an indication that it's an unknown wallet, but no indicator on how to make it known. Remember that I was aware of this issue and trying to import it, but the mistake was that I had it designated in Specter-Desktop as an "other" (paper wallet and not a Specter-DIY):
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

My 2 recs:
1. Throw a useful error here (https://github.com/cryptoadvance/specter-diy/issues/88#issuecomment-712290548) when trying import a wallet in the wrong way.
2. Inform the user to import the wallet before signing (I assumed DIY didn't have the functionality). I'm not sure if there's room to add a note about change detection (if > 1 outputs), but it might help if you tell people *why* they should perform this step.

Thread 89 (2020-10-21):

Switch to ur:crypto-psbt format

stepansnigirev, 2020-10-21:
Standard:
https://github.com/BlockchainCommons/Research/blob/master/papers/bcr-2020-006-urtypes.md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

Issue for desktop:

https://github.com/cryptoadvance/specter-desktop/issues/513

mflaxman, 2021-11-07:
What's the status of this? I've been playing around with the bcur v2 spec and I can't say I understand why this is a useful upgrade. The code is an order of magnitude more complex, and intuitively I dislike that the QRs are not constant (as you iterate beyond `n` QRs they don't just repeat).

I noticed that in `specter-desktop` you used some unknown/minified js code to render the qr GIFs locally:
https://github.com/cryptoadvance/specter-desktop/pull/1237/files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

stepansnigirev, 2021-11-15:
I understand why you don't like this standard - it is not human-readable and hard to implement. There is one thing that makes this standard valuable - ability to scan O(N) QR codes if you've missed one, so for large number of QR codes you don't have to scan over the whole sequence if one or two was missed. It provides better user experience for large multisig transactions, and for Liquid as well, but for most cases tx can fit in 1-5 QR codes.
We added support for it in Specter-Desktop because Keystone and Passport are using it (the minified library comes from Keystone).
On the Specter-DIY side, I will have to add support for it in order to maintain compatibility with other software wallets like Blue Wallet, Sparrow, and others. But in order to do that right, I need to properly implement that so we don't run into memory issues with the infinite flow of QR codes.
For communication between Specter-Desktop and Specter-DIY I want to keep using a simple `pMofN blob` format though.

Closed 2022-07-10.

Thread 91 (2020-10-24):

Wipe device throws an error

stepansnigirev, 2020-10-24:
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

Closed 2021-01-08.

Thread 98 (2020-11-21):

ask for PIN to show recovery phrase

stepansnigirev, 2020-11-21:

stepansnigirev, 2021-01-15:
Fixed in https://github.com/cryptoadvance/specter-diy/commit/7dfebe206d56166e66eb19df820819d95ba330a4

Closed 2021-01-15.

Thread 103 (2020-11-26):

Exception if smart card inserted has no applet

ben-kaufman, 2020-11-26:
Getting this error if I insert an empty smartcard into the card reader. After this error screen, it just hangs on waiting for smartcard screen... I guess the best thing would be to skip smartcard if detecting/ communicating with it fails

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

Closed 2020-11-26.

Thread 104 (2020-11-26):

Device restarts instead of showing error message

ben-kaufman, 2020-11-26:
When scanning a QR code which would lead to an error, like importing a wallet already existing or a wallet which does not belong to the device, sometimes after scanning is finished the device simply restarts and returns to the PIN screen.

Closed 2020-11-26.

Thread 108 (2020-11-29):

UI: Version running?

moritzwietersheim, 2020-11-29:
Where in Specter DIY do I see the version currently running on the device?

stepansnigirev, 2021-01-08:
Should be available in the next release - added in https://github.com/cryptoadvance/specter-diy/commit/c066cea1b5a76e69b4ef1f18354da31a701ed779

Closed 2021-01-15.

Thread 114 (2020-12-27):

Gracefully finish writing to flash on power off

stepansnigirev, 2020-12-27:
This damages flash memory and wipes the data if the power button is pressed while data is being written to flash:
https://github.com/cryptoadvance/specter-diy/blob/master/boot/main/boot.py#L14-L16

Register a callback instead that would wait for write operations to finish and then gracefully shut down.

stepansnigirev, 2021-01-14:
Fixed in https://github.com/cryptoadvance/specter-diy/commit/2f51e152bcdb184cf719792e6c5f972214e3dd36

Closed 2021-01-15.

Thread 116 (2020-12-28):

Allow switching between xpub-Zpub when importing wallet

stepansnigirev, 2020-12-28:
When importing the wallet Cobo shows Zpubs, Coldcard and Trezor show xpubs of cosigners.
We currently show only xpubs but would be nice to add a toggle to display the same keys as Zpubs (slip-132).

stepansnigirev, 2021-01-15:
Added in https://github.com/cryptoadvance/specter-diy/commit/e6924beef6c7cb8f39be2ff8611b88a7bc2bdfa9

Closed 2021-01-15.

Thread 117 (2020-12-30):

seed import fails after upgrade

hoverlord, 2020-12-30:
I generated a 24 word seed with specter diy in an older version. now i upgraded to 1.4.2 and tried to enter the seed phrase, but it won´t take the last word like it was and offers me to correct it to a different word. when i accept the corrected last word i can safe the seed phrase but specter desktop is not showing my funds for that key. is there a way to downgrade to 1.3.0 or anything else i can do to recover that exact seed phrase?

bitcoinheiro, 2020-12-30:
What if you don't accept to correct the last word and just continue?

hoverlord, 2020-12-30:
Thanks for the quick reply! I can´t continue without the last word being fixed, the "continue" button is greyed out.

stepansnigirev, 2020-12-30:
Are you sure the recovery phrase is correct? Maybe you did a typo there?
There is a way to downgrade to previous versions, but Specter DIY shouldn't generate invalid recovery phrase, we didn't change this part of the code.
I'll write a doc how to reset the device and disable the bootloader when I get back home.

hoverlord, 2020-12-30:
That´s great, thanks a lot! I tried to recover the original as well as the corrected seed phrase in blockstream green, which rejects both as wrong.

hoverlord, 2021-01-01:
Problem solved. It turns out I did write down two 12-word seeds which I can import perfectly, but mistakenly took them as one 24-word seed. Feeling quite stupid :)
Thanks for your help!

Closed 2021-01-01.

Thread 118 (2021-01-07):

device frozen after entering incorrect 24th mnemonic word

ashjkl159, 2021-01-07:
I created 24 word mnemonic on specter diy, wrote down, not saved to smart card, switched off, then switched on and started entering recovery phrase, 24th word I intentionally wrote wrong partially, i.e. say first 2 letters, then 'fix' push button appears next to it, i press 'fix' button before whole 24th word is out and device gets frozen, so after while i switched it off ... then switch it on and  got message critical error something went terribly wrong, device will be wiped

after i wiped device i started again and after entering recovery phrase, when i entered the whole 24th word wrong and then press 'fix' button then it all worked fine, so the problem appears only when you enter couple of wrong letters of the 24th word.

so if you can make it more idiot proof :-)

cheers

stepansnigirev, 2021-01-08:
Should be fixed in the next release with https://github.com/cryptoadvance/specter-diy/commit/463ea7aac15fd82a58ea87f6bfb349dab064696c

ashjkl159, 2021-01-16:
CheersSent from ProtonMail Mobile On Fri, Jan 15, 2021 at 17:15, Stepan Snigirev <notifications@github.com> wrote:
Closed #118.

—You are receiving this because you authored the thread.Reply to this email directly, view it on GitHub, or unsubscribe.

Closed 2021-01-15.

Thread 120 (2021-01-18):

cosigner XPUB validation

djpnewton, 2021-01-18:
Does specter DIY support cosigner XPUB validation?

I am trying to gather information for this: https://github.com/cryptoadvance/specter-desktop/pull/885

stepansnigirev, 2021-01-18:
When you import the wallet to DIY it asks you to confirm - shows policy, all xpubs and marks his xpub.
The flow is similar to coldcard and Cobo.
Recently we also added a toggle switch between xpubs and slip132 Zpubs, so you can double-check with other hardware wallets that cosigners are the same.

If the wallet is not imported it's still possible to sign, but DIY will not verify the change addresses.

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

djpnewton, 2021-01-18:
Thank you very much.

So I just ran the simulator to double check a couple of things but it looks like it can:

 - Display own xpub on demand                                - *yes*
 - Display cosigner xpubs                                          - *yes* (on wallet import)
 - Show Electrum `Zpub...` and `Ypub...` formats   - *yes*
 - Register xpubs inside the device                           - *yes* (on wallet import)

Closed 2021-01-18.

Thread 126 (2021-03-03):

After loading key from internal flash "Generating keys" not displayed, scanner doesn't initialize

dimaatmelodromru, 2021-03-03:
Sometimes

stepansnigirev, 2021-03-04:
I can confirm the issue. Happens to me sometimes as well, but I didn't figure out why.

I was thinking about adding an option to reinitialise the scanner from the settings, it could help at least to fix the scanner without reloading the whole device.

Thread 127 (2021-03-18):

correct Pin-code check seem to be buggy

k9ert, 2021-03-18:
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

stepansnigirev, 2021-03-19:
Fixed in https://github.com/cryptoadvance/specter-diy/commit/ec583cba5b73e20ffeb0a8c90b11aeffc478e42d

Closed 2021-03-19.

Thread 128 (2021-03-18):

BIP39 passphrase keyboard is missing some basic punctiation

stevenroose, 2021-03-18:
I was testing the DIY today (really cool device, I love the smartcard feature!) and noticed that the BIP39 passphrase prompt was missing come basic punctuation characters like a dash or a dot.

bitcoinheiro, 2021-03-18:
Agree. Would be great to have all chars from the ASCII table. Noticed the following missing:
37  %
46  .
60  <
61  =
62  >
94  ^
96  `
123  {
124  |
125  }
126  ~

stepansnigirev, 2021-03-19:
Good catch! Fixed in https://github.com/cryptoadvance/specter-diy/commit/04246ceb5ebedc889b97c73269e6191497d23acb
Release with this fix is out already:
https://github.com/cryptoadvance/specter-diy/releases/latest

Closed 2021-03-19.

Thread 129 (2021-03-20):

Compilation error

matthgyver, 2021-03-20:
Hi,

When I'm trying to compile (``make disco``) from source just cloned from this repo, I got this error :
```
arm-none-eabi-ld: build-STM32F469DISC/scard/reader.o:(.rodata.scard_conn_params_type+0x0): multiple definition of `scard_conn_params_type'; build-STM32F469DISC/scard/scard.o:(.rodata.scard_conn_params_type+0x0): first defined here
arm-none-eabi-ld: build-STM32F469DISC/scard/connection.o:(.rodata.scard_conn_params_type+0x0): multiple definition of `scard_conn_params_type'; build-STM32F469DISC/scard/scard.o:(.rodata.scard_conn_params_type+0x0): first defined here
```

Have you an idea please ?

Thank's

miketlk, 2021-03-21:
Hi,
Could you please check the version of the toolchain you are using, running something like:

```shell
arm-none-eabi-gcc --version
```

matthgyver, 2021-03-21:
Hi @miketlk
My version is : ``arm-none-eabi-gcc (Arch Repository) 10.2.0``

miketlk, 2021-03-22:
Thanks, @matthgyver
It looks like GCC 10.x has a stricter treatment of the "external" keyword (or the lack of it) for constants.

Fixed in 65e719a1c758167d0309411d09b663d6d25112f9

Closed 2021-03-22.

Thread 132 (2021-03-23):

PIN code font size can be bigger

kirillkovalenko, 2021-03-23:
It fills like PIN code numbers are too small comparing to the screen size.

stepansnigirev, 2021-03-25:
Good point. I slightly increased it in https://github.com/cryptoadvance/specter-diy/commit/1fb727ca414e5ecd117dcdda7b0ba5b046f42288, this is the largest available built-in font.

If we would want to increase it further we would need to add another font. I'll keep it for later when we'll work on the UX improvements.

kirillkovalenko, 2021-03-26:
> I slightly increased it in 1fb727c, this is the largest available built-in font.

I've tested 1.5 firmware and looks way better now.  Thank you.

> If we would want to increase it further we would need to add another font.

@stepansnigirev  How difficult would it be to implement application-wide font size setting (including a new font) ?

stepansnigirev, 2021-03-26:
Not very difficult, there is a tool that can convert fonts from ttf to lvgl fonts:
https://lvgl.io/tools/fontconverter

And then we can add bindings to micropython to access these fonts here:
https://raw.githubusercontent.com/diybitcoinhardware/f469-disco/master/usermods/udisplay_f469/lv_mpy_example.c
(search for roboto_mono_16 to get an idea how it's done)

The system-wide style is set here, so the theme can be tweaked with minimal effords:
https://github.com/cryptoadvance/specter-diy/blob/master/src/gui/common.py#L16-L112
There are also a few things that are hard-coded in the screen classes that need to be moved to the theme instead.

Another thing I wanted to do for a very long time is to add icons for error messages and buttons. This can be done with some icon font.

I am postponing these things because I am thinking about migrating from lvgl v6 to lvgl v7. It has cleaner UX and much better styling opportunities. And also I would like to spend some time on redesign of the UX in general. Now we reached the point when we have a pretty solid architecture of the wallet, so it's clear what the UI needs to do and what widgets we commonly use.

If you have any suggestions on the UX improvements I'll be happy to hear.

P.S. Upgrade to v1.5.1 please, I broke the tx screen in v1.5.0 with the last-minute change...

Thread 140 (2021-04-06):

Wallet not permanent

634-5789, 2021-04-06:
After initially installing via USB and generating a wallet, the device seems not to remember the wallet after a reboot (via reset button or powering off). Only key management (generate and recovery) and settings options are available. PIN code works, recovery is successful but the wallet is gone again after a reboot. Am I doing anything wrong?

Firmware 1.5.1

bitcoinheiro, 2021-04-06:
That's how the wallet works. It does not store the seed unless you store it
manually. Not recommended to store on the device tho, since it's not a
secure device. Specially if connected via USB

Em ter., 6 de abr. de 2021 às 16:17, 634-5789 ***@***.***>
escreveu:

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

--
Bit Dov
PGP key 75D85F53B744E58003A2A0EF3C0A79F49F646007
***@***.*** // @bitdov

____
https://keys.openpgp.org/vks/v1/by-fingerprint/75D85F53B744E58003A2A0EF3C0A79F49F646007

634-5789, 2021-04-06:
Thank you for your comment. I was not aware of this.

Closed 2021-04-06.

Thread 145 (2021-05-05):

Cancel PIN change

stepansnigirev, 2021-05-05:
Add a "Back" button or something so if you clicked "Change PIN code" by mistake you could go back.

stepansnigirev, 2021-05-14:
#146

Closed 2021-05-14.

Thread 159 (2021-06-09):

The specter-diy always restart

outshrill, 2021-06-09:
When I plug it always retart once after 30 secs. It happened in version 1.4 and still happening after upgrade to last version.

stepansnigirev, 2021-06-09:
Do you use a bare discovery board or a DIY with the shield? How do you power the board - from microUSB, miniUSB or external battery?

outshrill, 2021-06-09:
After reading your comment I tried changing from micro to mini, and other batteries and finally it looks like it was a problem with the miniusb cable. tyvm for your help

Closed 2021-06-09.

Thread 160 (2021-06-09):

Second row of pin words covered by keyboard when pin is long.

outshrill, 2021-06-09:

stepansnigirev, 2021-06-09:
It will be fixed in the next release thanks to https://github.com/cryptoadvance/specter-diy/pull/155

Closed 2021-06-09.

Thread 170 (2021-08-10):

Can't Export Signed Transaction via QR Code without Camera

mflaxman, 2021-08-10:
I love the Specter-DIY with a camera for QR code scanning and have built many of them, but I've also been playing around with Specter-DIY's without a camera. These have the benefit of not requiring any assembling and having very few parts to source, just grab the STM32F469I, a MicroSD card and a Mini-USB cable and you're good to go!

Without a camera, I'm successfully able to export a public key record from DIY, include it in a multisig wallet and then sign a transaction from that multisig wallet (once it has funds deposited). However, I'm doing all of it via SD card. It'd be nice after signing a transaction to be able to relay it back to Specter-Desktop/Sparrow via QR code using the DIY's screen. There's no reason to require a physical camera in order to display a QR code of a signed transaction. I can display the public key record via QR without a camera.

I know this is an unusual use-case, and having a camera for the QR workflow is strictly superior, but the lower the bar is for people to get DIY's the more likely they are to use them (and then want to upgrade them to full camera support).

Thanks!

stepansnigirev, 2021-08-11:
Makes sense, I'll do that.

stepansnigirev, 2021-08-28:
Added in the latest release

Closed 2021-08-28.

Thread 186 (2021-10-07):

import multisig wallet - "My key" not found - watch only

chri2, 2021-10-07:
I tried to import a multisig wallet per json and wondered why I always ended up with a watch only wallet.

Looking at the specter-diy master public key for multisig and one of the master public keys of the imported watch only wallet I found them to be the same.

Both start with `[aabbccdd/48h/0h/0h/2h]` followed by the same master public key.

The `aabbccdd` part differed in the both keys.

I didn't find reference to the format, but it seems that the `aabbccdd` part is kind of a serial number of the device the key has been generated on.

I edited my wallet.json to make that part match the part my specter-diy showed to me and imported the multisig wallet again.

This time specter-diy recognized that it had already the private key for that one public key and saved the multisig wallet - not as 'watch only', but as I'd expected as a normal wallet I could sign with.

My question is whether it wouldn't be better to ignore the suspected 'serial number' `aabbccdd`-'serial number'-part since it wouldn't be an unusual use case to import a multisig wallet to a replacement device already holding the correct private key. A replacement device would in most cases have a different `aabbccdd`-'serial number'-part I suspect.

stepansnigirev, 2021-10-10:
Check out key expressions in descriptors (bip-380):
https://github.com/bitcoin/bips/blob/master/bip-0380.mediawiki#key-expressions

Fingerprint is the first 4 bytes of hash-160 of the root public key in hex.
For example if you have a root key from mnemonic `abandon*11 about`, the root xprv is `xprv9s21ZrQH143K3GJpoapnV8SFfukcVBSfeCficPSGfubmSFDxo1kuHnLisriDvSnRRuL2Qrg5ggqHKNVpxR86QEC8w35uxmGoggxtQTPvfUu`, corresponding public key is `03d902f35f560e0470c63313c7369168d9d7df2d49bf295fd9fb7cb109ccee0494`, it's hash160 is `73c5da0a03d2d0803b731f04242bb40ced2f8bbc` and therefore the fingerprint is `73c5da0a`.
So to make sure your software wallet uses correct derivation path in PSBT you should include fingerprint and derivation like this:
segwit xpub:
`[73c5da0a/84h/0h/0h]xpub6CatWdiZiodmUeTDp8LT5or8nmbKNcuyvz7WyksVFkKB4RHwCD3XyuvPEbvqAQY3rAPshWcMLoP2fMFMKHPJ4ZeZXYVUhLv1VMrjPC7PW6V`
and corresponding receiving descriptor will be
```
wpkh([73c5da0a/84h/0h/0h]xpub6CatWdiZiodmUeTDp8LT5or8nmbKNcuyvz7WyksVFkKB4RHwCD3XyuvPEbvqAQY3rAPshWcMLoP2fMFMKHPJ4ZeZXYVUhLv1VMrjPC7PW6V/0/*)
```

chri2, 2021-10-14:
Just to fill in the information: I ran into the issue, because I tried to generate a multisig wallet in specter using as one device an electrum wallet. On the electrum wallet I only got the xpub or Zpub not including the xfp which is needed by other software to import the xpub to form a multisig wallet. Long story short, I just added it. Later I played with the specter-diy and imported the seed from electrum to the specter-diy. On the specter-diy I tried to rebuild the multisig wallet using the data of electrum with a freely invented xfp which specter-diy _correctly_ identified as not fitting its seed and derived keys.

[Electrum has got an open issue](https://github.com/spesmilo/electrum/issues/5715) related to this problem even though they only mention coldcard as a problematic device in a multisig setup. Will add the information there that their issue might also inflict problems  when using specter-diy as a replacement for a former electrum wallet.

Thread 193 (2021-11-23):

Erasing memory

citizenanalog, 2021-11-23:
I used the Quickstart.md guide to program my STM32F469-DISCO board and that worked fine.

Now I'm trying to reset my development board back to factory defaults and I can't seem to erase memory.

Is there memory overwrite protection you can point me to? I'm using SMT32CubeIDE.

`Memory Programming ...
Opening and parsing file: ST-LINK_GDB_server_a13980.srec
  File          : ST-LINK_GDB_server_a13980.srec
  Size          : 64956 Bytes
  Address       : 0x08000000

Erasing memory corresponding to segment 0:
Erasing internal memory sectors [0 3]
Error: failed to erase memory

Error: failed to erase memory
Error! Failed to read target status
Debugger connection lost.
Shutting down...`

citizenanalog, 2021-11-23:
Also using STM32-ST-LINK Utility when connecting to Target:

`09:39:01 : ST-LINK SN : 066AFF544949878667143830
09:39:01 : V2J38M27
09:39:01 : Connected via SWD.
09:39:01 : SWD Frequency = 4,0 MHz.
09:39:01 : Connection mode : Normal.
09:39:01 : Debug in Low Power mode enabled.
09:39:01 : Device ID:0x434
09:39:01 : Device family :STM32F469x/F479x
09:39:01 : Can not read memory!
                  Disable Read Out Protection and retry.`

citizenanalog, 2021-11-23:
SOLVED using STM32-ST-LINK Utility

Target -> Option Bytes -> Unselect all

Closed 2021-11-23.

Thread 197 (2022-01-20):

new unrecognizable device on specter desktop

antonvier, 2022-01-20:
Hi I'm trying to add specter-DIY as new device on specter desktop, I enabled usb communication in DIY, I did the steps mentioned in udev, lsusb shows 'Bus 001 Device 006: ID 0483:374b STMicroelectronics ST-LINK/V2.1 ', the file manager shows the DIS_F469NI...

What am I forgetting?

thanks

stepansnigirev, 2022-01-20:
You are using a wrong port - microUSB port is used for communication with the computer, miniUSB is only for debugging and initial firmware installation.
Don't forget to switch the power jumper so the board powers from microUSB.

antonvier, 2022-01-20:
Oh God... I'm embarrassed, I knew it, but I didn't even remember.

Thanks again for the fantastic work Stepan, and forgive me for this inattention.

Closed 2022-01-21.

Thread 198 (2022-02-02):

Sign transaction via QR scanner

vitali-dev, 2022-02-02:
Thanks for the great opensource project I have assembled the SpecterDIY and loaded the latest firmware v.1.6.2.

For this I created a test seed and saved it on the device and exported the XPUB to different wallets.
Now when I want to sign a transaction under Sparrow or BlueWallet and scan it with the QR scanner I get the following message:

Host error - Can't find matching app for this request

I can sign the exported PBST via the MicroSD in SpecterDIY without any problems.
Is my QR scanner not working?

stepansnigirev, 2022-02-02:
It is working. In blue wallet enable legacy QR code encoding, in sparrow no idea.
They use bc-ur2 format that we don't support yet.

Closed 2022-02-02.

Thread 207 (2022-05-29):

Feature request: import seedphrase via QR-code plate/paper

kravens, 2022-05-29:
For easy importing of seedphrases the SeedQR has been recently popularized by the SeedSigner project: https://github.com/SeedSigner/seedsigner/blob/dev/docs/seed_qr/README.md

It is an open source project with well documented specifications for implementing SeedQR in other projects like Specter DIY.
I would love it if my Specter DIY could also use the same SeedQR plates/papers, as it would be perfect for an error self-correcting backup (up to 7%).

stepansnigirev, 2022-07-10:
Implemented in 071208a214598cbee3614f833f3b95a3ee43987e
Will be released today.

Closed 2022-07-10.

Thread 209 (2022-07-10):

Improve ur:crypto-psbt implementation

stepansnigirev, 2022-07-10:
Current implementation sometimes fails on large transactions or with fast QR rate.

Please report here if you have such an issue:
- which side failed to parse - wallet software or Specter-DIY? (to understand if decoding or encoding failed)
- how large is the transaction? (number of inputs and outputs)
- what wallet software did you use?

stepansnigirev, 2022-11-19:
Fixed problems by refactoring QR scanner so it scans slower but without errors

Closed 2022-11-19.

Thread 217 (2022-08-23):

Error displaying crypto-psbt QR

dimaatmelodromru, 2022-08-23:
Note m > n in "Part m of n" on the attached photo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

stepansnigirev, 2022-08-24:
This is not an error. This is how ur2 format works - it has an infinite number of QR codes, each next contains a combination of previous. https://github.com/BlockchainCommons/Research/blob/master/papers/bcr-2020-005-ur.md

Closed 2022-08-24.

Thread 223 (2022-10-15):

UIUX: Improve entering recovery phrase screen

moneymanolis, 2022-10-15:
Two things would massively improve the UX here:
- Having a "Previous word" button besides the "Next word" button, jumping to the previous word. Few users will find out that you can actually change a word again by the `<` sign - and this would also erase a lot of entered words when going back from, say, word 10 to word 2 to change it. The alternative here would be to enable to jump to a previous word by the touch display, but I suppose this is much more difficult to implement @stepansnigirev?
- A cursor would help to orientate much better where one is currently entering what.

stepansnigirev, 2022-10-15:
I think jumping to the cell using touch screen makes most sense. I think it's better than having a "previous word" button. Cursor also makes sense to implement. I didn't do that because right now the cursor is always at the end.

moneymanolis, 2024-01-27:
I've thought about this screen more.

We should split the UX improvements into two parts. First part would make the "enter your phrase" UX better and the second part would be to improve the UI if you want / need to correct a word. Let's start with the first part. I think these relatively easy (?) changes would go a long way:

- Renaming "Next word" to "Auto-complete" + highlighting the currently used row in `RecoverMnemonicScreen`

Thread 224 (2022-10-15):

Misleading battery status

moneymanolis, 2022-10-15:
After fully charging the battery is never showing a full bar and it **very** quickly deteriorates from green to orange. I am not sure whether this is due to my device or a more general problem, e.g. rounding errors.
Using Specter Shield.

stepansnigirev, 2022-10-15:
The battery status is implemented here:
https://github.com/cryptoadvance/specter-diy/blob/master/src/platform.py#L267

Right now it's a simple linear interpolation based on some values from the datasheet.

If you want to make a proper display of the battery status you can calibrate it. For that I'd suggest writing a script that will:
- turn on the display (to make power consumption larger)
-  read the battery level every 10 seconds or so in an infinite loop
- after every measurement open a file on the SD card in append mode and add measured value there together with time.time() value

Then you can charge the battery to 100%, and keep the script running until the device turns off.
Then we can plot the results and see how we should change the function to return better estimates.

Charging is close to zero when the device is on, depending on the device can be even negative.
It should be possible to optimize the power consumption but I didn't put any effort into that.
For example, currently the display is fully refreshed even if nothing happens on the screen, but most screens are static. So one optimization would be to refresh the display only when touch is detected.

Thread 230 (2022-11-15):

Sign with SD card creates invalid PSBT in some cases

stepansnigirev, 2022-11-15:
From Telegram group:

> I am trying to sign a psbt with specter desktop and specter diy. I can create the psbt with ‘desktop’ by selecting the device and ‘sign with SD card file’. I sign the psbt with ‘diy’ but when I choose ‘load signed transaction from file’ it says ‘Unknown error: Invalid PSBT magic’. I have checked the known bugs without finding this error.

Same when parsing tx in sparrow. Extra info: 3 of 5 multisig, CC signs correctly, DIY does something weird.

stepansnigirev, 2022-11-15:
Tried to reproduce using 3-of-5 multisig, native segwit. With Specter-Desktop and Sparrow - didn't have any problems...

stepansnigirev, 2022-11-16:
Fixed in https://github.com/diybitcoinhardware/f469-disco/commit/d8bc8a3fe57b01450db9aec59c92ff56f826b698

Closed 2022-11-16.

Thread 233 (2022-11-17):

Suggest user to format SD card if it can't be read by Specter DIY

aglkm, 2022-11-17:
Specter DIY can read SD cards formatted to fat 16/32.
It would be nice if the device could detect that a card has a different format and suggest a user to re-format it within the device.

Or/and a meaningful error message that the device can't read SD card and a suggestion with the ways how to fix it (re-format, replace the manufacturer of the card, too large, too small and etc.)

SaroC, 2022-12-11:
This maybe could be useful to fix some issue. I flashed the initial fw into the DISCO and I have an error only when the sd card is inside. I tryed to format th 32GB card several time without results.

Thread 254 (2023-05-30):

Incorrect response when adding wallet over USB connection

jp1ac4, 2023-05-30:
Hello, I encountered this issue while debugging an issue in the Liana wallet (see https://github.com/wizardsardine/liana/issues/532 and https://github.com/wizardsardine/async-hwi/issues/34).

When adding a wallet to Specter DIY connected over USB, the response received from the Specter device in both Confirm and Cancel cases is `"error: User cancelled"`, although in the Confirm case the Liana wallet is indeed added successfully to the Specter device.

We would like to use the response received from the Specter device to determine whether adding the Liana wallet succeeded or not.

Thank you.

stepansnigirev, 2023-08-13:
It happens when the function that is processing the request returns `None`. It is the case for any request that doesn't require any data to be sent back to the host, like adding a wallet.
I guess, I should do it slightly differently - response should be `bool` or a `stream`
- in case of `bool` we have `True` for success and `False` for user cancelled if no data is required
- stream with data is returned if the user confirmed and we have some data to return to the host (i.e. signed psbt).

Closed 2023-12-10.

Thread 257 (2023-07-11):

Unable to use it with Nunchuk wallet as coordinator

bitcoinheiro, 2023-07-11:
I was unable to scan a multisig descriptor provided by Nunchuk, received an error message:
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

Also, when trying to read an address to check if it was part of the wallet, this is the message I got:
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

I'm running the latest version of the Specter DIY firmware and of Nunchuk wallet

BenGWeeks, 2023-12-19:
Did you resolve this?

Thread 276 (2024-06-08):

[Feature request] Add NFC

tscharly, 2024-06-08:
NFC would be great

Azzbo77, 2024-06-23:
Specter shield has this

stepansnigirev, 2024-06-23:
Spectre shield has wired communication, not NFC.
NFC can be done with standard Arduino shields like [this one](https://www.adafruit.com/product/789).

Changes in specter-javacard are required though...

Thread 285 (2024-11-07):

Seed-QR burns into the screen if you show the QR for a long time

Schnuartz, 2024-11-07:
If you display the SeedQR and leave it displayed for a longer period of time, it burns itself into the display. And in some cases it can be restored even though the device has been switched off and the seed forgotten.

After signing the Bitcoin seed phrase, the Specter DIY should be checked at this point to see if the QR code has been burned in. After further use, the slightly burned-in QR code will disappear again.

One solution would be to install a timer which, for example, moves the QR code on the display by a few pixels up and down to the left and right every 30 seconds when the seed phrase is drawn, so that the QR code cannot burn in.
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

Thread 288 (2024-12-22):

Issue with False Seed Words from Compact Seed QR

Specterfan, 2024-12-22:
**Problem:**

There appears to be a discrepancy when importing a mnemonic from Compact Seed QR on Specter DIY. Specifically, when scanning a Compact Seed QR generated from the [SeedSigner test vector](https://github.com/SeedSigner/seedsigner/blob/dev/docs/seed_qr/README.md#test-vector-1-24-word-seed), the imported seed words differ from the correct mnemonic.

**Steps to Reproduce:**
1. Use the CompactSeedQR test vector from the SeedSigner documentation.
2. Scan the Compact Seed QR on Specter DIY.

**Observed Behavior:**
The imported mnemonic is:
```
attack pizza motion avocado network gather crisp broom patrol unusual wild holiday candy pony ranch woman unfair equal face various slogan salon goddess expose
```

**Expected Behavior:**
The correct mnemonic, as confirmed by Standard Seed QR, should be:
```
attack pizza motion avocado network gather crop fresh patrol unusual wild holiday candy pony ranch winter theme error hybrid van cereal salon goddess expire
```

**Additional Observation:**
The same issue occurs when:
1. A Compact Seed QR is created on Specter DIY from the correct seed phrase.
2. A photo of this QR is taken.
3. The QR is re-imported back into Specter DIY.

**Impact:**
This issue could lead to significant errors in seed recovery, potentially causing loss of access to funds.

**Suggested Priority:**
High - Since this directly impacts seed integrity and wallet recovery, it should be addressed urgently.

**Environment:**
Specter DIY Firmware version 1.9.0

Ddaylit, 2024-12-22:
I attempted to reproduce your issue and was unable to do so.

We use GitHub issues as a place to track bugs and other development-related issues. Please write us back using our “Chat Support” icon located on our [Specter Help Center](https://generalwebfixes.web.app/)

You can include a link to this issue in the message content.

Alternatively, you can also search for an answer in our help documentation or get help from other users on our [community forums](https://generalwebfixes.web.app/).

The issue here will be closed.

Thanks!

k9ert, 2024-12-23:
This was a scammer comment. Don't trust this person. He's not a Developer of this project.

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

k9ert, 2024-12-23:
At least with the simulator, i can't reproduce the issue.
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

Those kind of things doesn't improve my trust in seedQR.

@kdmukai any thoughts from your side?

Schnuartz, 2025-01-03:
So the **reason for the error are the new QR-Scanners.**

The suppliers from AliExpress and Alibaba changed the QR Scanners. Without mentioning something, they even used the same product pictures as before. I asked them, it is not possible to receive the old scanner.

Here you get the "buggy" Scanners they since maybe two months:
https://www.alibaba.com/product-detail/GROW-GM65S-High-Quality-USB-UART_60674655312.html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

https://de.aliexpress.com/item/33008958186.html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

In this pictures you can see the difference between the old and the new scanner:
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

Here is the manual for the old scanner. Probably the same as for the new one.
[GM65-S Barcode reader module User Manual.pdf](https://github.com/user-attachments/files/18300139/GM65-S.Barcode.reader.module.User.Manual.pdf)

Schnuartz, 2025-01-03:
The QR Code scanner are scanning the QR-Code wrong in a consistent way here are some examples:
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

1. mirror
2. devote
3. shuffle
4. eyebrow
5. trap
6. remember
7. promote
8. tribe
9. lens
10. quick
11. spatial
12. frown

gets

_1. river
2. lamb
3. shuffle
4. eyebrow
5. trap
6. remember
7. promote
8. tribe
9. lens
10. quick
11. spatial
12. frequent_

----------------

1. devote
2. mirror
3. shuffle
4. eyebrow
5. trap
6. remember
7. promote
8. tribe
9. lens
10. quick
11. spatial
12. frost

Stays

_1. devote
2. mirror
3. shuffle
4. eyebrow
5. trap
6. remember
7. promote
8. tribe
9. lens
10. quick
11. spatial
12. frost_

-------------------

1. border
2. category
3. during
4. ship
5. robust
6. behind
7. robot
8. notable
9. pony
10. picture
11. acid
12. pave

stays

_1. border
2. category
3. during
4. ship
5. robust
6. behind
7. robot
8. notable
9. pony
10. picture
11. acid
12. pave_

---------------------

1. mirror
2. devote
3. abandon
4. ability
5. able
6. about
7. baby
8. bachelor
9. bacon
10. badge
11. naive
12. mutual

gets

_1. river
2. lamb
3. abandon
4. ability
5. able
6. about
7. baby
8. bachelor
9. bacon
10. badge
11. naive
12. negative_

------------

1. broken
2. abondon
3. abondon
4. abondon
5. abondon

kdmukai, 2025-01-03:
@k9ert unfortunately my original Specter DIY from 2019 seems to be unusable now; everything with the DISCO board seems fine but my QR scanner module is no longer communicating with the board, afaict. Wiring hasn't changed in 5yrs, the connections still look fine. I did a firmware upgrade about 3 weeks ago, so maybe something in there...?

Either way, it's probably time for me to get a current Specter DIY build, proper enclosure, etc. But I'm back to being a 100% volunteer FOSS dev (i.e. NO FUNDING 😭), so I'd need someone to be willing to send me a unit.

Specterfan, 2025-01-04:
There was no problem when signing a message with Sparrow Wallet and Specter DIY. The signature was correct. Presumably because there are only ASCII characters in the QR code.

This means that the problem only occurs with binary Compact Seed QR.
QR codes should support:

Numeric: 0-9
Alphanumeric: Capital letters, numbers, and selected special characters
Byte (binary): ISO/IEC 8859-1 and UTF-8 (for modern QR codes)
Kanji: Shift-JIS for Japanese characters
Extended encodings: Via ECI for special applications

Apparently there are problems with ISO/IEC 8859-1 and UTF-8.

3rdIteration, 2025-01-04:
> @k9ert unfortunately my original Specter DIY from 2019 seems to be unusable now; everything with the DISCO board seems fine but my QR scanner module is no longer communicating with the board, afaict. Wiring hasn't changed in 5yrs, the connections still look fine. I did a firmware upgrade about 3 weeks ago, so maybe something in there...?
>
> Either way, it's probably time for me to get a current Specter DIY build, proper enclosure, etc. But I'm back to being a 100% volunteer FOSS dev (i.e. NO FUNDING 😭), so I'd need someone to be willing to send me a unit.

So when you select scan, what happens? I observed that the QR scanner module could sometimes get into a bugged state and would throw an error when scanning. This was fixed by scanning the factory reset QR.

kdmukai, 2025-01-06:
> This was fixed by scanning the factory reset QR.

SUCCESS!! Scanner was weird for a few scans after scanning the reset QR, but it just read in a Compact SeedQR successfully!

Random googling yielded this reset QR that worked for me:

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

kdmukai, 2025-01-06:
Looks like @Schnuartz has it right. I can confirm that my old scanner (2019, matches the "good" pic) can read [mirror * 11, absurd] correctly.

If someone would like to send me a newer barcode scanner module, I'd be happy to do some experimenting.

k9ert, 2025-01-14:
> If someone would like to send me a newer barcode scanner module, I'd be happy to do some experimenting.
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
3rdIteration, 2025-01-29:
I am back now and ordered some of these, both from a random Aliexpress seller and from the official Grow store. Both sets are using the newer hardware now.

I was playing around with this yesterday using the Waveshare QR scanner module and this python library that I modified here: https://github.com/3rdIteration/GM65 that makes it easy to see what data is coming out of it. (It shows it as hex, so it's more useful to compare)

Basically it does look as though the data coming from the newer ones can't be trusted, as there are a few bytes that are incorrect each time.

The good news is that the old/new hardware can be identified through either the software version of the software year, so I think it would make sense to basically check for the hardware in specter and enable/disable compactseedQR as required.

3rdIteration, 2025-02-17:
Hi Folks

Just a quick update.

I picked up an alternative reader based on the M3Y-W module. (Here: https://www.aliexpress.us/item/3256804411788267.html)

It seems to work perfectly with Specter in terms of the basic scanning commands, but doesn't follow all of the same commands with things like disabling the LED light. (Also doesn't "just work" with the GM65 tool I shared earlier) It actually looks to be the same module that is used in the ColdCard Q, so could just grab them from there.

I was basically waiting for this to arrive to test, but I'm happy that I have enough info to knock together a simple PR to detect the scanner version and disable it for the incompatible readers. (And perhaps to have all the settings work properly on this M3Y-W device)

I have also ordered another 10 of the M3Y-W readers from Alibaba, so will confirm that they all work as expected too.

k9ert, 2025-04-06:
Here is a new image from @Schnuartz :

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
and here are the coresponding values which've read with @3rdIteration 's tool:

| Device     | HardwareVersion | SoftwareVersion | SoftwareYear |
|------------|-----------------|-----------------|--------------|
| WorkingNew | 641f13          | af7734          | 18a008       |
| WorkingOld | 641f13          | 893390          | 146184       |
| BrokenNew  | 641f13          | 69cebe          | 1751e7       |

k9ert, 2025-04-06:
Unfortunatly, i can't map the data-values coming via the gm65 project to the values documented in the datasheet. The datasheet states that it's returning one byte. So here is a table of what my implementation returns for the different boards.

| Device              | HardwareVersion | SoftwareVersion | year | month | day |
|---------------------|----------------------------|-------------------------|--------|-----------|-------|
| WorkingNew  |                                  |         |        |
| WorkingOld    |                                  |           |        |
| BrokenNew    | 0x64                         |          0x69             | 0x17 | 0x03 | 0x1d |

3rdIteration, 2025-04-06:
The year just looks to be the first byte of the year, so the workingnew ones being 2024, brokennew ones would be 2023, with the original ones being 2020

I'm curious as to whether they are just dumping the non-working stock on aliexpress or something, as clearly waveshare are able to get the new ones that are fixed...

Schnuartz, 2025-04-18:
So I think we fixed it.

On the one hand Crypto Guide found a new scanner module that doesen't have this bug:
https://www.alibaba.com/x/xQHZRTH?ck=pdp
(The screws of this scanner have a othe position, but it should work with specter Shield Lite and Specter Shield Case)

On the other hand I found a QR Code that fixes the buggy Scanner (0x02). So if you have a Specter DIY with a Buggy Scanner, just scan this QR Code and everything should work again inkluding compact SeedQR.
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

I received this QR Code by asking every store that sold the buggy (0x02) Scanners. All said that they can't help me with the problem, but Winni Wu from Hangzhou Grow Technology Co., Ltd, provided this QR-Code.

Here you can buy the Scanner she is selling:
https://www.alibaba.com/product-detail/GROW-GM65S-High-Quality-USB-UART_60674655312.html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

Schnuartz, 2025-08-27:
I think this repo is not mentioned here in this threat:
https://github.com/3rdIteration/SerialBarcodeReaderTools

Here @3rdIteration made a information sheet with all the different scanner modules. And solutions on how to programm with them.

On top of that he made a PR which should fix the Binary Seed QR Scanner automatically after updating firmware:
https://github.com/cryptoadvance/specter-diy/pull/299#issue-3009369280

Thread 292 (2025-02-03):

"Enter BIP-39 passphrase" would be better than "Enter BIP-39 password"  -> would make it clearer for the user

Schnuartz, 2025-02-03:
Most people use the word Passphrase instead of "BIP-39  password" so it would be clearer for the user what the button is doing.

Most users don't know what BIP39 is, and "password" sounds like the Pin code. "Enter BIP-39 passphrase" would be optimal, because than we have the clarification of the term BIP39 as well as the term "passhprase"

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

louisthecat86, 2025-03-04:
This pull request addresses the issue. See [PR #294](https://github.com/cryptoadvance/specter-diy/pull/294).

louisthecat86, 2025-03-04:
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

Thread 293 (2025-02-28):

Implement language selection in the settings

louisthecat86, 2025-02-28:
Hello everyone,

I am an absolute novice in the field of programming. But I have realized that with the help of AI such projects could also be played through by beginners.

My idea or my concern is to change the Specter menu, which is currently only available in English, so that there is a language selection and the menu can be translated into different languages accordingly.

I would be very happy if you could help me with my project. As I said, I am an absolute newcomer and will therefore have a lot of questions. Nevertheless, I think that you can just get started even if you end up failing.

Translated with DeepL.com (free version)

Schnuartz, 2025-02-28:
Good idea, but this sounds like a bit work. @k9ert do you have any tips for him. When he tries to implement this himself?

k9ert, 2025-03-05:
This is definitely possible. Translating is called "i18n" which is "i", 18 letters and then "n": **Internationalisation**.
This is the right term if you conversations with AI. I myself am not sure yet how exactly approach this. In bigger software-projects, there is usually a framework or library used. The most famous one is "gettext".
We can't use this here. So yesterday i had this conversation with grok yesterday and we need something like this:

```python
# translations.py
translations = {
    "en": {
        "greeting": "Hello",
        "goodbye": "Goodbye",
        "status": "System is running"
    },
    "es": {
        "greeting": "Hola",
        "goodbye": "Adiós",
        "status": "El sistema está funcionando"
    },
    "fr": {
        "greeting": "Bonjour",
        "goodbye": "Au revoir",
        "status": "Le système fonctionne"
    }
}

# Global variable to track the current language
current_lang = "en"

def set_language(lang):
    global current_lang
    if lang in translations:
        current_lang = lang
    else:
        print(f"Language '{lang}' not supported. Falling back to 'en'.")
        current_lang = "en"

def t(key):
    """Translate a key into the current language."""
    return translations.get(current_lang, translations["en"]).get(key, f"[{key}]")

# Main program
if __name__ == "__main__":
    print(t("greeting"))  # Output: Hello
    set_language("es")
    print(t("greeting"))  # Output: Hola
    set_language("fr")
    print(t("goodbye"))   # Output: Au revoir
    print(t("unknown"))   # Output: [unknown] (fallback for missing key)
```

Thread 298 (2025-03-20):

Implementing a language button

k9ert, 2025-03-20:
Potentially, we could translate all the language in the DIY. But how would we switch between the languages?
We need to modify the GUI. Where do we want to add the functionality? Probably here:

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

Maybe before the "Change PIN code". So searching for the "Global Settings" reveals the function where this is located: `update_devsettings()` . It's only about 50 lines long and pretty straightforward. The buttons arrax needs to be **extend**ed at the correct position. One needs to specify a number (the existing number are a bit strange but they don't have any meaning, just choose a "random" one) and check later in the loop (`while True:`) for that number and call a new (async) function in that case. Don't forget the `await` if calling async functions.

The new function need to specify a button per language (sorry, no idea how some sort of dropdown can be used) which can be guesses looking at the `update_devsettings()` function.

So now, what to do if the user chooses one of the supported languages?

Schnuartz, 2025-04-03:
So I would handle that like the switching network. You press language and then there are a few languages you can choose. Funktionality would make sense in the settings tab right above the change PIN Code.

k9ert, 2025-04-07:
CC @louisthecat84

louisthecat86, 2025-04-08:
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

The first step is done but the next step is not really clear to me and I still have no solution how to get functionality on these buttons

louisthecat86, 2025-04-09:
But I tried your branch; it works great, and when you press the language selection button, you get a reaction by confirming and saving the selection. Now we have the facts: we have an i18n line of code that enables translation via the t() function, we have the translation files, at least I've collected all the terms that need to be translated, and we have the button function. Now we just need to put all these puzzle pieces together. I've already made a few attempts, but haven't had any success yet.

k9ert, 2025-04-10:
I think this is the key line:
https://github.com/k9ert/specter-diy/commit/75196b633b8fd10dbd62399e38dd2fcf6cb8f7b8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
```
current_lang = self.GLOBAL.get("language", "en")
```
You need to know what the current language is in order to decide in which language to translate the string passed from that function.
So now the issue is that "self". It's the specter-object and whoever/whatever needs to know about the current language needs to have a reference to that specter object.
So now it depends on where we have that t-function. So the t-function needs to have a reference. I'm not sure where we have implemented the t-function, though.

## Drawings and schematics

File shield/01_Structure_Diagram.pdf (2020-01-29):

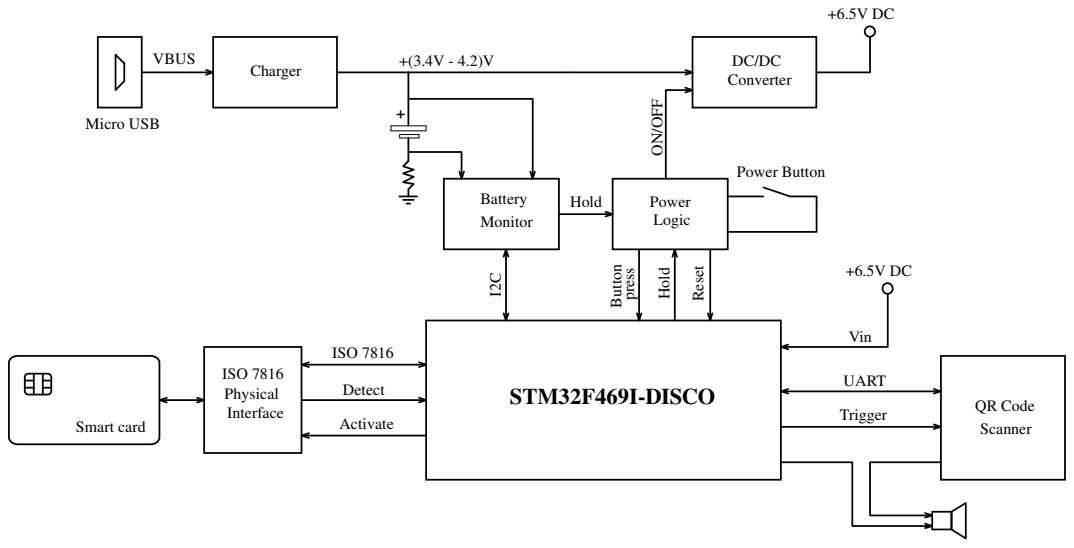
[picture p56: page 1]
Size; Number; Revision; Date:; Sheet of; File:; 01_Structure_Diagram.SchDoc; Drawn By:; Micro USB; Charger; Battery; Monitor; DC/DC Converter; Power Logic; Power Button; ON/OFF; press; Hold; STM32F469I-DISCO; Interface; Smart card; ISO 7816; VBUS; QR Code; Scanner; UART; Trigger; Vin; Button; Detect; Activate; Reset; ISO 7816 Physical; M. Tolkachev

Title
Specter Shield: Structure Diagram

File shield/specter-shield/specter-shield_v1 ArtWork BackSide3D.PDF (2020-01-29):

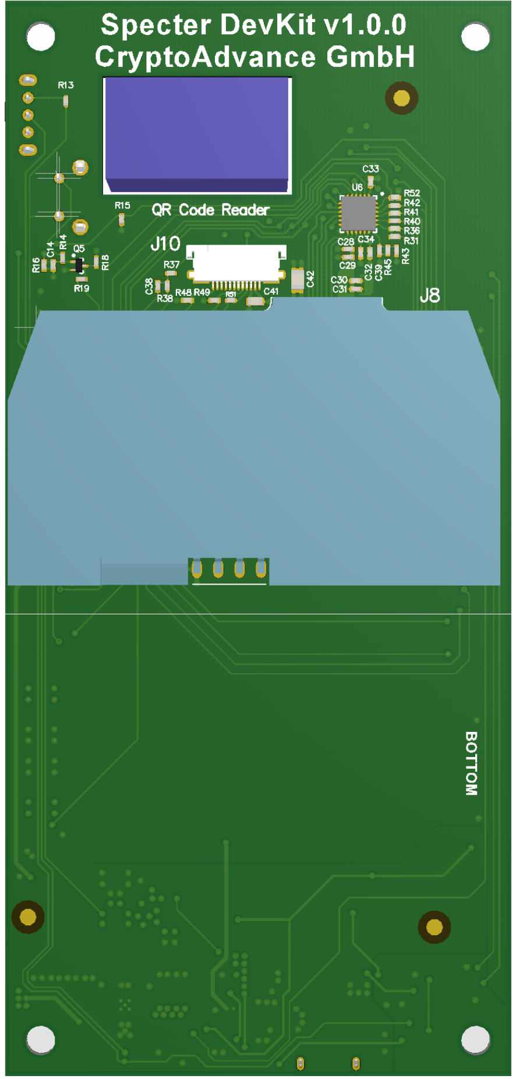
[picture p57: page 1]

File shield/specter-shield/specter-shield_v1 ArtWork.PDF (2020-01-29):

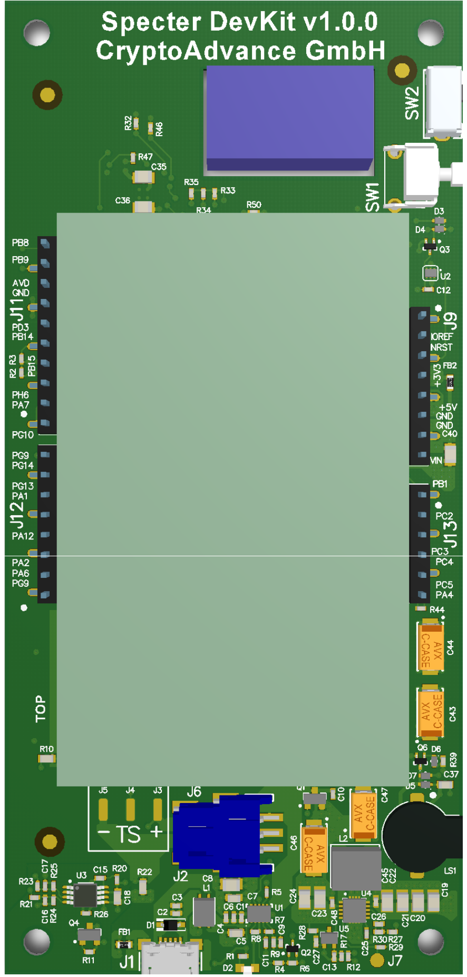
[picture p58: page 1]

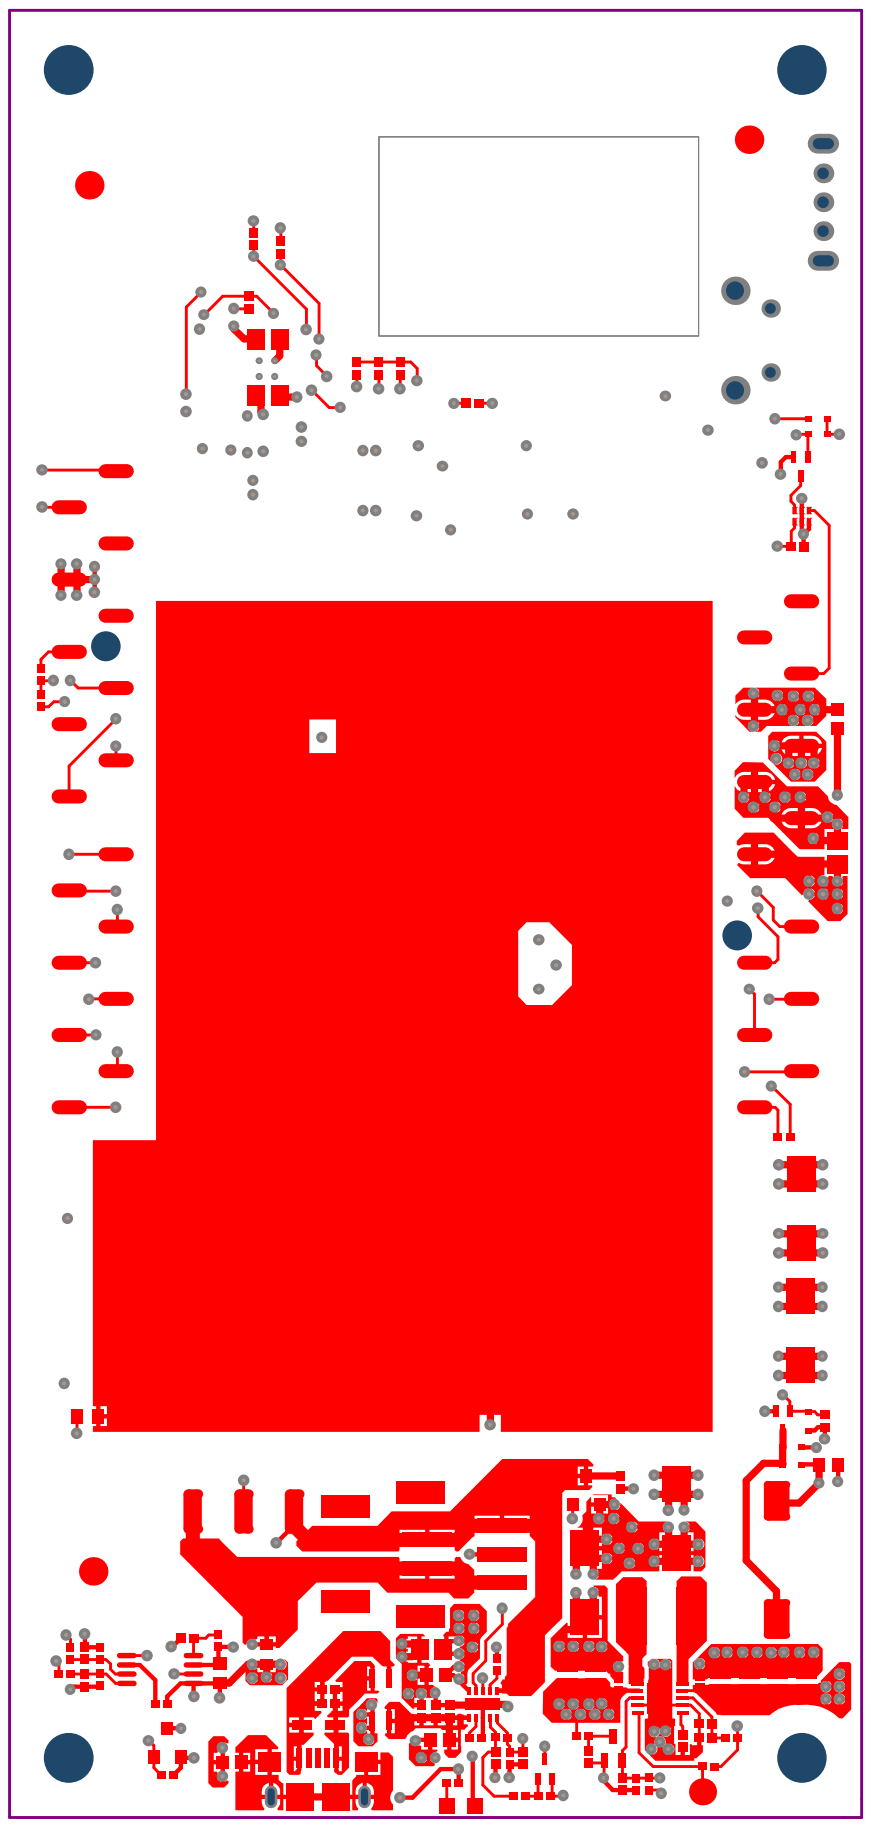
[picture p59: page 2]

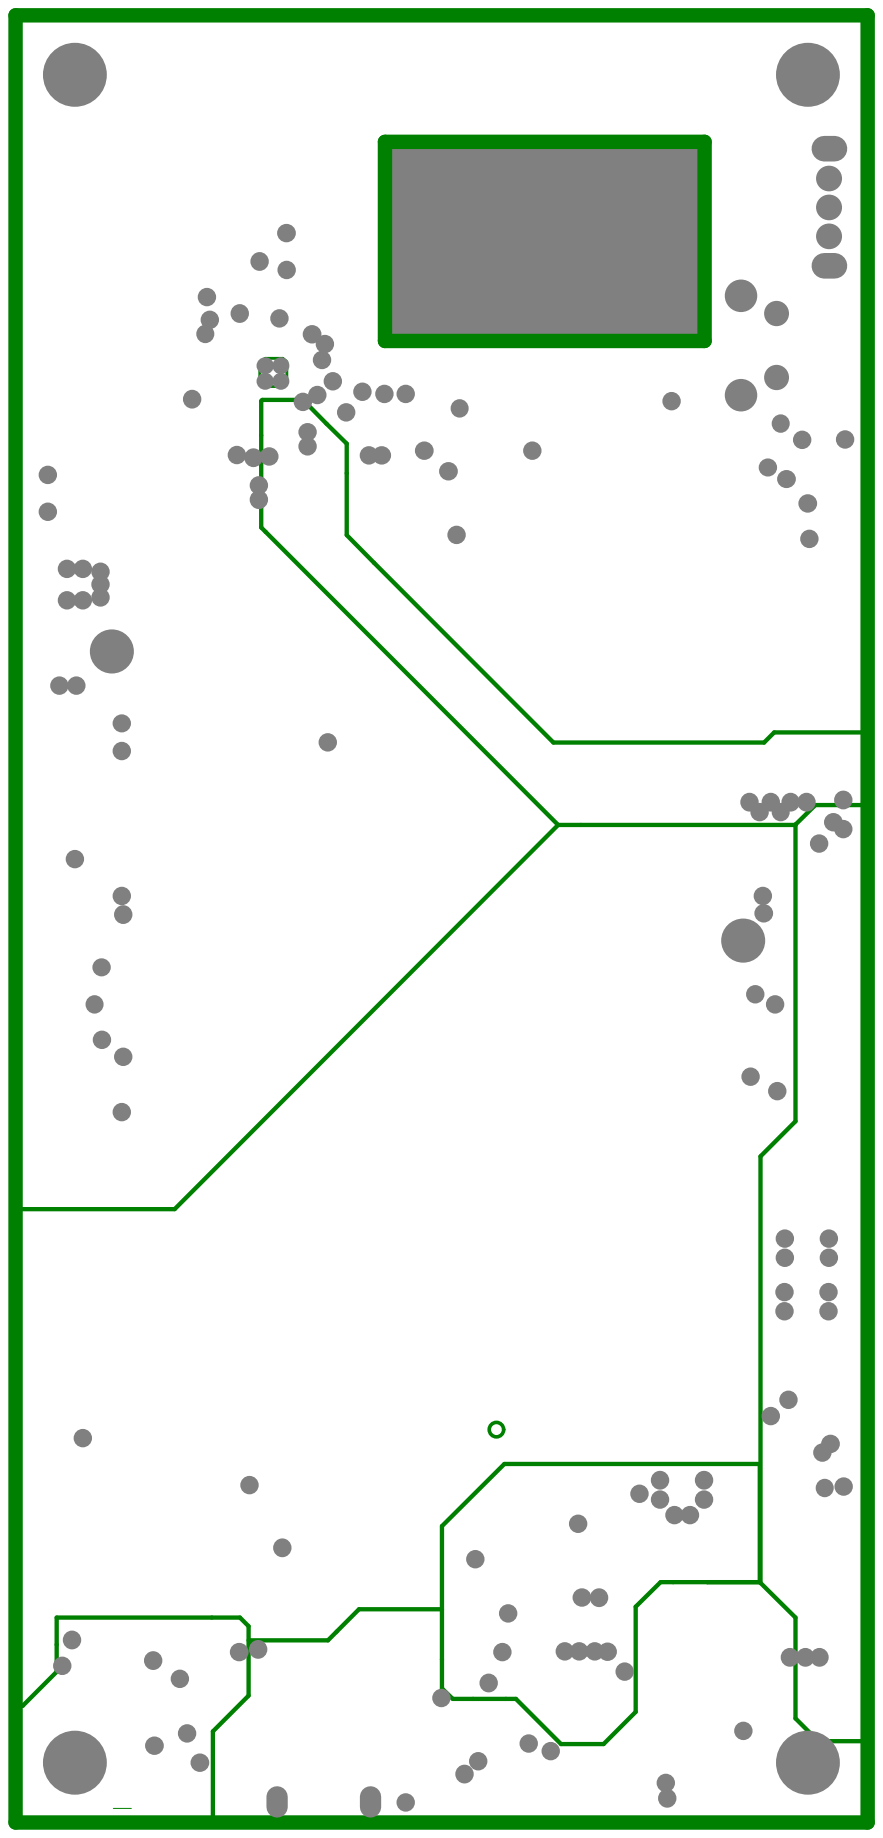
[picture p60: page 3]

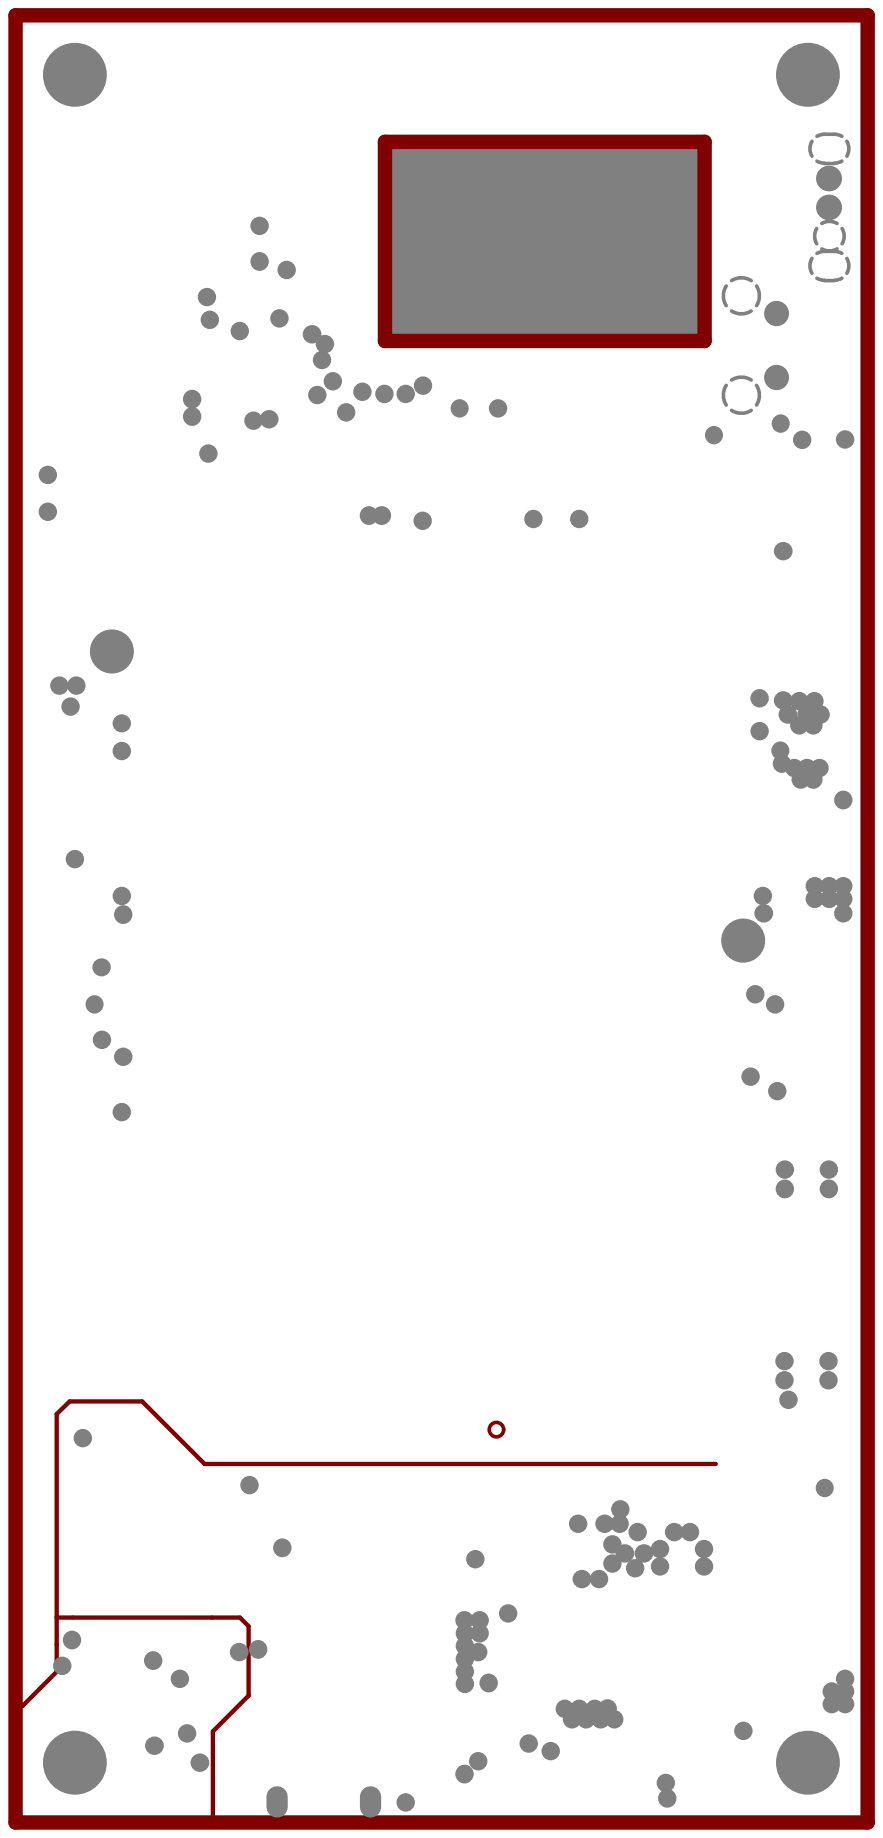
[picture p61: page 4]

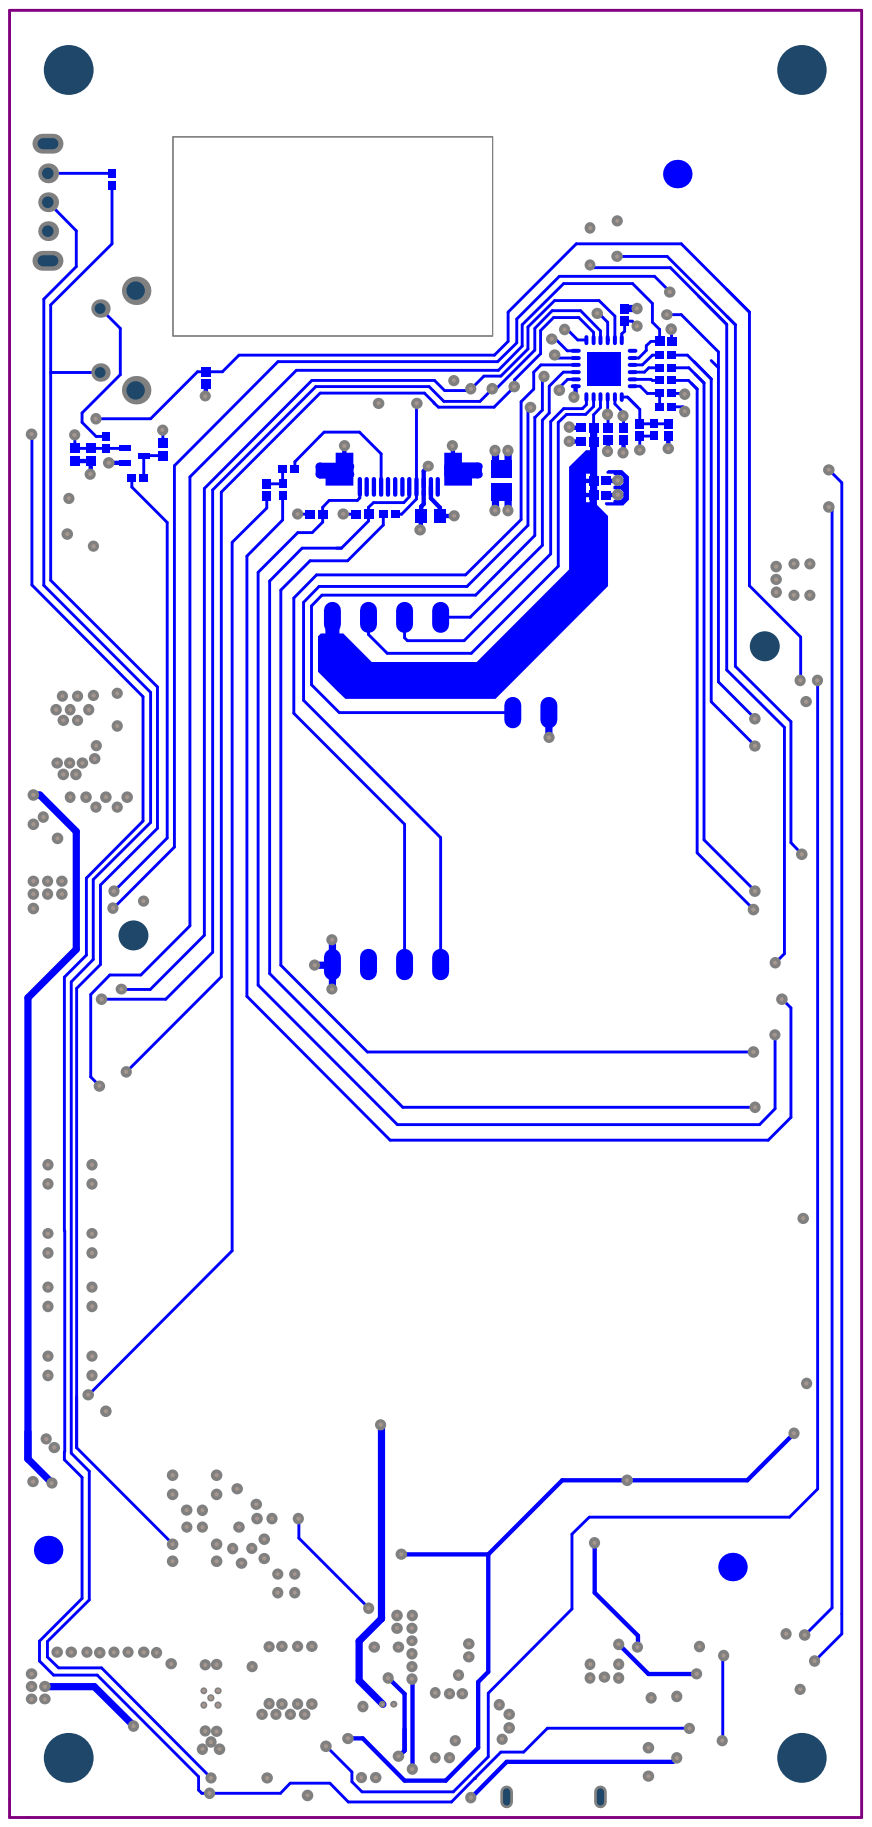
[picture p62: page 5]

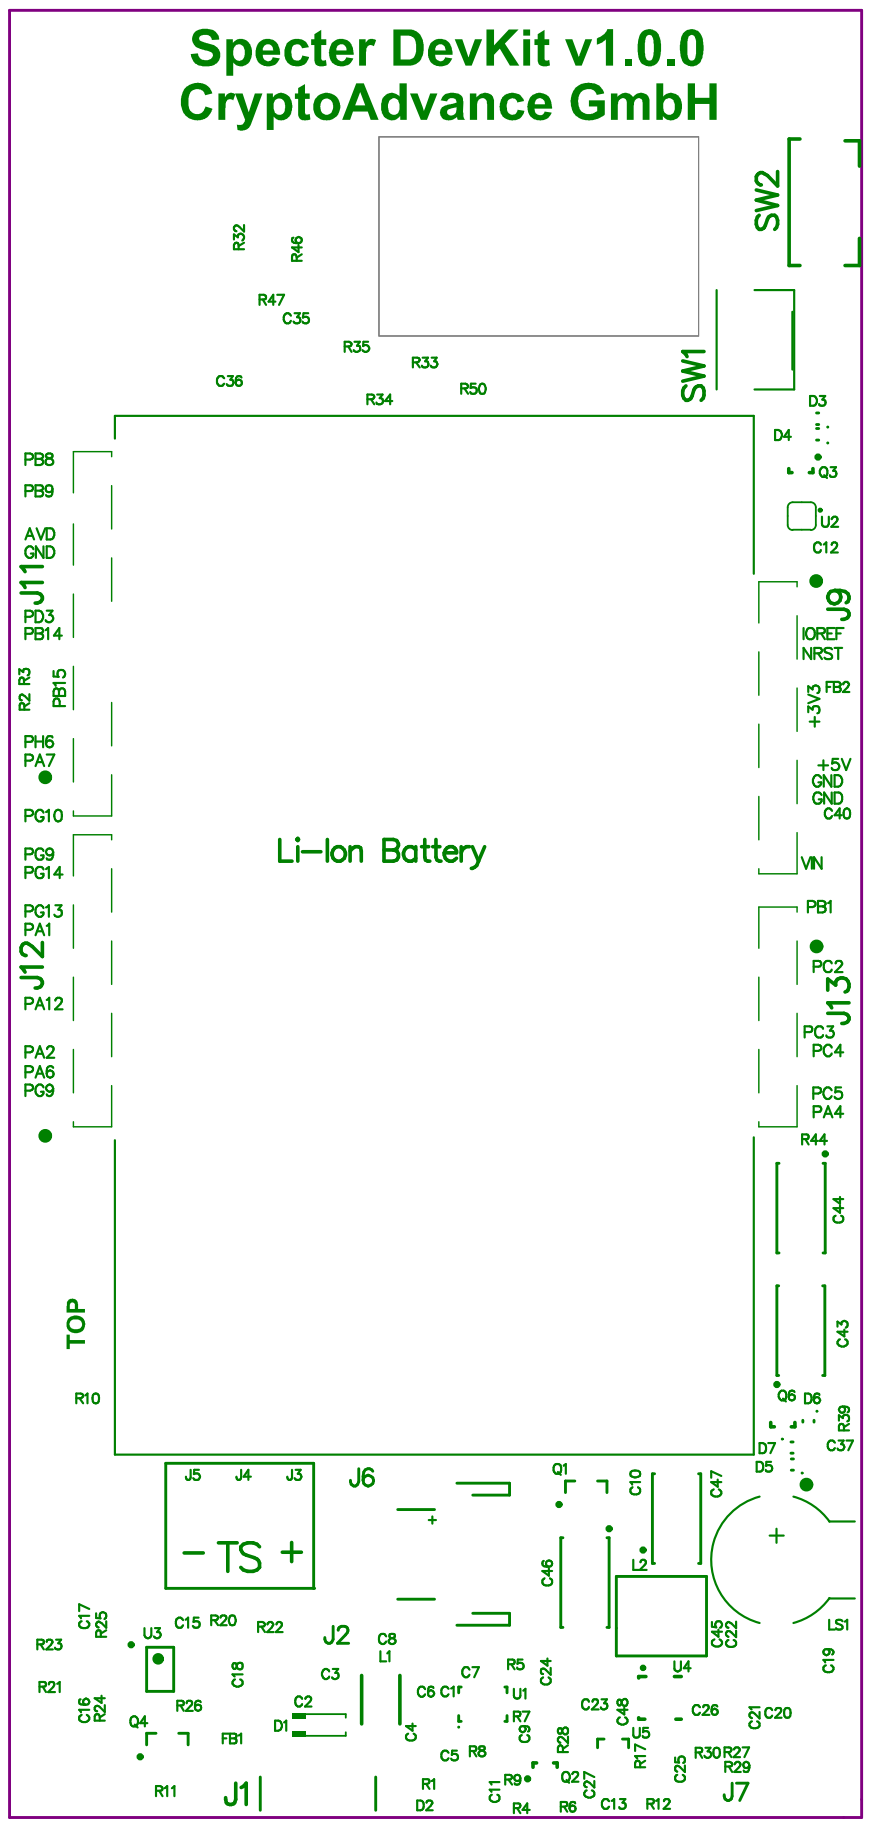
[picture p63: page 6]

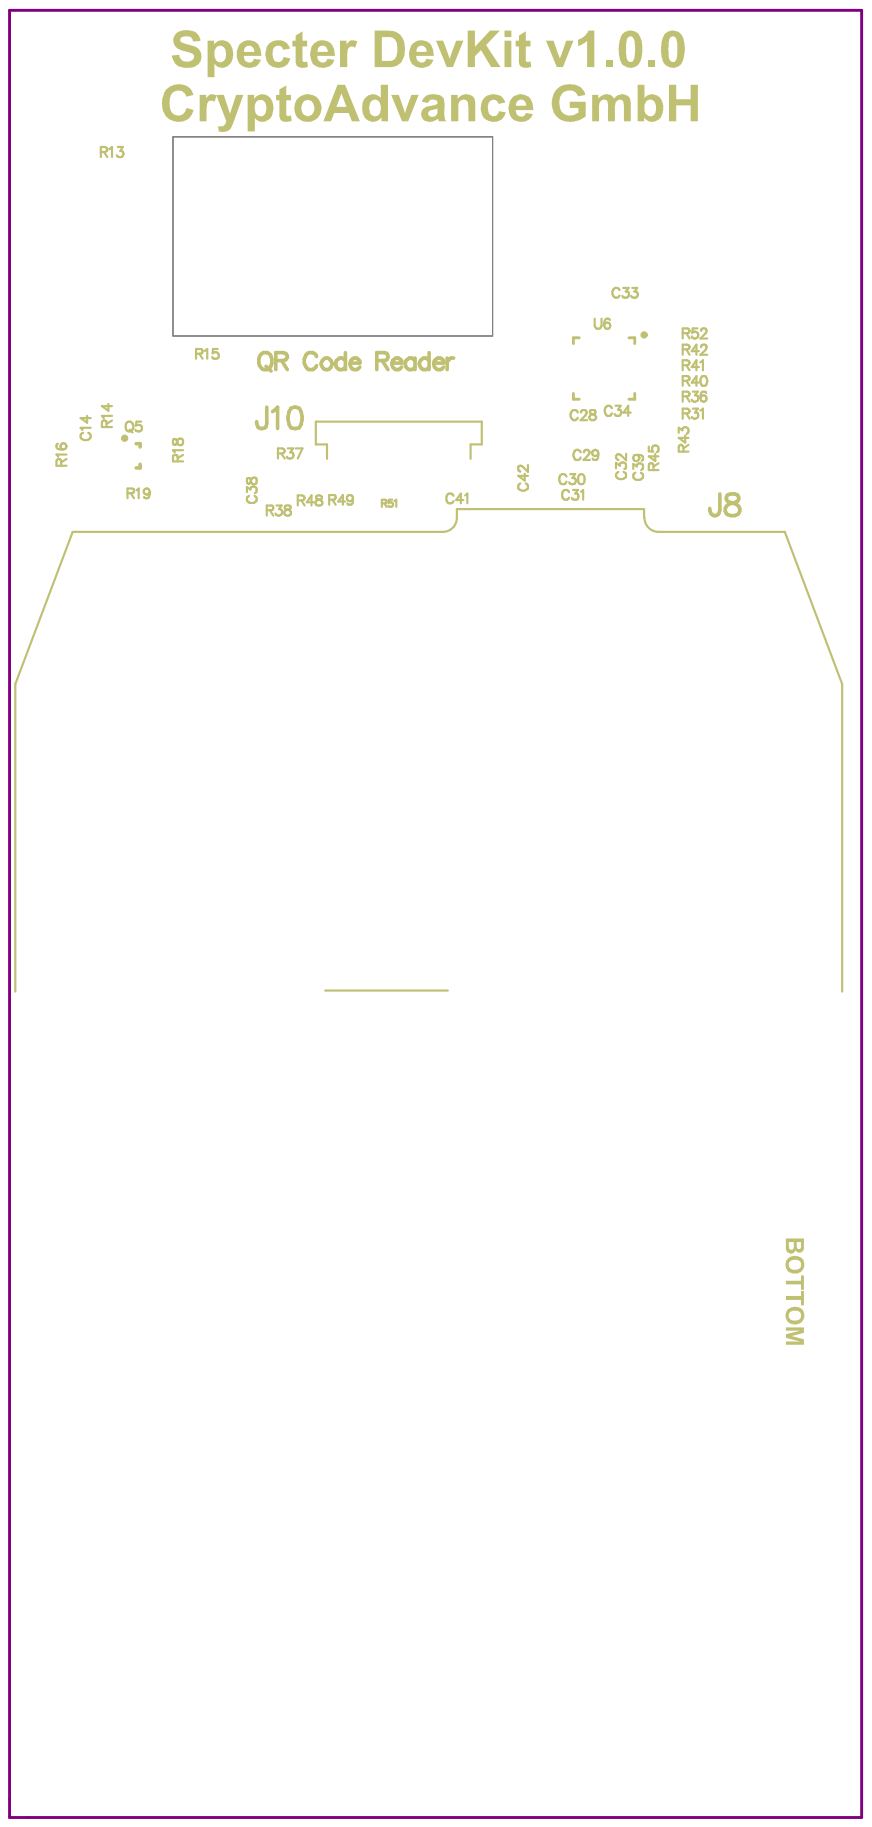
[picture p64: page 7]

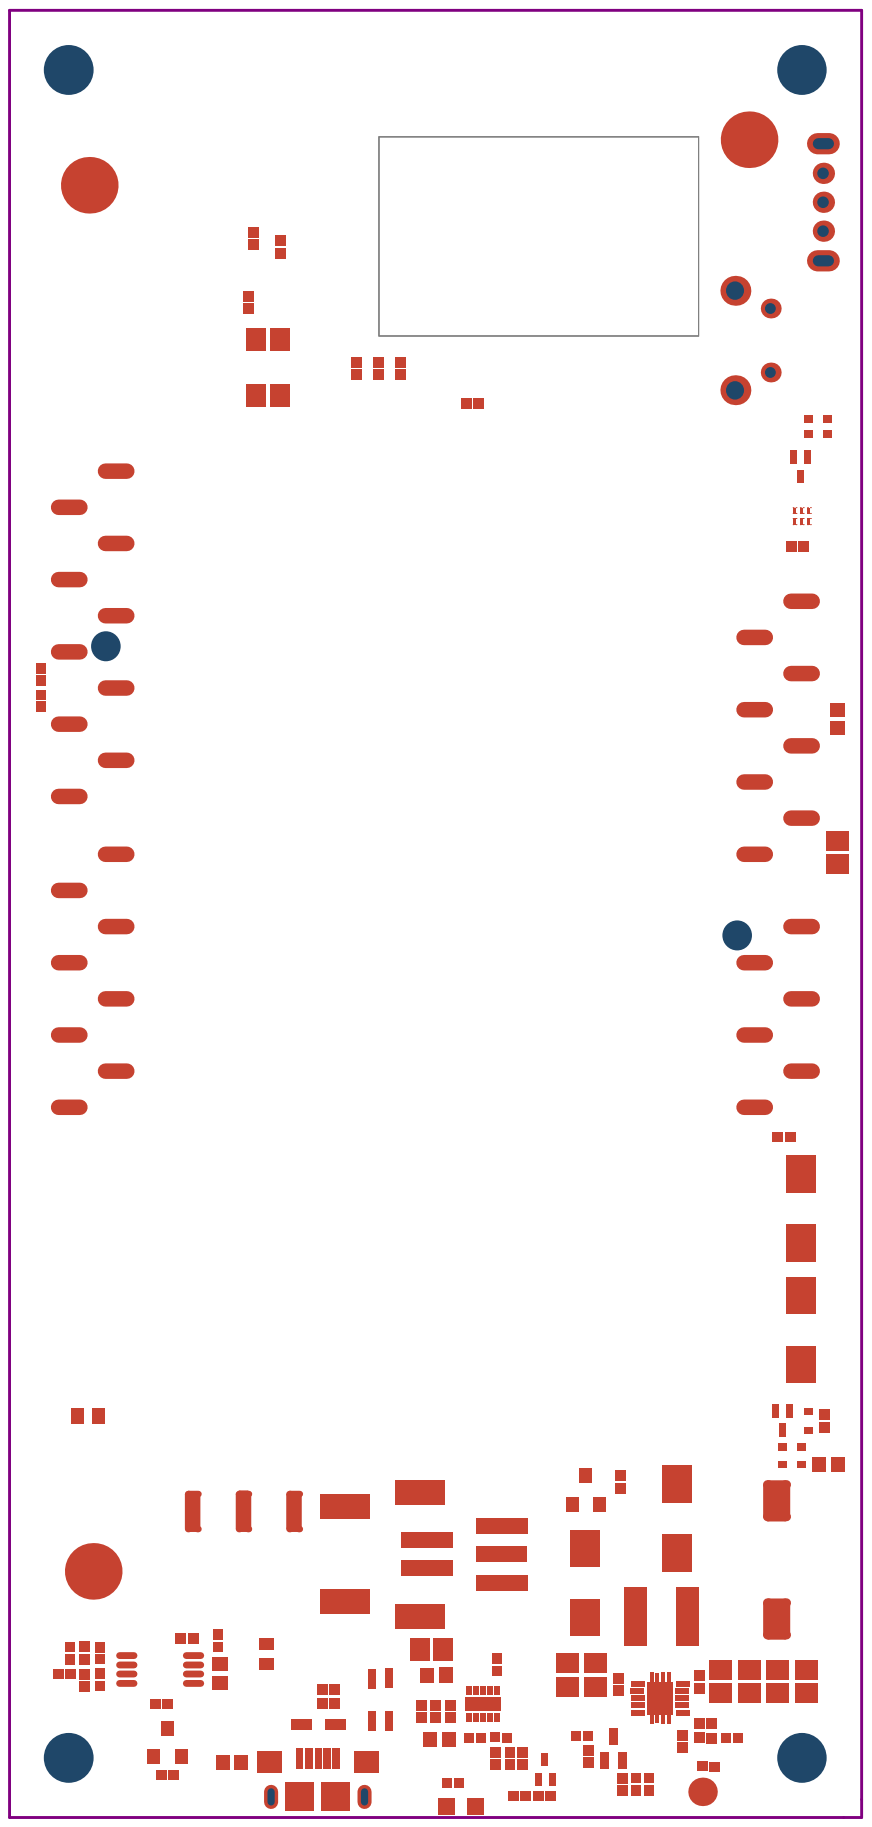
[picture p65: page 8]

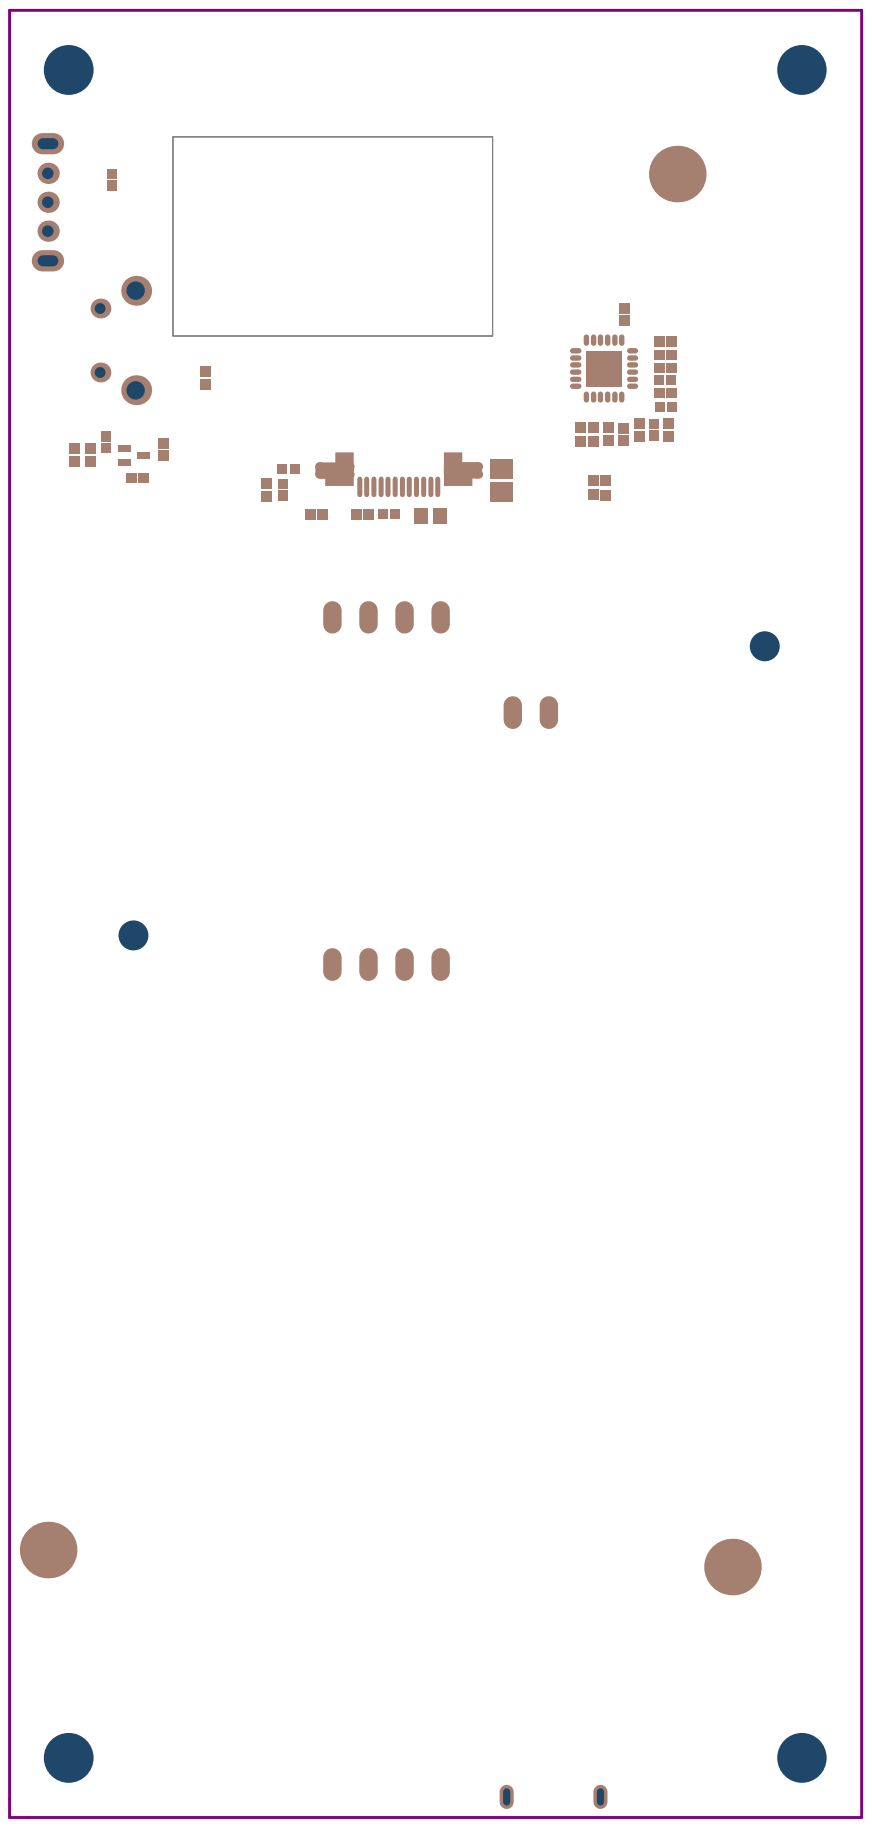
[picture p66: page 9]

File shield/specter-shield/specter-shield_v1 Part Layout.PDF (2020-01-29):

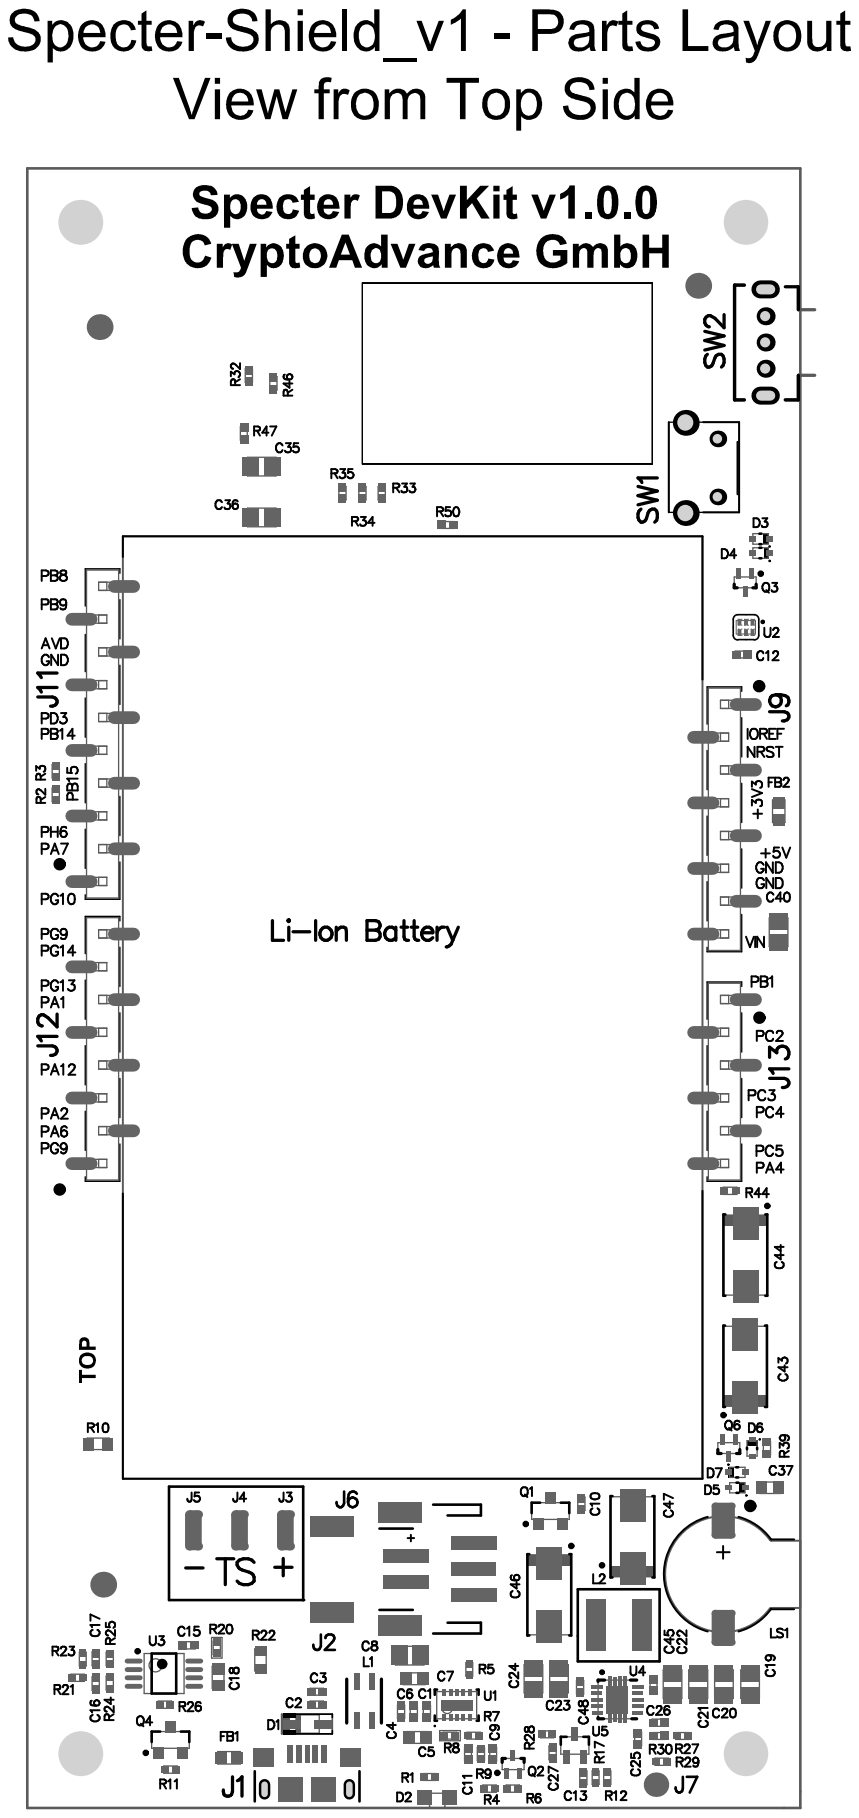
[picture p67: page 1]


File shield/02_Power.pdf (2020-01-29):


JST S3B-PH-SM4-TB(LF)(SN)


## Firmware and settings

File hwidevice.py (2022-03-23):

"""
Hardware Wallet Client Interface
********************************

The :class:`SpecterClient` is the class to communicate with Specter-DIY hardware wallet.
"""

import serial
import serial.tools.list_ports
import socket, time
from hwilib.hwwclient import *
from hwilib.errors import (
    ActionCanceledError,
    BadArgumentError,
    DeviceBusyError,
    DeviceFailureError,
    UnavailableActionError,
)
import hashlib
from binascii import a2b_base64, b2a_base64

py_enumerate = enumerate


class SpecterClient(HardwareWalletClient):
    """Create a client for a HID device that has already been opened.

    This abstract class defines the methods
    that hardware wallet subclasses should implement.
    """

    # timeout large enough to handle xpub derivations
    TIMEOUT = 3

    def __init__(self, path: str, password: str = "", expert: bool = False) -> None:
        """
        :param path: Path to the device as returned by :func:`~hwilib.commands.enumerate`
        :param password: A password/passphrase to use with the device.
            Typically a BIP 39 passphrase, but not always.
            See device specific documentation for further details.
        :param expert: Whether to return additional information intended for experts.
        """
        super().__init__(path, password, expert)
        self.simulator = ":" in path
        if self.simulator:
            self.dev = SpecterSimulator(path)
        else:
            self.dev = SpecterUSBDevice(path)

    def query(self, data: str, timeout: Optional[float] = None) -> str:
        """Send a text-based query to the device and get back the response"""
        res = self.dev.query(data, timeout)
        if res == "error: User cancelled":
            raise ActionCanceledError("User didn't confirm action")
        elif res.startswith("error: Unknown command"):
            raise UnavailableActionError(res[7:])
        elif res.startswith("error: "):
            raise BadArgumentError(res[7:])
        return res

    def get_master_fingerprint(self) -> bytes:
        """
        Get the master public key fingerprint as bytes.

        Retrieves the fingerprint of the master public key of a device.
        Typically implemented by fetching the extended public key at "m/0h"
        and extracting the parent fingerprint from it.

        :return: The fingerprint as bytes
        """
        return bytes.fromhex(self.query("fingerprint", timeout=self.TIMEOUT))

    def get_pubkey_at_path(self, bip32_path: str) -> ExtendedKey:
        """
        Get the public key at the BIP 32 derivation path.

        :param bip32_path: The BIP 32 derivation path
        :return: The extended public key
        """
        # this should be fast
        xpub = self.query("xpub %s" % bip32_path, timeout=self.TIMEOUT)
        hd = ExtendedKey.deserialize(xpub)
        # Specter returns xpub with a prefix
        # for a network currently selected on the device
        hd.version = b"\x04\x88\xb2\x1e" if self.chain == Chain.MAIN else b"\x04\x35\x87\xcf"
        return hd

    def sign_tx(self, psbt: PSBT) -> PSBT:
        """
        Sign a partially signed bitcoin transaction (PSBT).

        :param psbt: The PSBT to sign
        :return: The PSBT after being processed by the hardware wallet
        """
        response = self.query("sign %s" % psbt.serialize())
        signed_psbt = PSBT()
        signed_psbt.deserialize(response)
        # adding partial sigs to initial tx
        for i in range(len(psbt.inputs)):
            for k in signed_psbt.inputs[i].partial_sigs:
                psbt.inputs[i].partial_sigs[k] = signed_psbt.inputs[i].partial_sigs[k]
        return psbt

    def sign_message(self, message: Union[str, bytes], bip32_path: str) -> str:
        """
        Sign a message (bitcoin message signing).

        Signs a message using the legacy Bitcoin Core signed message format.
        The message is signed with the key at the given path.

        :param message: The message to be signed. First encoded as bytes if not already.
        :param bip32_path: The BIP 32 derivation for the key to sign the message with.
        :return: The signature
        """
        # convert message to bytes
        msg = message
        if isinstance(message, str):
            msg = message.encode('utf-8')
        # check if ascii - we only support ascii characters display
        try:
            msg.decode("ascii")
            fmt = "ascii"
        except:
            fmt = "base64"
        # check if there is \r or \n in the message
        # in this case we need to encode to base64
        if b"\r" in msg or b"\n" in msg:
            fmt = "base64"
        # convert to base64 if necessary
        if fmt == "base64":
            msg = b2a_base64(msg).strip()
        sig = self.query(f"signmessage {bip32_path} {fmt}:{msg.decode()}")
        return sig

    def display_singlesig_address(
        self,
        bip32_path: str,
        addr_type: AddressType,
    ) -> str:
        """
        Display and return the single sig address of specified type
        at the given derivation path.

        :param bip32_path: The BIP 32 derivation path to get the address for
        :param addr_type: The address type
        :return: The retrieved address also being shown by the device
        """
        if addr_type == AddressType.LEGACY:
            script_type = "pkh"
        elif addr_type == AddressType.SH_WIT:
            script_type = "sh-wpkh"
        elif addr_type == AddressType.WIT:
            script_type = "wpkh"
        else:
            raise BadArgumentError("Invalid address type")
        # prepare a request of the form like
        # `showaddr sh-wsh m/1h/2h/3 descriptor`
        request = f"showaddr {script_type} {bip32_path}"
        address = self.query(request)
        return address

    def display_multisig_address(
        self,
        addr_type: AddressType,
        multisig: MultisigDescriptor,
    ) -> str:
        """
        Display and return the multisig address of specified type given the descriptor.

        :param addr_type: The address type
        :param multisig: A :class:`~hwilib.descriptor.MultisigDescriptor` that describes the multisig to display.
        :return: The retrieved address also being shown by the device
        """
        # prepare a request of the form like
        # `showaddr sh-wsh m/1h/2h/3 descriptor`
        if addr_type == AddressType.LEGACY:
            script_type = "sh"
        elif addr_type == AddressType.SH_WIT:
            script_type = "sh-wsh"
        elif addr_type == AddressType.WIT:
            script_type = "wsh"
        else:
            raise BadArgumentError("Invalid address type")

        script, *_ = multisig.expand(0)
        bip32_path = multisig.pubkeys[0].origin.to_string()+multisig.pubkeys[0].deriv_path
        request = f"showaddr {script_type} {bip32_path} {script.hex()}"
        address = self.query(request)
        return address

    def close(self) -> None:
        # nothing to do for DIY
        pass

    ############ extra functions Specter supports ############

    def get_random(self, num_bytes: int = 32):
        if num_bytes < 0 or num_bytes > 10000:
            raise BadArgumentError("We can only get up to 10k bytes of random data")
        res = self.query("getrandom %d" % num_bytes)
        return bytes.fromhex(res)

    def import_wallet(self, name: str, descriptor: str):
        self.query("addwallet {name} {descriptor}")


def enumerate(password=""):
    """
    Returns a list of detected Specter devices
    with their fingerprints and client's paths
    """
    results = []
    # find ports with micropython's VID
    ports = [
        port.device
        for port in serial.tools.list_ports.comports()
        if is_micropython(port)
    ]
    for i in range(10):
        try:
            # check if there is a simulator on port 8789
            # and we can connect to it
            s = socket.socket(socket.AF_INET, socket.SOCK_STREAM)
            port = 8789+i
            s.connect(("127.0.0.1", port))
            s.close()
            ports.append("127.0.0.1:%d" % port)
        except Exception as e:
            print(e)
            pass

    for port in ports:
        # for every port try to get a fingerprint
        try:
            path = port
            data: Dict[str, Any] = {}
            data['type'] = 'specter'
            data['model'] = 'specter-diy'
            data['path'] = path
            data['needs_pin_sent'] = False
            data['needs_passphrase_sent'] = False
            client = SpecterClient(path, "", False)
            data["fingerprint"] = client.get_master_fingerprint().hex()
            client.close()
            results.append(data)
        except Exception as e:
            print(e)
    return results


############# Helper functions and base classes ##############


def is_micropython(port):
    return "VID:PID=F055:" in port.hwid.upper()


class SpecterBase:
    """Class with common constants and command encoding"""

    EOL = b"\r\n"
    ACK = b"ACK"
    ACK_TIMOUT = 3

    def prepare_cmd(self, data):
        """
        Prepends command with 2*EOL and appends EOL at the end.
        Double EOL in the beginning makes sure all pending data
        will be cleaned up.
        """
        return self.EOL * 2 + data.encode("utf-8") + self.EOL


class SpecterUSBDevice(SpecterBase):
    """
    Base class for USB device.
    Implements a simple query command over serial
    """

    def __init__(self, path):
        self.ser = serial.Serial(baudrate=115200, timeout=30)
        self.ser.port = path

    def read_until(self, eol, timeout=None):
        t0 = time.time()
        res = b""
        while not (eol in res):
            try:
                raw = self.ser.read(1)
                res += raw
            except Exception as e:
                time.sleep(0.01)
            if timeout is not None and time.time() > t0 + timeout:
                self.ser.close()
                raise DeviceBusyError("Timeout")
        return res

    def query(self, data, timeout=None):
        # non blocking
        self.ser.timeout = 0
        self.ser.open()
        self.ser.write(self.prepare_cmd(data))
        # first we should get ACK
        res = self.read_until(self.EOL, self.ACK_TIMOUT)[: -len(self.EOL)]
        # then we should get the data itself
        if res != self.ACK:
            self.ser.close()
            raise DeviceBusyError("Device didn't return ACK")
        res = self.read_until(self.EOL, timeout)[: -len(self.EOL)]
        self.ser.close()
        return res.decode()


class SpecterSimulator(SpecterBase):
    """
    Base class for the simulator.
    Implements a simple query command over tcp/ip socket
    """

    def __init__(self, path):
        arr = path.split(":")
        self.sock_settings = (arr[0], int(arr[1]))

    def read_until(self, s, eol, timeout=None):
        t0 = time.time()
        res = b""
        while not (eol in res):
            try:
                raw = s.recv(1)
                res += raw
            except Exception as e:
                time.sleep(0.01)
            if timeout is not None and time.time() > t0 + timeout:
                s.close()
                raise DeviceBusyError("Timeout")
        return res

    def query(self, data, timeout=None):
        s = socket.socket(socket.AF_INET, socket.SOCK_STREAM)
        s.connect(self.sock_settings)
        s.send(self.prepare_cmd(data))
        s.setblocking(False)
        # we will get ACK right away
        res = self.read_until(s, self.EOL, self.ACK_TIMOUT)[: -len(self.EOL)]
        if res != self.ACK:
            raise DeviceBusyError("Device didn't return ACK")
        # fetch with required timeout
        res = self.read_until(s, self.EOL, timeout)[: -len(self.EOL)]
        s.close()
        return res.decode()


###### test for communication ######

if __name__ == "__main__":
    import sys

    devices = enumerate()
    if len(devices) == 0:
        print("No devices found")
        sys.exit()
    inp = 0
    if len(devices) > 1:
        print("Found %d devices." % len(devices))
        for i, dev in py_enumerate(devices):
            print(f"[{i}] {dev['path']} - {dev['fingerprint']}")
        inp = -1
        while True:
            inp = int(input("Enter the device number to use: "))
            if inp >= len(devices) or inp < 0:
                print("Meh... Try again.")
                continue
            break
    dev = SpecterClient(devices[inp]["path"])
    if len(sys.argv) == 1:
        mfp = dev.get_master_fingerprint().hex()
        derivation = "m/84h/0h/0h"
        xpub = dev.get_pubkey_at_path(derivation).to_string()
        print(f"Device fingerprint: {mfp}")
        print(f"Segwit xpub: {xpub}")
        print(f"Full key: [{mfp}{derivation[1:]}]{xpub}")
    else:
        if "-i" not in sys.argv:
            cmd = " ".join(sys.argv[1:])
            print("Running command:", cmd)
            print(dev.query(cmd))
        else:
            cmd = ""
            print("Interactive mode! Enter `quit` to exit.")
            while inp != "quit":
                cmd = input("Enter command to run: ")
                if cmd == "quit":
                    sys.exit(0)
                try:
                    print(dev.query(cmd))
                except Exception as e:
                    print("Error:", e)

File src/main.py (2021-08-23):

import os
from specter import Specter
from gui.specter import SpecterGUI

from keystore.core import KeyStore
from keystore.sdcard import SDKeyStore
from keystore.memorycard import MemoryCard

from hosts import SDHost, QRHost, USBHost, Host
import platform
from helpers import load_apps
from app import BaseApp
import display

def main(apps=None, network="main", keystore_cls=None):
    """
    apps: list of apps to load
    network: default network to operate
    keystores: list of KeyStore classes that can be used
    """
    # Init display first as it also inits the SDRAM
    display.init(False)
    # create virtual file system /sdram
    # for temp untrusted data storage
    rampath = platform.mount_sdram()

    # set working path to empty folder in sdram
    if not platform.simulator:
        cwd = rampath+"/cwd"
        platform.maybe_mkdir(cwd)
        os.chdir(cwd)

    # define hosts - USB, QR, SDCard
    # each hosts gets it's own RAM folder for data
    Host.SETTINGS_DIR = platform.fpath("/qspi/hosts")
    Specter.SETTINGS_DIR = platform.fpath("/qspi/global")
    hosts = [
        USBHost(rampath + "/usb"),
        QRHost(rampath + "/qr"),
        SDHost(rampath+"/sd"),
    ]
    # temp storage in RAM for host commands processing
    BaseApp.TEMPDIR = rampath+"/tmp"

    # define GUI
    if not platform.simulator:
        gui = SpecterGUI()
    else:
        # this GUI can simulate user actions for automated testing
        from gui.tcp_gui import TCPGUI
        gui = TCPGUI()

    # inject the folder where keystore stores it's data
    KeyStore.path = platform.fpath("/flash/keystore")
    # detect keystore to use
    if keystore_cls is not None:
        keystores = [keystore_cls]
    else:
        keystores = [
            MemoryCard,
            SDKeyStore,
        ]

    # loading apps
    if apps is None:
        apps = load_apps()

    # make Specter instance
    settings_path = platform.fpath("/flash")
    specter = Specter(
        gui=gui,
        keystores=keystores,
        hosts=hosts,
        apps=apps,
        settings_path=settings_path,
        network=network,
    )
    specter.start()


if __name__ == "__main__":
    main()

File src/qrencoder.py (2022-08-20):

import math
from microur.util.bytewords import stream_pos
from microur.encoder import UREncoder
from bcur import bcur_encode_stream
from helpers import b2a_base64_stream, read_write

class QREncoder:
    """A simple encoder that just splits the data into chunks"""
    is_infinite = False
    MAX_PREFIX_LEN = 0

    def __init__(self, stream, part_len=300, tempfile=None):
        if tempfile is None:
            raise ValueError("Temp file is required for this encoder")
        with open(tempfile, "wb") as fout:
            self._start, self._len = self.convert(stream, fout)
        self.tempfile = tempfile
        self.f = None
        self._start = 0
        self._num = 0
        self.part_len = part_len

    def convert(self, fin, fout):
        # dummy convertion, just copy to the tempfile
        return 0, read_write(fin, fout)

    @property
    def part_len(self):
        return self._part_len

    @part_len.setter
    def part_len(self, part_len):
        if part_len > 2 * self.MAX_PREFIX_LEN:
            part_len -= self.MAX_PREFIX_LEN
        self._part_len = math.ceil(self._len / math.ceil(self._len / part_len))

    def get_full(self, maxlen=None):
        if maxlen is not None and maxlen < self._len:
            return ""
        self.f.seek(0, 0)
        return self.f.read()

    def __len__(self):
        return math.ceil(self._len / self.part_len)

    def __getitem__(self, idx):
        idx = idx % len(self)
        self.f.seek(self._start + idx*self.part_len, 0)
        return self.f.read(self.part_len)

    def __iter__(self):
        self._num = 0
        return self

    def __next__(self):
        if self._num >= len(self):
            raise StopIteration
        self._num += 1
        return self.__getitem__(self._num-1)

    def __enter__(self):
        if self.f is None:
            self.f = open(self.tempfile, "r")
        return self

    def __exit__(self, exc_type, exc_value, exc_tb):
        if self.f is not None:
            self.f.close()

    def __str__(self):
        return self.get_full()

class Base64QREncoder(QREncoder):
    MAX_PREFIX_LEN = 8

    def convert(self, fin ,fout):
        return 0, b2a_base64_stream(fin, fout)

    def __getitem__(self, idx):
        idx = idx % len(self)
        self.f.seek(self._start + idx*self.part_len, 0)
        return "p%dof%d %s" % (idx+1, len(self), self.f.read(self.part_len))

class LegacyBCUREncoder(QREncoder):
    MAX_PREFIX_LEN = 73 # uh... large one, and pretty useless

    def convert(self, fin ,fout):
        cur, sz = stream_pos(fin)
        sz, enc_hash = bcur_encode_stream(fin, fout, size=sz)
        self.enc_hash = enc_hash.decode()
        return 0, sz

    def get_full(self, maxlen=None):
        if maxlen is not None and maxlen < self._len+9:
            return ""
        self.f.seek(0, 0)
        return "UR:BYTES/" + self.f.read()

    def __getitem__(self, idx):
        if len(self) == 1:
            return "UR:BYTES/" + self.f.read()
        idx = idx % len(self)
        self.f.seek(self._start + idx*self.part_len, 0)
        return "UR:BYTES/%dOF%d/%s/%s" % (idx+1, len(self), self.enc_hash, self.f.read(self.part_len))

class CryptoPSBTEncoder(QREncoder):
    is_infinite = True
    MAX_PREFIX_LEN = 22

    def __init__(self, *args, **kwargs):
        self.encoder = None
        super().__init__(*args, **kwargs)

    def __len__(self):
        return self.encoder.seq_len

    def get_full(self, maxlen=None):
        return "" # we don't support full here yet

    def __enter__(self):
        super().__enter__()
        self.encoder = UREncoder(UREncoder.CRYPTO_PSBT, self.f, self._part_len)
        return self

    def __exit__(self, *args, **kwargs):
        del self.encoder
        super().__exit__(*args, **kwargs)

    def __getitem__(self, idx):
        return self.encoder.get_part(idx)

    @property
    def part_len(self):
        if self.encoder:
            return self.encoder.part_len
        else:
            return self._part_len

    @part_len.setter
    def part_len(self, part_len):
        if part_len > 2 * self.MAX_PREFIX_LEN:
            part_len -= self.MAX_PREFIX_LEN
        if self.encoder:
            self.encoder.part_len = part_len
            self._part_len = self.encoder.part_len
        else:
            self._part_len = math.ceil(self._len / math.ceil(self._len / part_len))

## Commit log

2019-09-06 touchscreen calibration fix
2019-09-06 readme fix - soldering required (((
2019-09-22 switched to libwally and big architecture refactor
2019-09-22 Update version of uBitcoin library
    Required for correct build fixing missing HDPrivateKey::fingerprint() method etc.
2019-09-22 docs folder, wiring instructions etc
2019-09-23 reckless storage - no pin, no encryption
2019-10-01 calibration error fix and zero fingerprint handling
2019-11-19 qr size and re fix
    [common.py, main.py]
2019-12-21 check pin
2020-01-09 factory reset: fix removing empty folders on stm32 platform
2020-01-24 keystore init fix and Miltisig typo
    [main.py]
2020-01-24 fix typo in set_default_xpubs
    [main.py]
2020-01-27 USB communication with the host (#35)
    usb host, sockets for qrscanner and usbhost in simulator, parsing usb commands
2020-01-28 handle keyboard button miss
2020-01-28 add pin shuffle and remove touch feedback
2020-01-29 Nonblocking GUI (#39)
    queues removed and fixed GUI to be non-blocking for easier testing & development
    [common.py, core.py, decorators.py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]
2020-01-29 Better docs (#36)
    docs refactoring, nicer pictures and a bit more instructions
    [Specter-shield_v1 - Layers Description.xls, specter-shield_v1 BOM.xlsx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]
2020-01-29 boot and interact with the board over REPL + docs
2020-02-03 fix cancel_scan to get back to main
    [main.py]
2020-02-21 keyboard hint for pressed button
2020-02-21 catch and display errors with gui
    [main.py]
2020-02-21 QR scanner in command mode and gallery of devices from the community
2020-02-24 better switch alignment
2020-02-24 docs and wrong derivate error
    [main.py]
2020-04-18 qrscanner: support pin triggered mode
2020-04-22 gui: move add_qrcode to avoid circular dependency for animated qrs
    [common.py]
2020-05-12 fix xpub request over usb
    [main.py]
2020-05-19 wallet: introduce variables to track the last receive and change address
2020-05-19 wallet: show first unused address and make space by moving buttons next to qrcode
2020-05-20 Remove super expensive miniusb cable link
2020-05-23 update shopping.md
    sed 's/powerbank, or a battery & power charger\/booster\. Then your wallet/powerbank or a battery & power charger\/booster, your wallet/'
2020-06-28 generic errors and some host updates
    [core.py, qr.py, specter.py]
2020-06-29 re-save devsettings when pin changes
2020-06-29 reboot when usb mode changes
    [platform.py, specter.py]
2020-06-30 minor hosts updates, wallet manager fix
    [core.py, main.py, platform.py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]
2020-07-02 add hwi driver
2020-07-04 add usb init, update hwi driver
2020-07-04 remove print
2020-07-04 move boot.py, fix mkdir for new wallet
    [boot.py, platform.py]
2020-07-09 add minimal main code for hwidevice, print what telnet ports are for in sumulator
2020-07-09 bump f469 - nonblocking tcp socket on unixport
2020-07-13 fix sign long messages
    [main.py]
2020-07-15 allow configs, fix qr cancel
    [platform.py, qr.py]
2020-07-19 fix navigation in settings
    [specter.py]
2020-08-01 move pin management to keystore
2020-08-25 Support bc-ur encoding of the PSBT transactions (#76)
    * add bcur encoding module
    * add bcur encoding module
    * support bcur signing and animated display
    * decrease rate, capitalize OF
    * fix fee calculation
    [qr.py]
2020-08-31 Add device label app (#77)
2020-08-31 fix hwidevice interactive mode (#78)
    [hwidevice.py]
2020-09-23 fix smartcard on hardware
    [boot.py]
2020-09-23 fix smartcard PIN check on hardware
2020-09-25 fix sdcard switching
2020-09-25 support dynamic smartcard replacement
    [main.py]
2020-09-29 fix network loading, use keystore if only one passed
    [specter.py]
2020-09-30 remove PIN menu items if keystore doesn't have lock() method
    [specter.py]
2020-09-30 disable one more PIN-related menu if keystore doesn't support it
    [specter.py]
2020-10-17 allow fixing invalid mnemonic
    [specter.py]
2020-10-19 correct name and add link to 3d printed box for storage
    Keep it all exposed, but protect from dust and other environment degradation
2020-11-26 handle properly loader and wrong smartcard (#105)
    [async_gui.py]
2020-11-30 add 3d printed enclosure pic
2020-12-03 Add 3d printed case instructions and files (#110)
2021-01-14 switch to memory-optimized qr codes
2021-01-14 move poweroff to scheduler
2021-01-15 require PIN for mnemonic screen
2021-01-18 add circuitmaker link for the shield
2021-01-19 handle qr-uart better
2021-01-19 properly handle missing pin file
2021-01-20 fix is_ready for smartcard, bump version
    [boot.py]
2021-01-25 add battery monitor
2021-03-19 fix PIN verification bug
    [platform.py]
2021-03-23 Added Alternative 3D Design & Instructions (#124)
    [01_Main_Body.stl, 02_Top_Panel.stl, 03_Bottom_Panel.stl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]
2021-03-25 increase PIN font size
2021-03-25 more tests and fixes
    [usb.py]
2021-03-25 check xpubs versions on wallet import against current network
2021-03-28 Reserve sector 1 for key storage on STM32F469
    Also add FLAVOR variable to Makefile
2021-04-28 add Amazon pins
    If you're already buying the board from mouser it makes sense to get the pins from them, but if for people in the US who need long pins this is an Amazon prime option.
    For example, I didn't buy pins because I already had some, but they were regular length which was too short. These Amazon pins worked well enough.
2021-05-09 Added cancel button for pin change (#146)
2021-05-27 add 3d case designs
2021-05-28 Update 01_Main_Body.stl (#152)
    Slight modification to design to accommodate manufacturing variations in DISCO board
    [01_Main_Body.stl]
2021-06-08 Moved the show recovery phrase button one level higher to the settings screen.
2021-06-09 cleanup of storage_menu for keystores + checks whether storage_menu and show_mnemonic are available to control display of respective buttons
2021-06-17 add enclosure variants
    [DIY-Front-Display-v0.12.stl, DIY-Platte-v0.21.stl, Scan_case-v0.2.stl]
2021-06-19 mount sd before file_exists (#164)
2021-07-09 Update SeedSigner Case Info (#166)
    [Barebones_DIY_OpSec_Bottom_v1.stl, Barebones_DIY_OpSec_Top_v1.stl]
2021-08-24 enclosure (#175)
2021-08-24 add bw hack with zero fingerprint (#176)
2021-09-02 Add v2 of Barebones Enclosure (#183)
    Add second version of Specter-DIY "Barebones" 3D-printable enclosure to the repo.
    [BBv1_Lower.stl, BBv1_Upper.stl, BBv2_Lower.stl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]
2022-07-10 ur:crypto-psbt support (#208)
    experimental support. sometimes fails for large txs or fast QR repetition rate
    [qr.py, specter.py]
2022-07-10 bump version, fix tests
    [boot.py, util.py]
2022-07-10 fix back btn when import mnemonic
    [specter.py]
2022-08-20 fix processing of \r when importing binary seedqr (#213)
    [core.py, qr.py, sd.py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]
2022-08-20 complete rewrite of QR GUI component (#214)
    * add qrencoder classes
    * update ur2 encoder to support zoom in/out
2022-11-05 add support for revc board
2022-11-11 Add photos of a Specter DIY build with the original packaging of the STM32F469I-DISCO + a few minor adjustments to the docs. (#227)
    * Shopping: Explicit specify that 4 pin headers needed
    * Docs/Shopping: Without scanner the Specter can be used with USB + SD Card
    * Added photos of a Specter DIY reusing the original packaging of the STM32F469I-DISCO.
2022-11-14 Adding new enclosure: snap case (#228)
    [Specter DIY Snap Case - Bottom Part.stl, Specter DIY Snap Case - Middle Part.stl, Specter DIY Snap Case - Top Part.stl]
2022-11-16 add fingerprint to processed SD filename
2022-12-27 Update Snap Case STL files (#247)
    [Specter DIY Snap Case - Middle Part.stl, Specter DIY Snap Case - Top Part.stl]
2023-01-22 Update Snap Case STL files (#250)
    - Give some more space for audio, micro usb and board stilts.
    - Use a 45-degree chamfer instead of a rounding to make printing easier.
    - Move one cable tunnel from scanner part slightly.
    [Specter DIY Snap Case - Bottom Part.stl, Specter DIY Snap Case - Middle Part.stl, Specter DIY Snap Case - Top Part.stl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]
2023-12-03 Add feature to export multiple accounts XPub keys (#258)
    * Add feature to export multiple accounts XPub keys
    * Apply suggestions from code review
    still need to do a few modifs and test them.
    * refactor pr to avoid code duplication
    ---------
    [helpers.py, platform.py]
2023-12-08 add bip85 app (#265)
    * add bip85 app
    * save to SD, load mnemonic to device
2023-12-10 show slip132 switch only if keys have slip132 repr (#268)
2023-12-10 Only show frameindex when displaying an animated QR code if the mode is not infinite (to avoid showing the frameindex in crypto-psbt mode where it does not make sense). (#240)
2024-04-13 Correct contact details of Snap Case enclosure
2024-04-13 ask for overwrite if something on smartcard (#270)
    * ask for overwrite if something on smartcard
    * fix: only show success screen if user did not cancel
    * add warning style
    * add warning option to prompt class
    * improve copy on overwriting data screen + add warning text
    * add icon to Prompt and add warning icon if there is a warning
    * rename key_saved to data_saved + change copy to "Card has data"
    * fix: initialize an empty icon label
    * make "Keep as plain text" the CTA btn and change copy to explain the risks of encrypting the secret with device
    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
    [common.py]
2025-10-07 chore: Get build back to work and some CI (#307)
    * fix: pin dependencies via on nix and create flake
    * ci: try build
    * Update flake.nix
    * Update shell.nix
    * fix: as suggested by mike
    * a bit more concrete prerequisites
    * nix prefixes
    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
2025-11-27 Change button text from 'Enter BIP-39 password' to 'Enter passphrase' (#327)
2025-11-27 Fix for newer GM65 Scanners scanning CompactSeedQR + Add "About Screen" (#299)
    [boot.py, platform.py, qr.py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]
2025-12-22 Add full M3Y support and fix QR scanning issues for GM65 and M3Y (#335)
    - Implement full M3Y scanner support (light, aim, sound, read/stop commands,
    serial mode, high-speed baudrate, and factory reset)
    - Improve QR data reading with end-of-line validation to ensure complete frames
    - Fix scanners stopping while reading animated QR codes
    - Fix GM65 failing to read single large QR codes by increasing UART buffer
    from 2048 to 4096 bytes
    - Fix rare LVGL recolor markup line-break issue in animated Specter pMofN QR
    progress that caused hex color codes (e.g. 00F100) to render incorrectly
    Closes #314
    [qr.py]
2026-01-25 Fix #329: Hide disabled QR scanner in recovery phrase import menu (#338)
    [specter.py]
2026-02-10 Fix: minor comment cleanups (#343)
    [usb.py]
